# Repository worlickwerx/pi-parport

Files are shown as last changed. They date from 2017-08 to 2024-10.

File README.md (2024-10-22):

## pi-parport

This is a Raspberry Pi HAT that implements a PC-style parallel port.
GPIO pins are organized as data, status, and control registers.
The HAT includes a buffer chip that converts from the GPIB 3V3 logic
to signals that conform to IEEE 1284.  A 26 pin IDC header on the
board connects to your DB25 connector.  A `parport-gpio` driver and
device tree overlay integrate the HAT with the Linux parport driver stack.

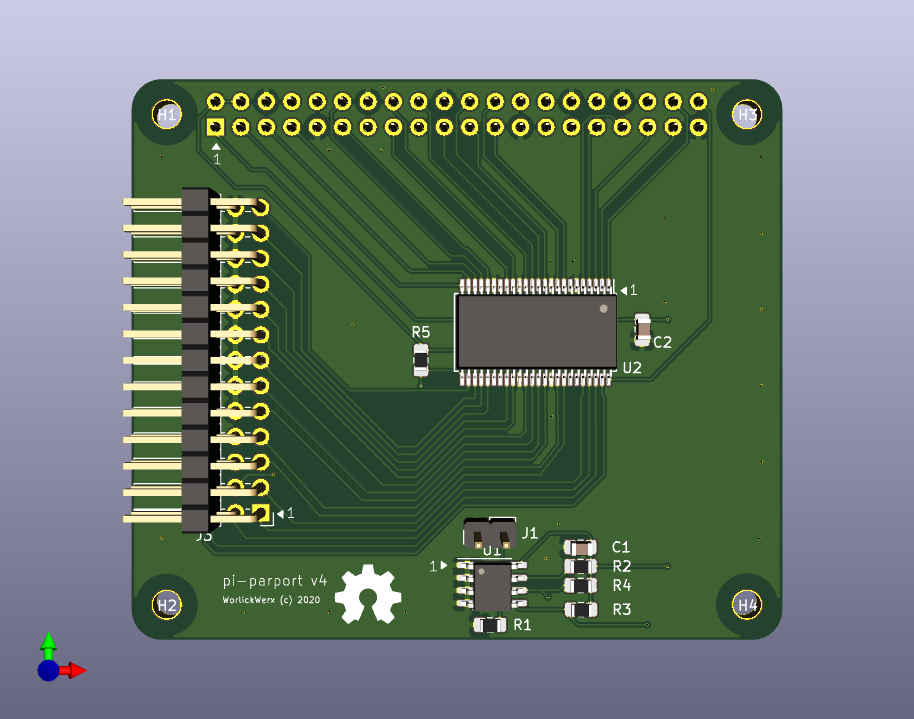
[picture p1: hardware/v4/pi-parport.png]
Image of pi-parport latest


### Why?

I wanted to use a parallel port based cooled astronomy camera,
but preferred to use the compact and low-power Raspberry Pi
over a PC at the telescope.  Parallel ports are simple devices.
Why not build one?

### What works?

See [wiki](https://github.com/worlickwerx/pi-parport/wiki) for notes on some
devices, and please share your experience if you try something new.

The following limitations of this implementation may affect software and
hardware that uses the parallel port:
1) The software cannot directly read and write the x86 port addresses,
as was the custom early on.  In user space, software must use the ppdev
ioctl interface.  In the kernel, software must use the (generic)
`struct parport` operations.
2) The GPIO multiplexing/de-multiplexing and/or system call access may
impact the direct-access latency assumed by some bit-banged drivers.
On a Pi 3, user space code can toggle a parallel port line at about 250 kHz.
3) Bidirectional control pins are not currently supported, but bidirectional
data pins are supported.  There are alternatives to the current buffer chip
that would support this, but they require a slightly more complicated
circuit.

### Why not use a USB Parallel Port?

Many USB parallel port devices appear to Linux as a USB printer, bypassing
the parport driver stack.  If your application is a printer, go for it.

### Building the driver

For convenience, the generic parport code is duplicated in this repo,
since the Raspberry Pi Foundation does not ship the compiled modules
in the `raspberrypi-kernel` package (at least in old Raspbian
versions).  If you are intending to use a specific old version of
Raspbian, there is the shell script `get_parport_src.sh` to assist
you in getting the code from that particular version.

Clone this repo, then run the following with `${TOPDIR}` representing the
top level directory of the cloned repo:
```console
$ sudo apt install build-essential raspberrypi-kernel-headers
$ cd ${TOPDIR}/driver
$ make
make -C /lib/modules/4.19.75-v7+/build M=${TOPDIR}/driver modules
make[1]: Entering directory '/usr/src/linux-headers-4.19.75-v7+'
  CC [M]  ${TOPDIR}/driver/parport/share.o
  CC [M]  ${TOPDIR}/driver/parport/ieee1284.o
  CC [M]  ${TOPDIR}/driver/parport/ieee1284_ops.o
  CC [M]  ${TOPDIR}/driver/parport/procfs.o
  CC [M]  ${TOPDIR}/driver/parport/daisy.o
  CC [M]  ${TOPDIR}/driver/parport/probe.o
  LD [M]  ${TOPDIR}/driver/parport/parport.o
  CC [M]  ${TOPDIR}/driver/parport/lp.o
  CC [M]  ${TOPDIR}/driver/parport/ppdev.o
  CC [M]  ${TOPDIR}/driver/parport_gpio.o
  Building modules, stage 2.
  MODPOST 4 modules
  CC      ${TOPDIR}/driver/parport/lp.mod.o
  LD [M]  ${TOPDIR}/driver/parport/lp.ko
  CC      ${TOPDIR}/driver/parport/parport.mod.o
  LD [M]  ${TOPDIR}/driver/parport/parport.ko
  CC      ${TOPDIR}/driver/parport/ppdev.mod.o
  LD [M]  ${TOPDIR}/driver/parport/ppdev.ko
  CC      ${TOPDIR}/driver/parport_gpio.mod.o
  LD [M]  ${TOPDIR}/driver/parport_gpio.ko
make[1]: Leaving directory '/usr/src/linux-headers-4.19.75-v7+'
```

### Installing the Device Tree Overlay

The device tree overlay maps specific GPIO pins to their functions in
the driver.  This must be compiled and loaded:
```console
$ cd ${TOPDIR}/dts
$ make
$ sudo make install
```
The ID EEPROM stores the name of the DT Overlay to use, and the
corresponding DT Overlay will be automatically loaded on boot.  If you
will not be using an ID EEPROM, then add the following line to
`/boot/config.txt`:
```
dtoverlay=parport-gpio
```
The default drive mode of the parallel port output pins is
"totem-pole" mode, which means that a high current source is provided
for both logic level 1 and 0.  If you wish logic level 1 to be a low
current source provided by pull-up resistors, i.e. "open-drain" mode,
then you can set the following DT Overlay parameter:
```
dtoverlay=parport-gpio,hd=0
```
Note that if you are using an EEPROM, you will have to include the
full DT Overlay data within your EEPROM since you cannot simply
specify a parameter when loading by that method.

Then reboot the pi to pick up the new config.

### Installing the Modules

Install the modules to allow Linux Device Tree to automatically load
them.
```console
$ cd ${TOPDIR}/driver
$ sudo make install
```
Note that only the `parport` and `parport_gpio` base modules will
autoload, the `ppdev` and `lp` modules will still need to be specified
in `/etc/modules` or otherwise.  Also, note that you will need to
rebuild and reinstall the modules when you update your kernel version.

### Loading the Modules

If you did not install the modules, after rebooting, load the base
modules like this:
```console
$ cd ${TOPDIR}
$ sudo insmod driver/parport/parport.ko
$ sudo insmod driver/parport_gpio.ko
```
You'll see the port announce itself on the console:
```console
[4425200.988400] parport-gpio ppgpio@0: data on pins [22,23,24,10,25,9,8,11]
[4425200.988412] parport-gpio ppgpio@0: status on pins [18,17,4,3,2]
[4425200.988422] parport-gpio ppgpio@0: control on pins [26,19,6,13]
[4425200.988430] parport-gpio ppgpio@0: hd on pin 20
[4425200.988438] parport-gpio ppgpio@0: dir on pin 21
```
If you wish to set up a parallel printer:
```console
$ sudo insmod parport/lp.ko
```
If you wish to run user-space programs that use the parallel port:
```console
$ sudo insmod parport/ppdev.ko
```

### hardware

The latest hardware includes an ID EEPROM to conform with the
[Raspberry Pi HAT Specification](https://github.com/raspberrypi/hats),
and was designed with [KiCAD](https://www.kicad.org/).
As with the previous versions, the
[SN74LVC161284 19-bit bus interface with 3-state outputs](http://www.ti.com/product/SN74LVC161284) takes care of buffering and line conditioning.

Version 4 is shared on
[OSHPARK](https://oshpark.com/shared_projects/0Ioh20Gk).
See the [Bill of Materials](hardware/v4/BOM.md) for parts to place on
the board.

Populating the EEPROM and associated components on a board you're making
yourself is optional.

Check out the [test](test/) directory for some simple "smoke tests"
on your assembled pi-parport board before attaching your more
expensive equipment.

Schematics and design files for [previous versions](hardware/)
are still available for reference.

### Release

Share and enjoy!

#### Software License

SPDX-License-Identifier: GPL-2.0-or-later

#### Hardware License

SPDX-License-Identifier: CERN-OHL-1.2

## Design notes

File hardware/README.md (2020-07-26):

### v4 hardware

v4 mainly corrects some minor flaws in the v3 design.  Bypass
capacitors are added, a few traces are rerouted to avoid passing under
resistors, and the footprints for the EEPROM resistors are changed
from 0603 to 0805.  Also, a few CAD-related inconsistencies were
fixed, like unclosed board outline and footprints not being consistent
between the schematic and board layout files.

[Schematic](v4/pi-parport.pdf) and [Bill of Materials](v4/BOM.md).

### v3 hardware

v3 adds an EEPROM to be a proper HAT.  It also converts the design files 
from Eagle to KiCad as a step to making additional board variations and 
modifications more accessible.  Unfortunately, bypass capacitors were 
left out of the redesign.

This board is shared on [OSHPARK](https://oshpark.com/shared_projects/gevwv2YP).
See also:  [Schematic](v3/pi-parport.pdf) and [Bill of Materials](v3/BOM.md).

### v2 hardware

v2 addresses the line termination and data direction limitations of v1,
using a single, purpose-built chip, the
[SN74LVC161284 19-bit bus interface with 3-state outputs](http://www.ti.com/product/SN74LVC161284).

This board was designed with Eagle, and is shared on
[OSHPARK](https://oshpark.com/shared_projects/Padn3qhP).
See also: [Schematic](v2/schematic.pdf) and [Bill of Materials](v2/BOM.md).

It works!  However, it doesn't conform to the HAT specification because
of the lack of EEPROM, and the IDC connector footprint is for a vertical
connector, but right angle would have helped the Pi fit into smaller cases.
(RA works, but it hangs over the board edge).

### v1 hardware

Three
[74AHCT541 octal buffers/drivers with 3-state outputs](http://www.ti.com/product/SN74AHCT541)
chips convert to/from the Pi's 3V3 line level and the parallel port's 5V.

This board was designed with Eagle.  See also: [Schematic](v1/schematic.pdf).

This version worked for my intended application (SBIG parallel port camera),
but due to missing line termination, only with a very short cable.  This
design also does not implement bidirectional DATA.

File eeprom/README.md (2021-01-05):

### ID EEPROM

Install J1 (or solder a zero-ohm resistor in R1) to defeat EEPROM
write protect.

To use and program your EEPROM, ensure that `/etc/modules` contains
`i2c-dev`.  This is normally the case if you have a full installation
of Raspbian, but if you've opted for a lite installation or a
different operating system, this line might be missing.  Add it and
ensure the module is loaded by typing `sudo modprobe i2c-dev`.

Edit `/boot/config.txt`, adding this line temporarily so the ID bus is visible
after boot, and reboot:
```
# Enable ID EEPROM temporarily
dtparam=i2c_vc=on
```

Verify EEPROM is found on bus 0 at address 50
```console
$ sudo apt install i2c-tools
$ i2cdetect 0
WARNING! This program can confuse your I2C bus, cause data loss and worse!
I will probe file /dev/i2c-0.
I will probe address range 0x03-0x77.
Continue? [Y/n] y
     0  1  2  3  4  5  6  7  8  9  a  b  c  d  e  f
00:          -- -- -- -- -- -- -- -- -- -- -- -- --
10: -- -- -- -- -- -- -- -- -- -- -- -- -- -- -- --
20: -- -- -- -- -- -- -- -- -- -- -- -- -- -- -- --
30: -- -- -- -- -- -- -- -- -- -- -- -- -- -- -- --
40: -- -- -- -- -- -- -- -- -- -- -- -- -- -- -- --
50: 50 -- -- -- -- -- -- -- -- -- -- -- -- -- -- --
60: -- -- -- -- -- -- -- -- -- -- -- -- -- -- -- --
70: -- -- -- -- -- -- -- --
```

Make the HAT EEPROM utils and copy `eepmake`, `eepdump`, and `eepflash.sh`
somewhere in your PATH (like `/usr/local/bin`).
```console
$ git clone https://github.com/raspberrypi/hats.git
$ cd hats/eepromutils
$ make
$ sudo cp eepflash.sh eepdump eepmake /usr/local/bin/
```

Back in this directory, make the image and flash the chip:
```console
$ make VERSION=0x0004
eepmake board.txt board.eep overlay_name.txt
Opening file board.txt for read
UUID=3691bbab-1f52-42c7-9cac-01fc81d12688
Done reading
Opening DT file overlay_name.txt for read
Adding 13 bytes of DT data
Writing out...
Writing out DT...
Done.
$ make flash
sudo eepflash.sh -w -f=board.eep -t=24c32 -d=0 -a=50
This will attempt to talk to an eeprom at i2c address 0x50 on bus 0. Make sure there is an eeprom at this address.
This script comes with ABSOLUTELY no warranty. Continue only if you know what you are doing.
Do you wish to continue? (yes/no): yes
Writing...
0+1 records in
0+1 records out
105 bytes copied, 0.388654 s, 0.3 kB/s
Closing EEPROM Device.
Done.
```
Please note: Earlier versions of Raspbian are not compatible with the
method of storing the name of the DT Overlay in EEPROM, they only
support a DT Overlay embedded directly.  So, if you wish to use
pi-parport with one of these, add `EMBED_DTBO=1` to the make command
line.

Edit `/boot/config.txt`, removing the line added above, then reboot.
Then, again from this directory, run:
```console
$ make verify
vendor:      WorlickWerx
product:     pi-parport
product_id:  0x0001
product_ver: 0x0003
uuid:        3691bbab-1f52-42c7-9cac-01fc81d12688
```

Yay it's a HAT.

References:

[Sparkfun i2c tutorial](https://learn.sparkfun.com/tutorials/raspberry-pi-spi-and-i2c-tutorial/i2c-0-on-40-pin-pi-boards)

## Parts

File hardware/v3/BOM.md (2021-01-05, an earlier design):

## hardware v3 bill of materials

These are the parts on the board from the schematic.  All of them can
be ordered from [Digi-Key](https://www.digikey.com/) together in one
shipment.

| Quantity | Reference | Digi-Key_PN | MPN | Manufacturer | Package | Description | Notes |
| --- | --- | --- | --- | --- | --- | --- | --- |
| 1 | J1 | 952-2262-ND | M20-9990246 | Harwin Inc. | through-hole (2.54mm pitch) | 2x1 male header | Install J1 jumper to defeat EEPROM write protect |
| 1 | J2 | S7123-ND | PPPC202LFBN-RC | Sullins Connector Solutions | through-hole (2.54mm pitch) | 20x2 female header | pi GPIO header |
| 1 | J3 | 609-3349-ND | 68021-226HLF | Amphenol ICC (FCI) | through-hole (2.54mm pitch) | 13x2 male header 90 degree | Straight or 90 degree depending on application |
| 1 | R2 | P10.0KCCT-ND | ERJ-6ENF1002V | Panasonic Electronic Components | 0805 | 10K, 1/8 watt resistor | Pull-up for EEPROM write protect |
| 2 | R3 R4 | P3.90KCCT-ND | ERJ-6ENF3901V | Panasonic Electronic Components | 0805 | 3.9K, 1/8 watt resistor | Pull-ups for ID EEPROM |
| 1 | R5 | P1.40KCCT-ND | ERJ-6ENF1401V | Panasonic Electronic Components | 0805 | 1.4K ohm, 1/8 watt resistor | Pull-up for STATUS3 |
| 1 | U1 | CAT24C32WI-GT3CT-ND | CAT24C32WI-GT3 | ON Semiconductor | 8-SOIC | I2C Serial EEPROM 32Kb | ID EEPROM |
| 1 | U2 | 296-8467-5-ND | SN74LVC161284DL  | Texas Instruments | 48-SSOP (0.64mm lead pitch) | 19-bit bus interface with 3-state outputs | pin 1 marking oriented opposite J3 |

One capacitor was accidentally omitted from the v3 design and has yet
to be added.  (See issue #28.)  In the intermin, a suitable component
is listed here, though it cannot be used yet.

| Quantity | Reference | Digi-Key_PN | MPN | Manufacturer | Package | Description | Notes |
| --- | --- | --- | --- | --- | --- | --- | --- |
| 1 | C1 | 399-1177-1-ND | C0805C104Z5VACTU | KEMET | 0805 | 100nF, 50V capacitor | Bypass |

Additional board components, depends on needs:

| Quan | Description | Supplier | Notes |
| ---- | --- | --- | ----- |
| 1 | DIP jumper  | [Digi-Key](https://www.digikey.com/en/products/detail/sullins-connector-solutions/QPC02SXGN-RC/2618262) | |
| 4 | M2.5 x 16mm brass standoff, with M2.5 nut | [Adafruit](https://www.adafruit.com/product/2336) | pi HAT standoff (height 11mm) |
| 4 | M2.5 x 6mm philips head screw | | |
| 1 | Female DB25 to female 13x2 header cable assembly | [Amazon](https://www.amazon.com/Motherboard-Parallel-Printer-bracket-socket/dp/B00PI5XF4U) | or surplus |

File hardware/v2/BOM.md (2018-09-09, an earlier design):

## hardware v2 bill of materials

| Quan | Part no | Manuf part no | Description | Package | Supplier | Notes |
| ---- | --- | --- | --- | --- | --- | ----- |
| 1 | U1 | [SN74LVC161284DLR](http://www.ti.com/product/SN74LVC161284) | 19-bit bus interface with 3-state outputs | SSOP (0.64mm lead pitch) | [Arrow Electronics](https://www.arrow.com/en/products/sn74lvc161284dlr/texas-instruments) | pin 1 marking oriented opposite J1 |
| 1 | R1 | | 1.4K ohm, 1/8 watt resistor | 0805 | | Pull-up for STATUS3 |
| 1 | C2 | | 100nF, 50V capacitor | 0805 | | Bypass |
| 1 | J1 | | 13x2 male header | through-hole (2.54mm pitch) | | Straight or 90 degree depending on application |
| 1 | K1 | | 20x2 female header | through-hole (2.54mm pitch) | [Adafruit](https://www.adafruit.com/product/2222) | pi GPIO header |
| 4 | | | M2.5 x 16mm brass standoff, with M2.5 nut | | [Adafruit](https://www.adafruit.com/product/2336) | pi HAT standoff (height 11mm) |
| 4 | | | M2.5 x 6mm philips head screw | | | |
| 1 | | | Female DB25 to female 13x2 header cable assembly | | [Amazon](https://www.amazon.com/Motherboard-Parallel-Printer-bracket-socket/dp/B00PI5XF4U) | or surplus |

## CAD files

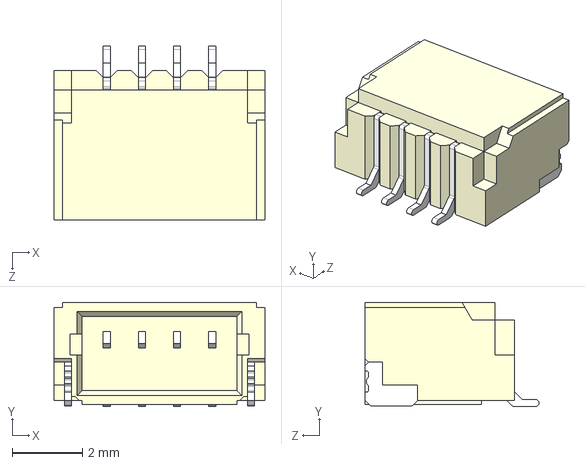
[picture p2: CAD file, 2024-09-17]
hardware/v5/3d/PRT-14417.step
6.00 x 2.96 x 4.95 mm

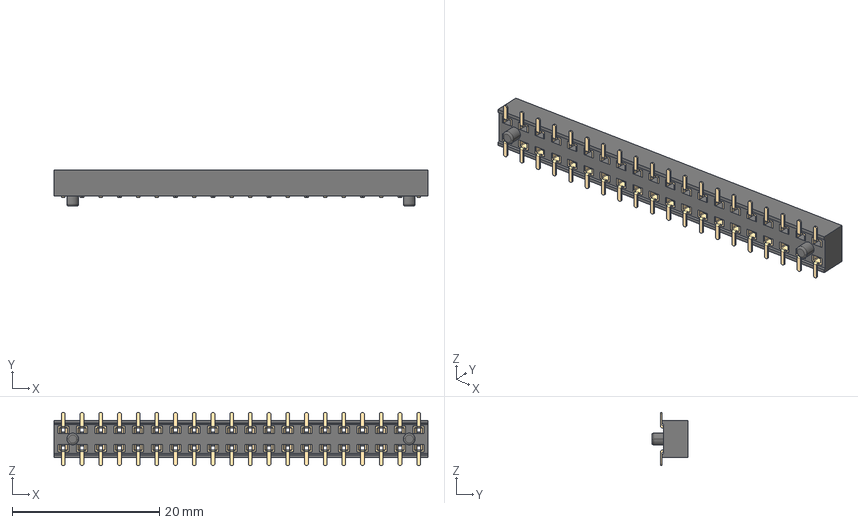
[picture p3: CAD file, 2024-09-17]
hardware/v5/3d/M20-7812045.step
50.8 x 4.95 x 7.20 mm

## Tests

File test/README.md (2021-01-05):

## Testing

These tests primarily check that the bits aren't shorted, open,
or misrouted, and the the DTS overlay is properly configured.
Ensure that the `ppdev` module is loaded before running these
tests.

### loop - plug A

`loop A` utilizes a DB25 loopback plug wired as below.

| Pin | Name | Pin | Name |
| --- | --- | --- | --- |
| 3 | DATA1 | 14  | CONTROL1 |
| 4 | DATA2 | 15  | STATUS3  |
| 5 | DATA3 | 17  | CONTROL3 |
| 6 | DATA4 | 13  | STATUS4  |
| 7 | DATA5 | 12  | STATUS5  |
| 8 | DATA6 | 10  | STATUS6  |
| 9 | DATA7 | 11  | STATUS7  |

**phase 1** DATA is configured for output.
Each of 256 possible output values is placed in the DATA register,
then the STATUS register is read.  The bits from DATA[2,4:7] must appear
on STATUS[3:7].

**phase 2** DATA is configured for input.
Each of 16 possible control values is placed in the CONTROL register,
then the DATA register is read.  The bits from CONTROL[1,3] must appear
on DATA[1,3].

### loop - plug B

`loop B` utilizes a DB25 loopback plug wired as below.
It covers the pins missed by plug A.

| Pin | Name | Pin | Name |
| --- | --- | --- | --- |
| 2 | DATA0 | 1 | CONTROL0 |
| 4 | DATA2 | 16  | CONTROL2 |

DATA is configured for input.
Each of 16 possible control values is placed in the CONTROL register,
then the DATA register is read.  The bits from CONTROL[0,2] must appear
on DATA[0,2].

### strobe

`strobe pin [period]` simply toggles a selected pin at a target period
so it can be scoped.  This is useful for debugging if the loop tests fail.

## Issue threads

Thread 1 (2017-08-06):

Unable to handle kernel NULL pointer dereference at virtual address 00000000

garlick, 2017-08-06:
When parport stack is built with CONFIG_PARPORT_1284, we get an oops when the `parport_gpio.ko` module is loaded:
```
[   33.805294] parport: loading out-of-tree module taints kernel.
[   44.416949] parport_gpio: data on gpio pins [22,23,24,10,25,9,8,11]
[   44.416962] parport_gpio: status on gpio pins [18,17,4,3,2]
[   44.416969] parport_gpio: control on gpio pins [26,19,6,13]
[   44.417113] Unable to handle kernel NULL pointer dereference at virtual address 00000000
[   44.421524] pgd = b7170000
[   44.423451] [00000000] *pgd=00000000
[   44.425522] Internal error: Oops: 805 [#1] SMP ARM
[   44.427533] Modules linked in: parport_gpio(O+) parport(O) bnep hci_uart btbcm bluetooth brcmfmac brcmutil cfg80211 rfkill bcm2835_gpiomem uio_pdrv_genirq fixed uio ipv6
[   44.434186] CPU: 0 PID: 794 Comm: insmod Tainted: G           O    4.9.35-v7+ #1014
[   44.438719] Hardware name: BCM2835
[   44.441010] task: b8dd8000 task.stack: b93ea000
[   44.443363] PC is at cpp_mux+0x38/0x164 [parport]
[   44.445718] LR is at parport_daisy_init+0x41c/0x548 [parport]
[   44.448074] pc : [<7f36775c>]    lr : [<7f367df4>]    psr: a0000013
sp : b93ebbe0  ip : b93ebc00  fp : b93ebbfc
[   44.452899] r10: 0000001a  r9 : 00000013  r8 : 7f36a708
[   44.455318] r7 : 809b51c4  r6 : 00000051  r5 : b92bb800  r4 : 00000000
[   44.457766] r3 : 00000080  r2 : 000000f1  r1 : b8fef140  r0 : b92bb800
[   44.460222] Flags: NzCv  IRQs on  FIQs on  Mode SVC_32  ISA ARM  Segment user
[   44.462770] Control: 10c5383d  Table: 3717006a  DAC: 00000055
[   44.465266] Process insmod (pid: 794, stack limit = 0xb93ea210)
[   44.467409] Stack: (0xb93ebbe0 to 0xb93ec000)
[   44.468655] bbe0: 80d047d0 b92bb800 b92bb800 00000000 b93ebc4c b93ebc00 7f367df4 7f367730
[   44.471237] bc00: b92bb828 b8fef680 000001f4 00000000 b93ebc34 b93ebc20 7f368fec 80d047d0
[   44.473876] bc20: b93ebc30 b92bb800 b8fef140 b9a1e810 b9a1e800 00000006 00000013 0000001a
[   44.476535] bc40: b93ebc64 b93ebc50 7f3637b0 7f3679e4 00000000 b8fef140 b93ebcbc b93ebc68
[   44.479277] bc60: 7f3757f4 7f3637a0 0000000d 00000002 00000009 00000008 0000000b b93ebc88
[   44.482183] bc80: 00000016 00000017 00000018 00000012 7f375e2c 80d10558 b9a1e810 7f375e2c
[   44.485209] bca0: fffffdfb 00000010 48dc46dc 00000000 b93ebcdc b93ebcc0 804fc95c 7f3754b4
[   44.488343] bcc0: 80d10558 b9a1e810 00000000 7f375e2c b93ebd04 b93ebce0 804faf04 804fc90c
[   44.491639] bce0: 00000000 b9a1e810 7f375e2c b9a1e844 00000000 00000001 b93ebd24 b93ebd08
[   44.495018] bd00: 804fb06c 804facf0 804fafb0 00000000 7f375e2c 804fafb0 b93ebd4c b93ebd28
[   44.498480] bd20: 804f8ed8 804fafbc b98a1a5c b99b70b4 b98a1a70 7f375e2c b8eda180 80c55048
[   44.501987] bd40: b93ebd5c b93ebd50 804fa884 804f8e68 b93ebd84 b93ebd60 804fa41c 804fa864
[   44.505486] bd60: 7f375d68 b93ebd70 7f375e2c 7f378000 b723ba00 7f375e80 b93ebd9c b93ebd88
[   44.508991] bd80: 804fb764 804fa274 7f375e80 7f378000 b93ebdac b93ebda0 804fc8ac 804fb6e8
[   44.512498] bda0: b93ebdbc b93ebdb0 7f37801c 804fc868 b93ebe3c b93ebdc0 80101bf0 7f37800c
[   44.516001] bdc0: 00000000 393eb000 8022cf98 b8f39580 000055b1 393eb000 8024e8dc b8f39e80
[   44.519502] bde0: 000055b1 8025e3f4 b93ebe3c b93ebdf8 8025e3f4 80714eec 8025f7b4 8025ec58
[   44.522996] be00: 00000001 000055b1 b723ba40 a0000013 bc3e3000 7f375e80 00000001 b723ba00
[   44.526502] be20: 7f375e80 00000001 48dc46dc b723b948 b93ebe64 b93ebe40 80209e24 80101bac
[   44.530009] be40: b93ebe64 b93ebe50 8024e9d0 b93ebf3c 00000001 b723b940 b93ebf14 b93ebe68
[   44.533514] be60: 801a34ac 80209dbc 7f375e8c 00007fff 7f375e80 801a0b90 b93ebea4 7f37606c
[   44.537020] be80: bc3e48c4 7f378df0 7f376080 00000000 7f375f94 7f375ec8 b93ebee4 b93ebea8
[   44.540524] bea0: 80276c10 80276a90 bc3e3000 00000000 00000000 00000000 00000000 00000000
[   44.544034] bec0: 00000000 00000000 00000000 00000000 00000000 00000000 00000000 00000000
[   44.547544] bee0: 00000000 00000000 7fffffff 00000000 00000003 54ba53b0 0000017b 7fffffff
[   44.551057] bf00: 00000000 00000000 b93ebfa4 b93ebf18 801a3dc4 801a1aec 7fffffff 00000000
[   44.554562] bf20: 00000003 8022d144 b93ebf74 bc3e3000 00003514 00000000 00000002 bc3e3000
[   44.558073] bf40: 00003514 bc3e5fc4 bc3e4a2f bc3e5320 00001080 000013b0 00000000 00000000
[   44.561586] bf60: 00000000 00000df0 00000020 00000021 00000019 00000016 00000012 00000000
[   44.565099] bf80: 0000017b ca083500 54bb7000 7e955838 80108244 b93ea000 00000000 b93ebfa8
[   44.568614] bfa0: 801080c0 801a3d34 ca083500 54bb7000 00000003 54ba53b0 00000000 00000002
[   44.572117] bfc0: ca083500 54bb7000 7e955838 0000017b 54ba53b0 00000002 54ba120c 00000000
[   44.575623] bfe0: 7e955670 7e955660 54b9a0ac 76e99c40 60000010 00000003 00000000 00000000
[   44.579175] [<7f36775c>] (cpp_mux [parport]) from [<7f367df4>] (parport_daisy_init+0x41c/0x548 [parport])
[   44.582742] [<7f367df4>] (parport_daisy_init [parport]) from [<7f3637b0>] (parport_announce_port+0x1c/0x124 [parport])
[   44.586317] [<7f3637b0>] (parport_announce_port [parport]) from [<7f3757f4>] (parport_gpio_probe+0x34c/0x3cc [parport_gpio])
[   44.589887] [<7f3757f4>] (parport_gpio_probe [parport_gpio]) from [<804fc95c>] (platform_drv_probe+0x5c/0xc0)
[   44.593455] [<804fc95c>] (platform_drv_probe) from [<804faf04>] (driver_probe_device+0x220/0x2cc)
[   44.597016] [<804faf04>] (driver_probe_device) from [<804fb06c>] (__driver_attach+0xbc/0xc0)
[   44.600580] [<804fb06c>] (__driver_attach) from [<804f8ed8>] (bus_for_each_dev+0x7c/0xb0)
[   44.604139] [<804f8ed8>] (bus_for_each_dev) from [<804fa884>] (driver_attach+0x2c/0x30)
[   44.607704] [<804fa884>] (driver_attach) from [<804fa41c>] (bus_add_driver+0x1b4/0x22c)
[   44.611283] [<804fa41c>] (bus_add_driver) from [<804fb764>] (driver_register+0x88/0x108)
[   44.614871] [<804fb764>] (driver_register) from [<804fc8ac>] (__platform_driver_register+0x50/0x58)
[   44.618477] [<804fc8ac>] (__platform_driver_register) from [<7f37801c>] (parport_gpio_driver_init+0x1c/0x24 [parport_gpio])
[   44.622102] [<7f37801c>] (parport_gpio_driver_init [parport_gpio]) from [<80101bf0>] (do_one_initcall+0x50/0x184)
[   44.625724] [<80101bf0>] (do_one_initcall) from [<80209e24>] (do_init_module+0x74/0x1e4)
[   44.629325] [<80209e24>] (do_init_module) from [<801a34ac>] (load_module+0x19cc/0x2108)
[   44.632921] [<801a34ac>] (load_module) from [<801a3dc4>] (SyS_finit_module+0x9c/0xac)
[   44.636514] [<801a3dc4>] (SyS_finit_module) from [<801080c0>] (ret_fast_syscall+0x0/0x1c)
[   44.640100] Code: e20330df e0033002 f57ff04e e3a04000 (e5c43000)
[   44.642034] ---[ end trace 9426328261f131a2 ]---
```

Closed 2017-08-06.

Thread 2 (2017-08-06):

implement IRQ on low to high nACK transition

garlick, 2017-08-06:
The optional parallel port interrupt is supposed to be generated on a low to high transition on pin 10 (nACK).

http://www.makelinux.net/ldd3/chp-10-sect-1

http://retired.beyondlogic.org/spp/parallel.htm

See `gpiod_to_irq()`
https://www.kernel.org/doc/Documentation/gpio/consumer.txt

andersmilton, 2019-09-09:
Do you have any plans to incorporate interrupts in the driver? I have a project in mind that surely could use it, but I don't know anything about writing linux drivers :)

garlick, 2019-09-09:
I don't think it will be that difficult.  The main thing holding me back was having a compelling use case and some plan for testing.  What's your project if you don't mind me asking?

andersmilton, 2019-09-09:
I'm thinking of building a Pi Zero hat version of the XA1541 cable for communicating with old Commodore disk drives :D

I'm literally just thinking about it at the moment. I'm not sure it will ever be built, but it should be easy hardware-wise, and the software exists.

quorten, 2020-11-01:
A suitable test case for this is rather easy, the `lp` driver for printing via parallel port requires nACK to know when to send the next character.  Without interrupts, it resorts to polling.  This works fine for this particular driver, but I believe other for device drivers like cheat cartridges it may cause issues.

So, I think I might get into adding this feature and testing it.

garlick, 2024-08-29:
Oh this might be something we ought to add to the v5 board proposed in #68.  I've kind of flushed my cache on how parallel port interrupts supposed to work.   A little study required on my part I guess.

garlick, 2024-08-29:
Actually, I guess apart from making sure that nACK is assigned to a GPIO pin that can trigger an interrupt, this is a software problem not a hardware one.  It's GPIO27 in v5 and GPIO17 in older versions.  AFAICT all pi gpio pins are capable of generating an interrupt on either low to high or high to transition.

So never mind.  No hardware support needed.

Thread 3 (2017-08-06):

how to properly initialize gpio polarity?

garlick, 2017-08-06:
Operating through the gpiod consumer interface, there doesn't seem to be a way to set the polarity (active high versus active low) of a GPIO line.

I couldn't find a way to do it in the device tree overlay either.

Since gpiod lines on the pi seem to come to us in different states, the `parport-gpio` driver bypasses the polarity abstraction in the consumer  gpiod interface and uses the "raw" functions, which the consumer docs warn should not be used.

What is the right way to initialize the polarity of GPIO lines?

garlick, 2017-08-07:
This device tree overlay for the `gpio-poweroff` kernel module manages to have an `active_low` override:

```
/ Definitions for gpio-poweroff module
/dts-v1/;
/plugin/;

/ {
        compatible = "brcm,bcm2708";

        fragment@0 {
                target-path = "/";
                __overlay__ {
                        power_ctrl: power_ctrl {
                                compatible = "gpio-poweroff";
                                gpios = <&gpio 26 0>;
                                force;
                        };
                };
        };

        fragment@1 {
                target = <&gpio>;
                __overlay__ {
                        power_ctrl_pins: power_ctrl_pins {
                                brcm,pins = <26>;
                                brcm,function = <1>; // out
                        };
                };
        };

        __overrides__ {
                gpiopin =       <&power_ctrl>,"gpios:4",
                                <&power_ctrl_pins>,"brcm,pins:0";
                active_low =    <&power_ctrl>,"gpios:8";
        };
};
```

Closed 2017-08-07.

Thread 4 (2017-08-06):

re-order GPIO lines sequentially so they can be set in parallel

garlick, 2017-08-06:
The `parport-gpio` driver calls `gpiod_set_raw_array_value()` to set all the GPIO lines in a port (data, control) at once.  The docs say that one should put the GPIO lines in numerical order in the array in order to allow for the lower level code to optimize I/O.  I didn't do that because I wasn't sure it would matter, and it would complicate board layout.

Do an experiment to see if that's worth it.

Issue data port writes of 0xff, 0x00, 0xff, 0x00, ... in a tight loop and measure timing on the staggering of bit transitions with MSO.  Then try again with the bits in the device tree overlay sorted numerically (ignoring the incorrect bit mapping).

If it produces better timing, lay out v2 of the board differently.

andrewtubbiolo, 2019-04-25:
Oh thank goodness I was not nuts. I'm going to use this on a SBIG ST-8, or try to, and I wanted to free up GPIO's 2 and 3 to install a hardware RTC for accurate time stamps. It was then that I noticed that the GPIO pins were set out to allow for a "almost" single layer board layout. I went looking for the 'data mangle' code that would take sequential data for the Data, Control, and Status words/nibbles and translate them to the layout order. I never found it. Did I miss something, or was it up to the user to do that themselves in their application?

garlick, 2019-04-25:
Actually you can specify any GPIO to function mapping you like in the [device tree overlay file](https://github.com/garlick/pi-parport/blob/master/dts/parport-gpio.dts).

The [driver](https://github.com/garlick/pi-parport/blob/master/driver/parport_gpio.c) just uses whatever is presented by the device tree.

This issue was questioning the generic kernel GPIO code just did one I/O operation per bit no matter what, or if it could do better if bits could be packed into one GPIO register (say).  Ultimately I didn't get around to testing this because my particular application (same as yours, albeit with smaller CCDs, yay!) "just worked" reliably.

Anyway, if you want to change the pin assignments on your board, just tweak the DTS file.  Good luck and please let me know how it goes!

BTW, a revision of this board with an RTC and battery on it would be pretty neat for working in the field!

andrewtubbiolo, 2019-04-25:
Hello Mr Garlick:

   Thanks for the fast reply! And thanks for the pointer to the device
tree. I was brute force going thru the C flies looking for the bit shifts
and masks to deal with the layout. I don't suppose you've tried TDI (Time
Delay Integration) aka sidereal strip scanning, where each CCD row is read
out at the rate the night sky walks across the imaging array while the
tracking is turned off? I was afraid I'd have to use a FPGA or maybe an
arduino to get the timing, but then a friend came across your project, and
I'm going to give it a try.

  I'd be happy to add a RTC enabled board to your project.

Thanks.
Andrew

On Thu, Apr 25, 2019 at 2:42 PM Jim Garlick <notifications@github.com>
wrote:

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

garlick, 2019-04-26:
I haven't tried it (yet) but don't the SBIG cameras support TDI natively (they call it "drift scan imaging")?

I seem to recall that their SDK offers a way to clock the CCD row by row in support of TDI....

garlick, 2019-04-26:
See also garlick/sbig-util#17.  There are some SBIG references there.

andrewtubbiolo, 2019-04-26:
CCD OPS in windows does indeed allow you to do TDI. I'll use it for
surveying, and I've tested it a few nights with very good results. However,
I'm not sure if the PC does the sidereal rate shifting and readout, or if
it's done on camera. Part of this long term project will be to make a hand
wired board to allow my logic analyser test points to probe waveforms.

Andrew

On Thu, Apr 25, 2019 at 5:09 PM Jim Garlick <notifications@github.com>
wrote:

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

garlick, 2019-04-26:
I think the older cameras have very little brain between the analog board and the PC and possibly CCD OPS could do TDI by just keeping the shutter open and requesting a line at a time from the camera with appropriate delays depending on pixel size and focal length.  In other words the older digital board may not even try to get a uniform integration by reading out the whole image quickly and buffering it.

According to the SDK manual some support was added to disable buffering in the USB cameras to support TDI.  Later, support was also added for TDI on the interline CCDs which I think have a whole different readout strategy compared to full frame.

Finally the SDK manual mentions something about "biorad TDI acquisition mode" which is a queryable camera feature, though I don't know what it means or if it's required for all cameras in order to do TDI (my guess is not - maybe it has to do with interline support).

garlick, 2020-01-02:
Closing as I don't think the original issue is a thing.  Reopen if it is.

quorten, 2020-11-11:
Just wanted to comment, I also really like the idea of an board variant with an RTC on it too.  Probably the best way to do this is with a single AVR microcontroller on the ID EEPROM I2C bus that acts as both an ID EEPROM and a RTC: you simply access the proper memory address to read/write the current time register.  The 32.768kHz watch crystal clocks an asynchronous timer in the AVR.  There would also be a 1-second interrupt pin too... that's important but unfortunately missing from some other Raspberry Pi RTC HATs because the SoC 19.2MHz oscillator has considerable long-term timing instability.

Closed 2020-01-02.

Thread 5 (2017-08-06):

optimize frob_control operation

garlick, 2017-08-06:
The `parport_gpio_frob_control()` op callback has two problems

1) it returns the original value of the control register.  Need to verify that's what it's supposed to do or if it matters (does anyone read the result?)  Some drivers do what we're doing, others return new control register value.
2) we read and write all four lines unconditionally, but presumably the main use case is to frob one line at a time; for the GPIO implementation, we probably should only frob bits present in the `mask` argument

Closed 2017-08-06.

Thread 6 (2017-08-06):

print to HP printer

garlick, 2017-08-06:
Test if the v1 hardware can actually be used for printing.  We can't reasonably claim to have integrated with the parport stack without having completed this experiment successfully.

I happen to have an old [HP Deskjet 1220C](http://www.farnell.com/datasheets/17727.pdf)  printer that has both 36-pin parallel and USB interfaces.

garlick, 2017-08-06:
Built lp module, set up CUPS for the deskjet.  Test job: cups thinks it prints, but printer doesn't seem to get it.

garlick, 2017-08-06:
Oh, I forgot that I had disconnected the control lines on the adapter I was testing.  Putting those back, I was able to print a tabloid schematic of this project to the printer over parallel.

Closed 2017-08-06.

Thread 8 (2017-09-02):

develop ppdev-driven tests

garlick, 2017-09-02:
Write tests to exercise all the kernel interface to the port that ppdev can use.

A unidirectional loop back plug test would be useful.

A test between two computers attached with a laplink cable would be useful.

(Possibly overkill) a teensy (ARM-based microcontroller), controlled over USB, could be used to source and sink data on the parport for tests.

garlick, 2018-07-09:
Between loop.c and walk.c, I  think we have the basics covered here.  Closing.

Closed 2018-07-09.

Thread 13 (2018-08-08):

Possible to do a rpi b (rev2.0) hat?

orrpan, 2018-08-08:
If soldering additional pins (p5-pins) would it be possible to use an older rpi, only by changing GPIO ports used and the schematics of the pcb?

http://pi4j.com/pins/model-b-rev2.html

Changing pins like this:

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

Which will leave GPIO14 and GPIO15 free.

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

garlick, 2018-08-14:
Yeah, maybe!  Although given that there are several generations of pi now that use the modern GPIO pinout, is it worth the effort?   Then again, most people would say this whole project isn't worth the effort and we should let the parallel port die its natural death, so who am I to talk :-)   Best of luck.

garlick, 2020-01-02:
Closing as this is probably not worth the effort given that pi foundation has more or less standardized the 40 pin connector for a while now.

Closed 2020-01-02.

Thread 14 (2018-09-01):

document process for compiling driver against pi kernel

garlick, 2018-09-01:
It's non-obvious how to compile the kernel driver, so a little documentation could be helpful.

Some notes, working backwards since I didn't take any when I worked through this before:

* Install kernel headers with `sudo apt-get install raspberrypi-kernel-headers`
* The driver Makefile references `/lib/modules/$(KERNEL_VERSION)/build` where KERNEL_VERSION is taken from `uname -r`.
* If not running the same kernel as the one you are building for, you can run `make KERNEL_VERSION=whatever`
* Parport stack is configured off by default in the raspberry pi kernel, so it is not built
* This parport stack code was copied into driver directory in this project
* Ideally, driver would be submitted upstream, pi maintainers convinced to enable parport stack, and this duplication of code eliminated; meanwhile, copied sources may need to be synchronized from time to time when upstream changes
* You have to consistently use the packaged kernel and headers for this to continue to work through updates;  don't pull in bleeding edge kernel with  `rpi-update` or this procedure won't work.

garlick, 2018-09-01:
Output from running `make` in the driver directory should look similar to this:
```
garlick@sbig9e:~/proj/pi-parport/driver $ make clean
make -C /lib/modules/4.14.62-v7+/build M=/home/garlick/proj/pi-parport/driver clean
make[1]: Entering directory '/usr/src/linux-headers-4.14.62-v7+'
  CLEAN   /home/garlick/proj/pi-parport/driver/.tmp_versions
  CLEAN   /home/garlick/proj/pi-parport/driver/Module.symvers
make[1]: Leaving directory '/usr/src/linux-headers-4.14.62-v7+'
garlick@sbig9e:~/proj/pi-parport/driver $ make
make -C /lib/modules/4.14.62-v7+/build M=/home/garlick/proj/pi-parport/driver modules
make[1]: Entering directory '/usr/src/linux-headers-4.14.62-v7+'
  CC [M]  /home/garlick/proj/pi-parport/driver/share.o
  CC [M]  /home/garlick/proj/pi-parport/driver/ieee1284.o
  CC [M]  /home/garlick/proj/pi-parport/driver/ieee1284_ops.o
  CC [M]  /home/garlick/proj/pi-parport/driver/procfs.o
  CC [M]  /home/garlick/proj/pi-parport/driver/daisy.o
  CC [M]  /home/garlick/proj/pi-parport/driver/probe.o
  LD [M]  /home/garlick/proj/pi-parport/driver/parport.o
  CC [M]  /home/garlick/proj/pi-parport/driver/parport_gpio.o
  CC [M]  /home/garlick/proj/pi-parport/driver/lp.o
  CC [M]  /home/garlick/proj/pi-parport/driver/ppdev.o
  Building modules, stage 2.
  MODPOST 4 modules
  CC      /home/garlick/proj/pi-parport/driver/lp.mod.o
  LD [M]  /home/garlick/proj/pi-parport/driver/lp.ko
  CC      /home/garlick/proj/pi-parport/driver/parport.mod.o
  LD [M]  /home/garlick/proj/pi-parport/driver/parport.ko
  CC      /home/garlick/proj/pi-parport/driver/parport_gpio.mod.o
  LD [M]  /home/garlick/proj/pi-parport/driver/parport_gpio.ko
  CC      /home/garlick/proj/pi-parport/driver/ppdev.mod.o
  LD [M]  /home/garlick/proj/pi-parport/driver/ppdev.ko
make[1]: Leaving directory '/usr/src/linux-headers-4.14.62-v7+'
```

andrewtubbiolo, 2019-06-17:
Have you tried 4.19.42-v7+ yet? The /lib/modules/4.19.42-v7+/build directory is devoid of any files at all.
I see you've had success with 4.14.62-v7+. Should I build a system that uses that lib version?

garlick, 2019-06-17:
No I haven't.  By chance did you update with `rpi-update`?

If you use the normal apt update process, then `raspberrypi-kernel-headers` provides `/usr/src/linux-headers-${version}` which `build` is a symlink to.

I'm not sure if there is a documented process to get headers that match a kernel installed with `rpi-update`...

https://www.raspberrypi.org/documentation/linux/kernel/updating.md

garlick, 2019-06-17:
Just pulled down the latest stretch updates with apt, and that kernel was installed.  My `build` dir is populated.  Make sure you have `raspberrypi-kernel-headers` installed.

andrewtubbiolo, 2019-06-17:
I did not use rpi-update. I did read your docs. :) It's been a few years (overa decade) since I've compiled a linux kernel, so I'm going back up the curve with this.

I applied the symlink by hand and with some success, but got these errors.

sudo ln -s /usr/src/linux-headers-4.19.42-v7+ /lib/modules/4.19.42-v7+/build

/home/pi/src/pi-parport-master/driver/parport/ieee1284.c:80:2: error: implicit declaration of function 'init_timer_on_stack' [-Werror=implicit-function-declaration]
  init_timer_on_stack(&timer);
  ^~~~~~~~~~~~~~~~~~~
/home/pi/src/pi-parport-master/driver/parport/ieee1284.c:82:17: error: assignment from incompatible pointer type [-Werror=incompatible-pointer-types]
  timer.function = timeout_waiting_on_port;
                 ^
/home/pi/src/pi-parport-master/driver/parport/ieee1284.c:84:7: error: 'struct timer_list' has no member named 'data'
  timer.data = port->number;

So it seems I symlinked to the wrong directory, or indeed some things have changed.

andrewtubbiolo, 2019-06-17:
Well bugger, yes, I have raspberrypi-kernel-headers, undid the symlink, did a dist-upgrade and the build directory is still empty. Okay, I'll start over with a clean sheet and see if that sets things right.

Thanks.
Andrew

andrewtubbiolo, 2019-06-17:
A clean start, with normal raspi-config session, an apt-get install of raspberrypi-kernel-headers, git, a clone of this project, made for a clean compile with kernel mods showing on an lsmod. Logic analyser sessions tomorrow.

Thanks.
Andrew

garlick, 2020-01-02:
I tried to clarify this process in the README.md.  Hopefully it's better.

Closed 2020-01-02.

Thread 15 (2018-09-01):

fix v1 design based on discrete logic

garlick, 2018-09-01:
A couple of people have mentioned that the SN74LVC161284 chip used in the v2 hardware design is not available in their countries.  (As a side note, I have been able to source the SSOP (DLR suffix) parts through [Arrow Electronics](https://www.arrow.com/en/products/sn74lvc161284dlr/texas-instruments) which claims to ship internationally)

Another option might be to augment the v1 hardware that was based on the  74AHCT541 with bidirectional support and better line termination.   Details TBD.

garlick, 2018-09-09:
Luciano Camera found this chip that might be an alternative to the SN74LVC161284:

https://www.nexperia.com/products/logic/asynchronous-interface-logic/printer-interfaces/series/PDI1284P11.html

garlick, 2018-09-09:
Luciano also prototyped a new design using 74HC245 and 74HC541, with Vcc at 5V, and a voltage divider to convert to pi 3V3.

garlick, 2020-01-02:
I'm not sure this is really worthwhile, unless maybe someone wants to do a through-hole version that's also easier to solder than the current SMT part.  Closing for now as I don't think there's interest.

Closed 2020-01-02.

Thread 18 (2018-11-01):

Pi Zero Board (With DB25)

danhans42, 2018-11-01:
H,

Just wanted to say thank you for this project, I have seen many a request for such a device over the years and I am surprised this has not been more widely used.

I am currently using this on a Pi Zero (or will be), but have had to opt for a TSSOP parts and a breakout board to get a demo board up and running.

I just wondered if you would consider at some rerouting your board so it fits nicely on a Pi Zero with a PCB mount DB25 connector rather than the DIL? I have loaded your files into Eagle but is currently way beyond me.

If not, no problem - think I had better get learing Eagle :-)

Thanks for your work so far!

garlick, 2018-11-01:
Hi, glad you're having fun with it (or at least planning for future fun :-)

You might try Arrow Electronics for the SSOP parts.

Or doing a new board that fits the Pi Zero and uses a TSSOP part might be a good idea, though I don't presently have time to work on it.  (If you got one working I'd certainly point to your work from here, or pull it in if you wanted!) The driver of course should "just work" with the new board - you could even use different GPIO pins convenient for layout as long as a separate device tree overlay file was provided for that board.

I've been planning to switch to KiCAD for a while.  Eagle's subscription licensing kind of sucks, so I'm stuck on the older version before they changed the licensing.  If I was starting without any Eagle knowledge, I'd surely go with KiCAD, since Eagle has many oddities.  (My humble opinion)

garlick, 2018-11-01:
One thing - my first prototype had a DB25 on the board, and I had some problems with mechanical stress on the board, plus I found it to be a PITA to accommodate the connector in compact off-the-shelf pi case.  Admittedly the board was a crappy home-made job, without plated through holes.

danhans42, 2018-11-01:
Thanks for getting back to me.

Basically my tests will be using a cheat cartridge for a game console. So by using a PCB mounted connector I was hoping to plug the whole unit into the device itself (it's the xplorer device for the Sony play station), so no cable would be required.

I will have a look at options for designing a PCB, the whole world of sending a design is fairly new to me - the last PCB I designed was single sided and printed using my old HP Laserjet 4 using ExpressPCB.

My thoughts of using the Pi Zero is so it's a small compact unit that just plugs straight into my device.

I will take a look at learning Eagle or starting from scratch as I also wanted to break out the UART pins to a header.

I will start taking a look next week so long as my test setup works correctly.

Thanks for the pointers so far, most helpful.

garlick, 2018-11-01:
Oh interesting - another guy used this board (successfully) for a legacy game cartridge reader/writer.  He was using software called ucon64, which could be configured to use the "ppdev" user-space interface to the parport.  That aspect is critical to being successful with this board.  If the software tries to access the legacy ports by address, it won't work.

danhans42, 2018-11-02:
Definitely works with ppdev, the software is here

danhans42, 2018-11-04:
Just an update, I have this working pretty well in a test setup.. I have used some crude level shifting methods and managed to omit both strobe and status (the cheat carts dont use them).

For what I need to do I might just have a look at using something along the lines of your V1 schematic as this is pretty much what I followed (I just omitted the '74 series stuff for resistor dividers - not good).

Now I know it definitely works I will look at designing a small board for it to go on.

Just to say, thanks again! This is something that I have wanted to achieve for years - the cheap RaspberryPi Zero and your great work has made this possible.

Regards

Dan

garlick, 2018-11-04:
Nice!  That was fast.

garlick, 2020-01-02:
FYI: this project was reworked in KiCAD so it should be easier to lay out a new board for the Pi Zero form factor if someone feels the need.

quorten, 2020-07-27:
F.Y.I. I started a draft to rework this to Pi Zero form factor.  Sneak peak at first iteration as a HAT.

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

RPi Zero WH would probably be ideal for this form.  However, with other Raspberry Pi Zero versions that do not have the pin header soldered on, there is a better option: use two right-angle pin header connectors to put the HAT board on the same horizontal level as the Zero board, then a DB25 connector is board-mounted on the opposite end of the HAT.  This allows the whole assembly to be put in a nice square case that is easy to get a hand grip on when working with DB25 connectors that are often stiff to plug/unplug, and it positions the USB & HDMI connectors on the opposite end of the DB25 connector.

That being said, it might make sense to make two versions of the board for RPi Zero.

garlick, 2020-07-28:
Nice!

Also, funny, I just oshparked a 40 pin adapter that does exactly that.  Two versions, one for regular tall headers, and one surface mount for low profile.  I'll share them with you if you're interested, not that it's rocket science :-)

garlick, 2020-07-28:
[this one](https://oshpark.com/shared_projects/KMQXVn0e) should work with Adafruit's $2 [low profile socket](https://www.adafruit.com/product/2187)

[this one](https://oshpark.com/shared_projects/2UQIWw9e) works with std through hole

Design files  https://github.com/garlick/pi-cluster-two/tree/master/hardware/40pin-adapter

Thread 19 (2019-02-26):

DMA

masterzion, 2019-02-26:
Hi,
I have a doubt about this lib. I am not sure if it is a issue.

I after build and run, it seems it works.
I tested whit this Diagnostic Utility.
http://yyao.ca/projects/ParallelPortLinux/

But, it seems I must to declare the DMA address to make it work with Linux CNC
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

I could not find the address on the documentation and it seems the 0x378 is not recognized by hal_parport.

Is it possible to set some address?
The default linux parport_pc allow us to set it by parameter.
ex:
insmod parport_pc io=0x3b

Regards

garlick, 2019-02-26:
This board doesn't support dma.  I am very interested to hear how you get
on with linuxcnc though!  I hope dma is optional?

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

garlick, 2019-04-25:
There was a way to tell the PC DMA controller to move data through the parallel port in ECP mode, but looking at your issue in more detail, I think linuxcnc just wants to bit bang the legacy x86 memory mapped I/O ports.

That won't work here.  If one wants to bit bang the port pins, one would need to go through the parport driver stack using ppdev, described here:

http://as6edriver.sourceforge.net/Parallel-Port-Programming-HOWTO/accessing.html

I don't know if the additional latency of the ppdev method is prohibitive for this use case, but since apparently there is a hardware abstraction layer (HAL?) it might be reasonable to try to create a driver that uses ppdev, or perhaps one that allows you to more directly access arbitrary GPIO pins?

I'll retitle this issue to be more specific to linuxcnc, since it's a compelling use case if it could work!

andrewtubbiolo, 2019-04-25:
I use LinuxCNC on my milling machines! When I was thinking of doing TDI
with a Pi, my first thought was LinuxCNC with it's real time capability
would probably be the solution. But I thought an FPGA would be easier.

Andrew

On Thu, Apr 25, 2019 at 3:58 PM Jim Garlick <notifications@github.com>
wrote:

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

Dloranger, 2020-12-10:
I am interested in using this for linux CNC as well, has anyone gotten this to work?

garlick, 2020-12-10:
Not that I'm aware of.

vonj, 2020-12-10:
Sounds plausible that it should work, actually.

vspositron, 2020-12-29:
Hi Everyone,

I am eagerly waiting for an RPI hat that will enable me to connect with the cheap LinuxCNC/ Mach3 CNC boards available in the market (https://in.pinterest.com/pin/720013059148220267/). It will be a holy grail for the DIY community. Please include this capability in the next version. I also appreciate all the efforts you and the team have taken so far on this project.

Thanks,
Sagar

garlick, 2020-12-29:
Maybe it could work now if, instead of using ppdev + the kernel parport stack,  [libbcm2835](https://www.airspayce.com/mikem/bcm2835/) is used to memory map the Pi's GPIO peripheral where it can be directly poked from user space.

That would be kind of like directly accessing the legacy parallel port on an x86 using its I/O address, which apparently works for linuxcnc.

I don't follow linuxcnc, but maybe someone has already tried this approach?

garlick, 2020-12-29:
Heh, just found this:

https://github.com/LinuxCNC/linuxcnc/blob/master/src/hal/drivers/hal_pi_gpio.c

garlick, 2020-12-31:
There is also this:

https://github.com/LinuxCNC/linuxcnc/blob/master/src/hal/drivers/hal_pi_gpio_demo.hal

which shows that the gpio pin assignment is configurable.  Hmm, I don't know if the hal driver for the parport does any other magic to make those parallel port stepper boards work, but it _may_ be as simple as replicating the above example with the correct list of GPIO pin numbers for our board + parallel port stepper board?

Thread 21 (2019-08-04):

ieee1284.c:80:2: error: implicit declaration of function ‘init_timer_on_stack’

garlick, 2019-08-04:
After raspbian update to kernel `4.19.57-v7+`, pi-parport is sad:
```
make -C /lib/modules/4.19.57-v7+/build M=/home/garlick/proj/pi-parport/driver modules
make[1]: Entering directory '/usr/src/linux-headers-4.19.57-v7+'
  CC [M]  /home/garlick/proj/pi-parport/driver/parport/share.o
  CC [M]  /home/garlick/proj/pi-parport/driver/parport/ieee1284.o
/home/garlick/proj/pi-parport/driver/parport/ieee1284.c: In function ‘parport_wait_event’:
/home/garlick/proj/pi-parport/driver/parport/ieee1284.c:80:2: error: implicit declaration of function ‘init_timer_on_stack’ [-Werror=implicit-function-declaration]
  init_timer_on_stack(&timer);
  ^~~~~~~~~~~~~~~~~~~
/home/garlick/proj/pi-parport/driver/parport/ieee1284.c:82:17: error: assignment from incompatible pointer type [-Werror=incompatible-pointer-types]
  timer.function = timeout_waiting_on_port;
                 ^
/home/garlick/proj/pi-parport/driver/parport/ieee1284.c:84:7: error: ‘struct timer_list’ has no member named ‘data’
  timer.data = port->number;
       ^
cc1: some warnings being treated as errors
scripts/Makefile.build:303: recipe for target '/home/garlick/proj/pi-parport/driver/parport/ieee1284.o' failed
make[3]: *** [/home/garlick/proj/pi-parport/driver/parport/ieee1284.o] Error 1
scripts/Makefile.build:544: recipe for target '/home/garlick/proj/pi-parport/driver/parport' failed
make[2]: *** [/home/garlick/proj/pi-parport/driver/parport] Error 2
Makefile:1517: recipe for target '_module_/home/garlick/proj/pi-parport/driver' failed
make[1]: *** [_module_/home/garlick/proj/pi-parport/driver] Error 2
make[1]: Leaving directory '/usr/src/linux-headers-4.19.57-v7+'
Makefile:12: recipe for target 'modules' failed
make: *** [modules] Error 2
```

Closed 2019-08-04.

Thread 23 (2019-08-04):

clarify hardware license

garlick, 2019-08-04:
The hardware portion of this project was intended to be freely shared and extended.

The project LICENSE is GPL-2.0.  The hardware design I guess would default to GPL-2.0, but that may not be an appropriate license for hardware.  Investigate the state of the practice for "open source hardware" and adopt one of the best practices in this project.

See: https://www.oshwa.org/definition/

Consider porting the design files from Eagle (proprietary) to KiCAD (free), and silk screening the OSHWA logo on the next version of the board.

andersmilton, 2019-09-09:
I don't really like GPL for hardware myself. I usually go for CC BY-SA for hardware and GPL for software. But GPL should work.

garlick, 2019-09-09:
Yeah that might be the way to go.

garlick, 2020-01-02:
Went with CERN-OHL-1.2

Closed 2020-01-02.

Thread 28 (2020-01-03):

[v3] add a bypass cap

garlick, 2020-01-03:
The bypass capacitor from v2 was unintentionally omitted when v3 was created.  There should probably be at least one on the main buffer chip.

garlick, 2020-07-27:
Fixed by #34

Closed 2020-07-27.

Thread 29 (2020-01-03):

[v3] the trace running under R5 is bad form

garlick, 2020-01-03:
I've since learned its considered bad form to run traces under resistors :-/ .  Re-route in a future rev.

garlick, 2020-07-27:
Fixed by #34

Closed 2020-07-27.

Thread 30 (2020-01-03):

[v3] generate BOM

garlick, 2020-01-03:
Need to generate bill of materials for version 3

quorten, 2020-03-11:
Thanks for making pi-parport, and thanks for reworking the hardware in KiCad!

I was looking around at this and thought I might add some improvements while I'm at it.  One improvement that I'm thinking about for the V3 Bill of Materials is specific manufacturer part number references for all parts rather than just the ICs.  Also, large electronics distributors like Digi-Key may also have their own part numbers.  These can be added into the schematic and the Bill of Materials can be generated from KiCad.  Then, that can be used to easily place an order for all parts from a single distributor.

I'll probably have a pull request coming your way soon with my ideas.

garlick, 2020-03-12:
Awesome!  Yep, I think the idea is you would enter that stuff as device metadata that the BOM generator in kicad can pull from.  There's a "John's basement" episode on it somewhere in this playlist:

https://www.youtube.com/playlist?list=PL3by7evD3F51fKkyrUbH-PCdwPCWc9F8a

garlick, 2020-03-13:
Closed by #32

Closed 2020-03-13.

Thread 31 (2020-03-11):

pi-parport connected via SPI

quorten, 2020-03-11:
I've been looking at the `pi-parport` project for quite some time, but one thing that threw me off from using it was the number of GPIO pins the hardware interface required, which doesn't leave much room left for other peripherals.

Of course, I've also been a relative novice with Raspberry Pi and embedded and now I realize that it should be fairly simple to connect the hardware interface through SPI via a GPIO port expander chip.  (I2C would also work, though it couldn't be as fast as SPI.)  With the right chip or two, the hardware changes should be fairly simple.

The driver changes would depend on which chip is selected.  Though it should be easy to get a basic interface running, there may also be room for tweaking and optimizing the speed of the SPI interface above the basic results.

It may make more sense to add this as a second hardware interface option and maintain both in parallel rather than have this be a successor design.  In any case, I'm open to thoughts on this idea and thought I'd post it here.

garlick, 2020-03-11:
Yeah, it's a bummer that it pretty much eats your whole pi.

The SPI expander would be interesting to try.  The extra latency might be a concern for some applications, though maybe not for those game controller ROM people who seem to manage to bit bang through ppdev in user space!

If you do try it, one thing to look at is the calls to `gpiod_cansleep()` in the driver, which (I predict) will return true for an SPI expander and cause the driver to abort.  You could take those tests out and see how it goes.    The camera driver I was working on originally would disable interrupts while bit banging.
 That's probably why those checks are in my driver (sleep with interrupts off == bad).

andrewtubbiolo, 2020-03-19:
Hi Andrew and Jim:

   FYI I've been using this project for about 8 months now on a SBIG St-8
ccd camera. Be careful
on the timing requirements for your application Andrew. Make sure the
serial xfer's in and out to
your shift register won't mess up any timing of your parallel port
application. What you are describing is the same
sort of thing USB to LPT ports try to do, and even USB to IEEE1284 ports
would not work for me.
Also keep in mind when I'm clocking my camera the bit banging soaks up an
entire core. I was hoping
I could port this down to a Pi-zero, but I don't think it'll work. I'll try
it soon and see how bad the train wreck is.

Andrew

On Wed, Mar 11, 2020 at 4:57 PM Jim Garlick <notifications@github.com>
wrote:

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

quorten, 2020-03-23:
Andrew,

Interesting point to note.  On one hand, I assumed it should work pretty well since early 2000s "Windows XP" era PCs with a parallel port are connected in a serialized fashion via the LPC bus to the Super I/O chip.

The maximum Raspberry Pi SPI clock speed of 125 MHz should be comparable to the timing delay introduced by the LPC bus or ISA bus, provided that high-frequency circuit design best practices are followed.

Yeah, good points to keep in mind... for me I was hoping I'd have a versatile Raspberry Pi parallel port for any future use.  My present uses are mostly to interface with a Windows 9x printer and scanner, so therefore about 0.120-0.360 microseconds latency is pretty good for me.  A 22 MHz SPI clock should be a good starting point many applications.

andrewtubbiolo, 2020-03-24:
Hi Andrew:

    Running an SBIG ST-8 camera is pretty demanding. It involves intense
input by clocking out a 1.5 megapixel CCD at 16 bits per pixel. Unlike most
parallel port applications it's an awful lot of in and very little out. I
think piparallel port is pretty capable. It's worth trying out.

  Interesting insights into the advanced parallel support chips from the
00's PC's. I wonder if that serial stream fed a state engine that did all
the real time bit banging and data x-fer?

Andrew

On Mon, Mar 23, 2020 at 3:56 PM Andrew Makousky <notifications@github.com>
wrote:

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

quorten, 2020-07-27:
A few observations related to this feature discussion.

* The current GPIO `pi-parport` is not as efficient as it could be.  If the 8-bit DATA was aligned to BCM GPIO16...GPIO23, then only about 7 CPU instructions are required to write all 8 bits simultaneously, and only about 4 CPU instructions to read 8 bits.  The current bit scrambling/unscrambling implementation could require, by one estimate, around 113 CPU instructions to write 8 bits, and about 80 CPU instructions to read 8 bits.

  Point in hand, if bit twiddling at the interface is the limit, there is still plenty of room for improvement in the current implementation, and what is lost on an SPI shift register can be compensated for by additional optimization.

* The current driver might not allow GPIO port expanders by simply changing the device tree definitions because it fails if `gpiod_cansleep()` is true, like might be the case when connected through a port expander.

quorten, 2020-10-22:
So, some other relevant notes around this idea.  Raspberry Pi 4 Compute Module can have a PCIe bus wired up to it.  It could therefore be possible to attach existing PCI parallel ports to a "PC" built around a Raspberry Pi 4 Compute Module, and this would be another way to alleviate the I/O connector problem.

Also related to that mention, I also saw there to be proprietary hardware similar to pi-parport, but with an RS-232 serial port on top too.

andrewtubbiolo, 2020-10-22:
Those PICe modules have proper state machines for the parallel port
functionality, along with
buffer space for data going out, and data coming in. So a radical departure
for the code in general.
... Right? ....

A fast question, I've been static on my ST-8 interface project, but it
seems I heard that SBIG open
sourced the SBIG drivers, have those changes been introduced into the new
releases? SOrry guys,
I need to catch up.

Andrew T.

On Thu, Oct 22, 2020 at 10:15 AM Andrew Makousky <notifications@github.com>
wrote:

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

garlick, 2020-10-22:
Yeah that pcie port is a game changer!

> A fast question, I've been static on my ST-8 interface project, but it seems I heard that SBIG open sourced the SBIG drivers, have those changes been introduced into the new releases? SOrry guys, I need to catch up.

They (cyanogen) agreed to open source the kernel module for parallel port cameras, and the updated project is here:

https://github.com/garlick/sbig-parport

but as far as I know they haven't opened up the user space component, the "sbig universal driver".  If you hear different  LMK!

herrkuhn, 2020-11-13:
> The extra latency might be a concern for some applications, though maybe not for those game controller ROM people who seem to manage to bit bang through ppdev in user space!

Just wanted to say I really had to laugh out loud at that. :D
Unfortunately those "game controller ROM people" run into timing issues with one device with their bit banging from user space that they just can't get rid off, so there's that...

garlick, 2020-11-13:
Sorry if it sounded like I disparaged your elite group! :-)

Point taken.

quorten, 2020-11-14:
I should note my latest idea on this concoction.  Probably the most sane way to do this on non-PCIe Raspberry Pi would be use use an AVR microcontroller for the "shift register" handling... because beyond the most basic shift register configurations it gets pretty complicated to find a single, small part that meets your need, so it's either programmable logic or microcontrollers from there.  AVR microcontrollers should be fast enough to meet the Pi's SPI speed limits.  As mentioned (or hinted) on other topics (#43, #45), an AVR microcontroller is a (hackish) solution for integrating multiple components into one: EEPROM, RTC, SPI shift registers, Power Management Controller, and stand-alone USB gadget (via V-USB).

Okay fine, those last few are some new mentions.

herrkuhn, 2021-01-02:
> So, some other relevant notes around this idea. Raspberry Pi 4 Compute Module can have a PCIe bus wired up to it. It could therefore be possible to attach existing PCI parallel ports to a "PC" built around a Raspberry Pi 4 Compute Module, and this would be another way to alleviate the I/O connector problem.

Just tried it. The problem seems to be the PCIe card needs the I/O in the address range for PC parallel ports, which aren't available on the Raspberry Pi/CM4.

herrkuhn, 2021-01-02:
While this thread has been hijacked with throwing around ideas: still having a problem reading from the control ports, which is impossible with the SN74LVC161284. I've stumbled over the SN74ALVC164245 (https://www.ti.com/product/SN74ALVC164245), which looks like it could be used as a replacement for the SN74LVC161284, by connecting the read-only status port directly to the GPIO via voltage divider and using the second tri state port of the IC for the control port. It would require me designing a new PCB, of course, but the modifications to pi-parport for this to work would be minimal. Any thoughts?

garlick, 2021-01-02:
> Just tried it. The problem seems to be the PCIe card needs the I/O in the address range for PC parallel ports, which aren't available on the Raspberry Pi/CM4.

Do you by chance still have that test setup together?  I'm curious what `lspci -vvv` says about your card, and whether you tried to build the parport_pc module and get it to claim the card?

garlick, 2021-01-02:
Might be good to open a new issue on reading from the control port.  I've lost track of the use case driving that need?

quorten, 2021-01-02:
@herrkuhn What particular application are you using that needs to read from the control ports?  There's a number of other projects that are well-suited to adapting to anything beyond the host-side PC parallel port use case, you might want to check out the RaSCSI board and adjust that to suit your needs.  If you don't need to rapidly switch back and forth between read/write, a simple rewiring dongle could also do.  See issue #40 since it is related.

herrkuhn, 2021-01-02:
@garlick attached the lspci -vvv output to the new topic, together with the segfault message I get with parport_pc, maybe we'll get somewhere.

@quorten @garlick my use case is video game copiers for retro consoles, mainly the SNES/Super Famicom, but also Mega Drive/Genesis, Game Boy, NeoGeo Pocket, et cetera. These copiers from the 90s usually have a 3.5" floppy drive to load games from floppy and a parallel port to load games and save states from/to a PC. Most devices work without problems with pi-parport (e.g. Super Wild Card and Pro Fighter series of copiers), but there's one device series, the Game Doctor SF 6 and 7, that uses the control port in a non-standard way that I can't get to work. GDSF6/7 uses control port pins 0 and 1 to acknowledge transferred bytes, which only works with parallel ports on PC, but not the SN74LVC161284 IC, which lacks the hardware to read from those pins.

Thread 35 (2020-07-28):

hardware/v4: build and test

garlick, 2020-07-28:
@quorten - did you have any other changes in mind for v4 of should we consider it stable?

I was thinking of ordering boards, building and testing one prototype, and publishing the design on oshpark.

quorten, 2020-07-28:
@garlick I was thinking v4 should probably focus on fixing minor issues, and adding features (and more issues) would be kept to later versions.  So yeah, I'd call it stable.

Mentioning building one version, I saw Digi-Key is currently out-of-stock on the SN74LVC161284DLR chip, expected shipment in mid September.  (They usually over-estimate the lead time.)  Arrow is still in stock though.  Tactfully said, apparently building parallel port interfaces is all the rage these days.

By the way, if OSHPARK has a minimum quantity of 3 and you don't need all 3 of the boards, I'd be more than happy to get one of the extra boards, if you don't mind.

garlick, 2020-07-28:
You bet!  Send me your shipping address and I'll send you a board and a few chips.  garlick dot jim at gmail dot com.

quorten, 2020-10-22:
Finally got around to testing my built PCB, and it is a success!  Printing images to an Epson Stylus Color 640 printer works great.  Unfortunately I was unable to test high-speed data input because my old parallel port scanner never had a Linux driver written due to missing protocol documentation.

@garlick If you think this is sufficient testing on hardware v4, you can probably close this issue now.

garlick, 2020-10-22:
Great to hear!  Sure let's close.   BTW, just merged #37 to work with latest raspbian kernel.  If you have a chance to update and retest with latest master, please open an issue if you have any problems.  I just compile tested it and checked that the target kernel was the latest raspbian.

Closed 2020-10-22.

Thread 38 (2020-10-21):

set up github actions, remove travis config

garlick, 2020-10-21:
Travis is not running on pull requests.

Also, we should add 5.4.51 to the matrix as the GPIO API changed.

Add conditional code for earlier kernels too, as #37 will have broken builds for those.

garlick, 2020-12-31:
At this point, travis seems to no longer be the CI of choice for open source projects, so changing title.

Geato, 2020-12-31:
Hi everyone.

I have been watching this project from a distance purely from the standpoint of hoping it eventually works for Linuxcnc. I am not a coder but I have many years experience with electronic systems design. I am willing to offer any assistance if I can.

The best way to assemble this board is to use a solder paste screen and "silk" screen the solder paste on the board, place the components then place the board on a hotplate for a few minutes until the solder flows. The through hole components can be hand soldered afterwards.

Unfortunately you do not want to have to order a screen for every board ordered. The screen is 10$ but one must also purchase the solder paste which is probably 2-3 times the cost of the screen.

The best scenario in terms of cost is someone supplies partially assembled kits with the smt components already mounted and let the customer finish the through hole components since that is where the labor costs are.

Just my 2 bits worth.

garlick, 2020-12-31:
Thanks for your comments @Geato ! I think you meant this for #48 ?

Also did you see issue #19 on linuxcnc?

Closed 2021-01-07.

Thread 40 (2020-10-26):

Investigate using a RaSCSI board as a pi-parport device

quorten, 2020-10-26:
Investigate writing a Device Tree Overlay and building a DB25 rewiring dongle to allow using the RaSCSI board as a pi-parport parallel port interface.

https://github.com/akuker/RASCSI

Though it's a hack, passive SCSI bus termination (resistor-based) could be just good enough to get reliable communications with parallel port devices.  Or it might require crude modifications to get sufficient termination behavior.

This could also address issue #4 since RaSCSI uses sequential BCM GPIO ordering for the data signals and (to the extent it matters) the control and status signals.

quorten, 2020-10-26:
The interesting thing about the RaSCSI project is that it is very similar to the v1 design of pi-parport.  Personally I plan on using the RaSCSI board as a SCSI hard drive and I'll see if I can make it double as parallel port interface.

quorten, 2020-10-27:
We should have considered ourselves foolish not to realize this...

On `pi-parport`, if we connect A13, Y13, PERI_IN, and PERI_OUT rather than grounding the input and not using the output, a`pi-parport` board is also capable of being used as a RaSCSI board.  However, you can only use it as exclusively an initiator or a target at a time, changing roles requires switching a DB25 rewiring dongle.  However, if we are an initiator rather than a target, we can only write the data-parity bit, never read it.

Nevertheless, it's probably much more common to be a target rather than an initiator when doing SCSI, which is the reverse when doing parallel port (the Pi is the host rather than the device).

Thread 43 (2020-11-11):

add a real time clock to the pi-parport board

garlick, 2020-11-11:
Quoth @quorten in #4:

> Just wanted to comment, I also really like the idea of an board variant with an RTC on it too. Probably the best way to do this is with a single AVR microcontroller on the ID EEPROM I2C bus that acts as both an ID EEPROM and a RTC: you simply access the proper memory address to read/write the current time register. The 32.768kHz watch crystal clocks an asynchronous timer in the AVR. There would also be a 1-second interrupt pin too... that's important but unfortunately missing from some other Raspberry Pi RTC HATs because the SoC 19.2MHz oscillator has considerable long-term timing instability.

I think an RTC would be a nice thing to tack onto a future board revision.  The AVR hack seems a bit elaborate and I think it might be best to avoid doing anything too hackish on the ID I2c to avoid running afoul of the HAT sec.  However, I just noticed, apparently raspbian has the `i2c-rtc-gpio` overlay that allows a number of common i2c RTC chips with kernel support to be driven by a bit-banged i2c port on any(?) GPIO pins, handy since we've used the main one on GPIO2 and 3:

https://www.raspberrypi.org/forums/viewtopic.php?t=187092

Alternatively we could try to free up GPIO2 and 3 in a future board revision.

quorten, 2020-11-13:
For a less hackish solution, the MCP79410T-I/SN chip almost perfectly fits the bill, just that it's internal EEPROM expects I2C subaddress "0b111" instead of "0b000" and it only has 128 bytes of EEPROM.  Just barely enough to use for our purposes.  It's also supported by `i2c-rtc-gpio` (`mcp7941x`).

https://www.digikey.com/en/products/detail/microchip-technology/MCP79410T-I-SN/2486436

So, so close on that one.

quorten, 2020-11-13:
Actually, if we could make an inquiry to get the Raspberry Pi HAT specification (and bootloader code) changed to also support `0b111` subaddress, that would allow us to use this chip for that purpose.  Might be too much to ask for, but who knows.

garlick, 2020-11-13:
How bout this one?

https://www.renesas.com/us/en/www/doc/datasheet/isl12026-a.pdf

512 bits x EEPROM and linux driver

https://github.com/torvalds/linux/blob/master/drivers/rtc/rtc-isl12026.c

Haven't looked much futher than that.

quorten, 2020-11-13:
Bigger EEPROM is better, but that also uses the subaddress `0b111`.  Come to think of it, Raspberry Pi Foundation probably made a mistake by specifying subaddress `0b000` because `0b111` would be easier to wire on the board with the CAT24C32 EEPROM chip.  And I'm guessing it's apparently more common in the industry, which is why there are several RTC chips that use this as the subaddress.

quorten, 2020-11-13:
After doing some looking around, I'd vouch that the MCP794* series RTC chips seem to have the best combination of features, price, availability, accuracy, and compatibility.  If we think the integrated EEPROM is moot, we can choose a version without it.  Otherwise, DS3231 is touted to be more accurate but it is more expensive and possibly not as easily available.

garlick, 2020-11-13:
Yeah it might be best to leave the ID EEPROM alone and go with a dedicated RTC on either the main I2C (changing parport wiring) or using the bit-banged driver mentioned above.  I would probably favor rewiring.

quorten, 2021-02-12:
Looking at other options, another approach would be to provide pin breakouts that attach to a stacked board that could provide both RTC and GPS.

garlick, 2021-02-12:
Hmm, maybe a nice way to do that would be to add a [quiic](https://www.sparkfun.com/qwiic) or [grove](https://wiki.seeedstudio.com/Grove_System) connector, after freeing up the I2C?  Then people could interface with many off the shelf modules?

quorten, 2024-08-24:
Freeing up the I2C connectors and delegating the RTC to a separate board seems to be the best solution, re #64.  It also looks like some of the stacking Raspberry Pi RTC HATs would be compatible too.

We can test one off-the-shelf module and document that it is known to work together with pi-parport on the same system.  Then, I think that would be sufficient to close this feature as complete.

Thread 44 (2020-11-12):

Errors on compilation under Raspbery Pi OS 64 Bit

herrkuhn, 2020-11-12:
Hey,

just a short heads up, drivers can't be compiled under Raspberry Pi OS 64 Bit out of the box right now. I wanted to try a current build of Eclipse CDT, which only is available for 64 Bit, so I installed the current 64 Bit beta. I'm getting a bunch of

ERROR: "__stack_chk_guard" [/PATH/DRIVER.ko] undefined!

messages on compilation for all source files in pi-parport/driver.

As a workaround I added -fno-stack-protector to the Makefile flags in pi-parport/driver and  and pi-parport/driver/parport , but I'm not sure if disabling stack protection completely has any negative side effects.

With -fno-stack-protector everything seems to work fine so far.

quorten, 2020-11-13:
This would be something to do with `libgcc` not getting linked in, maybe it is actually not desired for kernel modules?  I would think this could possibly indicate an issue in the kernel headers package, because it doesn't look like there's anything we're doing that would cause the discrepancy in the build scripts.  In any case, it's worth looking deeper into.

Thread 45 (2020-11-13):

add header for external shutdown button + halted led

garlick, 2020-11-13:
It would be nice for embedded projects to have the ability to shutdown the pi without a keyboard.

It's possible to make a switch closure on one of the GPIO lines look like someone pressed the poweroff button.   There is also a device tree overlay shipped in raspbian that lets a GPIO change state when the pi is halted.  The idea is you press the shutdown button, the OS shuts down, and when it enters the "poweroff" state, the halted LED glows (or reverse logic on the LED and make it a "running" button).

If we think we might be producing a version of the board with a real time clock (#43) that changes the parport wiring, we might consider adding this as well.

I wrote this feature up in a [different project](http://github.com/garlick/pi-cluster-one/doc/README.md) in a slightly different context.

garlick, 2024-08-19:
Now that the pi 5 has a power button maybe this is less interesting.

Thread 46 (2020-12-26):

Cannot compile Device Tree Overlay

afromanDAN, 2020-12-26:
I'm trying to compile the Device Tree Overlay on a raspberry pi 0 and I get this error:

`pi@raspberrypi:~/pi-parport/dts $ make`
`dtc -@ -I dts -O dtb -o parport-gpio.dtbo parport-gpio.dts`
`parport-gpio.dtbo: Warning (unit_address_vs_reg): /fragment@1/__overlay__/ppgpio@0: node has a unit name, but no reg property`

garlick, 2020-12-26:
Please check, but the dtbo file should have been produced as it's a non fatal error.

Here's a forum discussion that suggests these warnings are to be expected:

https://www.raspberrypi.org/forums/viewtopic.php?t=172342

specifically the post from Phil where he points out:

> `Node /fragment@0 has a unit name, but no reg property`
> Here, dtc is tricked by the fragment@<n> syntax into expecting a corresponding "reg", but there shouldn't be one. This warning is a fact of life until dtc is updated to include a better understanding of the overlay syntax.

afromanDAN, 2020-12-27:
Ah, ok. Thanks for the explanation.

Closed 2020-12-27.

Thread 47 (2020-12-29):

R1 missing from the v4 BOM

afromanDAN, 2020-12-29:
What part is it on the board? I built the board but noticed it was missing.

quorten, 2020-12-29:
This is labeled as a "DNP" (Do Not Place) part, the purpose is if you
want to hard-wire write-protect rather than using the removable
jumper.  A 220 ohm resistor or less could work just fine, but this
part is not necessary for the board.

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

quorten, 2020-12-29:
Out of curiosity, how did you print the PCB?  And which assembly
technique did you use, reflow soldering or hand soldering + drag
soldering for the LPT chip?

I have a more detailed assembly guide with photos from my second board
assembly, but I haven't put it online yet.  But point in hand, it's
worth determining what info would be most helpful to relative novices
in this area.  And also I'm curious about the relative interest in
this project, I'm guessing hand-assembling a small number of PCBs
suits this project just fine but there could be the option of PCB
assemblers for readymade boards in larger quantity.

afromanDAN, 2020-12-29:
Well I tried reflow soldering on one of them but my solder paste applicator put too much on. Second one I did was with just hand soldering but i haven't tested it yet because I'm waiting on a terminator. I think the easiest way to make one of these is to use a solder paste template and a hot air gun.

andrewtubbiolo, 2020-12-29:
Hey Dan:

     I got one of those $40 hot air units from China on Amazon. It did a
great job. I mounted mine on a surface
mount to DIP 40 converter then hand soldered wires. I simple thin line
across the pads and surface tension
did the rest. I hand tacked the corners with some angle hair solder and a
small chisel iron tip. I had two
or three bridges I cleaned up with some solder braid.

   I'm going to be doing a rev 4 after I order the board next week.

Andrew

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

quorten, 2020-12-30:
Cool, my guide is largely photographed and written around a solder paste technique without templates.  Granted my second board is not quite finished yet, but sounds like my recommendations are largely on track with what works well for other folks.  I think I may post the detailed info I currently have in the next few days.

afromanDAN, 2020-12-30:
Well I think I cooked the lpt chip. I would appreciate it if someone could make one for me.

quorten, 2020-12-31:
@afromanDAN What makes you think that?  Did you power it on and it didn't work?  Multimeter tests to check for soldering problems on powered-off ICs can fool you because the 3.3v side has ESD protection diodes, so it should appear that all such pins are "bridged" together from an electrical test.  But when you power on, it will "just work" so long as you've visually verified there are no bridges.

I'd be willing to mail you out my one finished and tested board if you're interested.

@garlick It might be worth creating a GitHub issue to discuss more about the possibility of stocking partially/fully assembled v4 boards.  Also, thanks for sending me the two PCBs!

garlick, 2020-12-31:
Thanks for helping out @quorten!  I'll open an issue.

afromanDAN, 2021-01-01:
@quorten That would be great if you could ship one out to me.

I'll close this issue now.

quorten, 2021-01-01:
@afromanDAN Send me an E-mail with your address and we can follow up with additional details there.  Same as my GitHub E-mail address.  mako0042 at umn dot edu.

quorten, 2021-01-05:
@garlick Digging deeper into this, there's a few things we should amend to our documentation and one minor bug in my driver install code that should be fixed.  Good news is that one of the two boards @afromanDAN built actually fully works!  I'll open another pull request soon.

Closed 2021-01-01.

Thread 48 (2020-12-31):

explore possible kit offering

garlick, 2020-12-31:
There are some barriers for people getting this project off the ground:
- fine pitch SMT soldering
- high shipping to part cost for small number of components
- single quantity part prices are high
- oshpark PCB fab cost is somewhat high for this size board and you have to buy 3

garlick, 2020-12-31:
A test fixture might be nice, to check out a board that has only the SMT parts soldered.

It could
* hold the board with pogo pins
* power the board
* exercise the I/O lines
* program the EEPROM

Or am I getting off in the weeds for a demand that may add up to 5 boards?  :-)

BTW, PCBWAY estimates $60 for 40 boards including international shipping.

quorten, 2020-12-31:
I think a test fixture is getting into the weeds for SMT-only soldered boards.  For other small-volume projects, it seems sane to ship out factory-soldered boards as-is and leave testing up to the user who populates on the through-hole components to complete it.

quorten, 2020-12-31:
Oh yeah... pi-parport is much cheaper in volume than RaSCSI because it doesn't need relatively rare and expensive transceiver chips.  It could just as well make sense to only offer fully assembled boards.

garlick, 2020-12-31:
Maybe we should put the BOM into digikey and see where the price breaks are? (Probably dominated by the price break on the buffer chip which is at  qty 10, 25, and 100)

At minimum it seems like a no brainer to put together a parts kit that could be provided to people at cost + shipping, since it will be so much cheaper for someone that wants to assemble one or two boards.

quorten, 2020-12-31:
The 26-pin header, 40-pin header, and buffer chip together have the least discounting at larger volume and are about $3-$4 total.

For the BOM quantities as stated (i.e. not including spares for small passives), quantity 10-50 is largely similar price breaks.  So, price breaks for 5 boards, 10 boards, and 100 boards, these are the totals for the BOM of one board.

* Qty 5: $7.395
* Qty 10: $5.518
* Qty 100: $4.4055

garlick, 2020-12-31:
Thanks for doing that!

To add to the data, here is the cost per board from PCBWAY (shipped) with a stencil thrown in:
* Qty 5: $11.60
* Qty 10: $6.40
* Qty 20: $4.20
* Qty 100: $1.36

Putting together a kit with the SMT parts soldered on as suggested by @Geato in #38 might not be so bad.

quorten, 2021-01-02:
Including the DIP jumper is probably a good idea for the kit offering, I'll update the BOMs to include the Digi-Key PN of the DIP jumper I've been using.

quorten, 2021-01-06:
It's probably a good idea to perhaps set something up to gauge interest from folks who might be interested in pre-ordering a kit.  Could be as simple as a note in the top-level README.md for adding a comment to this GitHub issue.

But yeah, my hunch is that an initial batch of 5 boards could last at least a year, 10 boards twice as long.  But I'm basing this off of my (possibly false) assumption that the pi-parport market has already been relatively "saturated" by those who assembled their own boards.

quorten, 2024-08-18:
I've been thinking about this for a long while and will jot down my thoughts here.

To avoid sitting on too much inventory, we can think of things this way: we are providing kits first as a convenient source of spares for current users, and second as an easy way for new users to get started.

Starting out by making a batch of 10 kits seems to be a reasonable ask.  That way, the total up-front cost for one batch at a time is somewhere between $120 and $300.  I don't know the current prices, but it seems like a manageable ballpark.

quorten, 2024-08-20:
Sure, I have time to review some changes.

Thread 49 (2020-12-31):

avoid copying parport modules into pi-parport source tree

garlick, 2020-12-31:
Problem:  As internal kernel interfaces change, the "vendored" copies of the parport stack become stale and break.

We only need them because the raspberry pi kernel doesn't configure the parport stack.  It sounds like they are open to changing that - see raspberrypi/linux#3918 and stale pr raspberrypi/linux#3923

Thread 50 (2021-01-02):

does a PCIe parallel port card work with the CM4?

garlick, 2021-01-02:
@herrkuhn mentioned in #31 that he had tried a parallel port PCIe card with the Pi CM4 (I assume with the CM4 IO module which brings the single PCIe lane out to a x4 slot).

Let's capture any data from that experiment here for people who might be looking at other ways to get a parallel port to work with the Pi.

herrkuhn, 2021-01-02:
Here's what I get with a Raspberry Pi 4/CM4 and a Delock PCI Express Card to 1 x Parallel IEEE1284 (https://www.delock.de/produkt/90412/pdf.html?sprache=en) in the PCIe port:

```
pi@raspberrypi:~ $ sudo lspci -vvv
00:00.0 PCI bridge: Broadcom Limited Device 2711 (rev 20) (prog-if 00 [Normal decode])
	Control: I/O- Mem+ BusMaster+ SpecCycle- MemWINV- VGASnoop- ParErr+ Stepping- SERR+ FastB2B- DisINTx-
	Status: Cap+ 66MHz- UDF- FastB2B- ParErr- DEVSEL=fast >TAbort- <TAbort- <MAbort- >SERR- <PERR- INTx-
	Latency: 0, Cache Line Size: 64 bytes
	Interrupt: pin A routed to IRQ 55
	Bus: primary=00, secondary=01, subordinate=01, sec-latency=0
	I/O behind bridge: 00000000-00000fff
	Memory behind bridge: f8000000-f80fffff
	Prefetchable memory behind bridge: 00000000fff00000-00000000000fffff
	Secondary status: 66MHz- FastB2B- ParErr- DEVSEL=fast >TAbort- <TAbort- <MAbort- <SERR- <PERR-
	BridgeCtl: Parity+ SERR+ NoISA- VGA- MAbort- >Reset- FastB2B-
		PriDiscTmr- SecDiscTmr- DiscTmrStat- DiscTmrSERREn-
	Capabilities: [48] Power Management version 3
		Flags: PMEClk- DSI- D1- D2- AuxCurrent=0mA PME(D0+,D1-,D2-,D3hot+,D3cold-)
		Status: D0 NoSoftRst+ PME-Enable- DSel=0 DScale=1 PME-
	Capabilities: [ac] Express (v2) Root Port (Slot-), MSI 00
		DevCap:	MaxPayload 512 bytes, PhantFunc 0
			ExtTag- RBE+
		DevCtl:	Report errors: Correctable+ Non-Fatal+ Fatal+ Unsupported+
			RlxdOrd+ ExtTag- PhantFunc- AuxPwr+ NoSnoop+
			MaxPayload 128 bytes, MaxReadReq 512 bytes
		DevSta:	CorrErr- UncorrErr- FatalErr- UnsuppReq- AuxPwr- TransPend-
		LnkCap:	Port #0, Speed 5GT/s, Width x1, ASPM L0s L1, Exit Latency L0s <2us, L1 <4us
			ClockPM+ Surprise- LLActRep- BwNot+ ASPMOptComp+
		LnkCtl:	ASPM Disabled; RCB 64 bytes Disabled- CommClk-
			ExtSynch- ClockPM- AutWidDis- BWInt- AutBWInt-
		LnkSta:	Speed 2.5GT/s, Width x1, TrErr- Train- SlotClk+ DLActive- BWMgmt- ABWMgmt-
		RootCtl: ErrCorrectable- ErrNon-Fatal- ErrFatal- PMEIntEna+ CRSVisible+
		RootCap: CRSVisible+
		RootSta: PME ReqID 0000, PMEStatus- PMEPending-
		DevCap2: Completion Timeout: Range ABCD, TimeoutDis+, LTR+, OBFF Via WAKE# ARIFwd-
		DevCtl2: Completion Timeout: 50us to 50ms, TimeoutDis-, LTR-, OBFF Disabled ARIFwd-
		LnkCtl2: Target Link Speed: 5GT/s, EnterCompliance- SpeedDis-
			 Transmit Margin: Normal Operating Range, EnterModifiedCompliance- ComplianceSOS-
			 Compliance De-emphasis: -6dB
		LnkSta2: Current De-emphasis Level: -3.5dB, EqualizationComplete-, EqualizationPhase1-
			 EqualizationPhase2-, EqualizationPhase3-, LinkEqualizationRequest-
	Capabilities: [100 v1] Advanced Error Reporting
		UESta:	DLP- SDES- TLP- FCP- CmpltTO- CmpltAbrt- UnxCmplt- RxOF- MalfTLP- ECRC- UnsupReq- ACSViol-
		UEMsk:	DLP- SDES- TLP- FCP- CmpltTO- CmpltAbrt- UnxCmplt- RxOF- MalfTLP- ECRC- UnsupReq- ACSViol-
		UESvrt:	DLP+ SDES+ TLP- FCP+ CmpltTO- CmpltAbrt- UnxCmplt- RxOF+ MalfTLP+ ECRC- UnsupReq- ACSViol-
		CESta:	RxErr- BadTLP- BadDLLP- Rollover- Timeout- NonFatalErr-
		CEMsk:	RxErr- BadTLP- BadDLLP- Rollover- Timeout- NonFatalErr+
		AERCap:	First Error Pointer: 00, GenCap- CGenEn- ChkCap- ChkEn-
	Capabilities: [180 v1] Vendor Specific Information: ID=0000 Rev=0 Len=028 <?>
	Capabilities: [240 v1] L1 PM Substates
		L1SubCap: PCI-PM_L1.2+ PCI-PM_L1.1+ ASPM_L1.2+ ASPM_L1.1+ L1_PM_Substates+
			  PortCommonModeRestoreTime=8us PortTPowerOnTime=10us
		L1SubCtl1: PCI-PM_L1.2- PCI-PM_L1.1- ASPM_L1.2- ASPM_L1.1-
			   T_CommonMode=1us LTR1.2_Threshold=0ns
		L1SubCtl2: T_PwrOn=10us
	Kernel driver in use: pcieport

01:00.0 Serial controller: Device 1c00:3050 (rev 10) (prog-if 05 [16850])
	Subsystem: Device 1c00:3050
	Control: I/O- Mem+ BusMaster- SpecCycle- MemWINV- VGASnoop- ParErr+ Stepping- SERR+ FastB2B- DisINTx-
	Status: Cap+ 66MHz- UDF- FastB2B- ParErr- DEVSEL=fast >TAbort- <TAbort- <MAbort- >SERR- <PERR- INTx-
	Interrupt: pin A routed to IRQ 55
	Region 0: I/O ports at <unassigned> [disabled]
	Region 1: Memory at 600000000 (32-bit, prefetchable) [size=32K]
	Region 2: I/O ports at <unassigned> [disabled]
	[virtual] Expansion ROM at 600008000 [disabled] [size=32K]
	Capabilities: [60] Power Management version 3
		Flags: PMEClk- DSI- D1- D2- AuxCurrent=375mA PME(D0+,D1-,D2-,D3hot+,D3cold+)
		Status: D0 NoSoftRst- PME-Enable- DSel=0 DScale=0 PME-
	Capabilities: [68] MSI: Enable- Count=1/32 Maskable+ 64bit+
		Address: 0000000000000000  Data: 0000
		Masking: 00000000  Pending: 00000000
	Capabilities: [80] Express (v2) Legacy Endpoint, MSI 00
		DevCap:	MaxPayload 256 bytes, PhantFunc 0, Latency L0s <2us, L1 <32us
			ExtTag- AttnBtn- AttnInd- PwrInd- RBE+ FLReset-
		DevCtl:	Report errors: Correctable- Non-Fatal- Fatal- Unsupported-
			RlxdOrd+ ExtTag- PhantFunc- AuxPwr- NoSnoop+
			MaxPayload 128 bytes, MaxReadReq 512 bytes
		DevSta:	CorrErr- UncorrErr- FatalErr- UnsuppReq- AuxPwr+ TransPend-
		LnkCap:	Port #0, Speed 2.5GT/s, Width x1, ASPM L0s L1, Exit Latency L0s unlimited, L1 unlimited
			ClockPM+ Surprise- LLActRep- BwNot- ASPMOptComp-
		LnkCtl:	ASPM Disabled; RCB 64 bytes Disabled- CommClk-
			ExtSynch- ClockPM- AutWidDis- BWInt- AutBWInt-
		LnkSta:	Speed 2.5GT/s, Width x1, TrErr- Train- SlotClk+ DLActive- BWMgmt- ABWMgmt-
		DevCap2: Completion Timeout: Not Supported, TimeoutDis+, LTR-, OBFF Not Supported
		DevCtl2: Completion Timeout: 50us to 50ms, TimeoutDis-, LTR-, OBFF Disabled
		LnkCtl2: Target Link Speed: 2.5GT/s, EnterCompliance- SpeedDis-
			 Transmit Margin: Normal Operating Range, EnterModifiedCompliance- ComplianceSOS-
			 Compliance De-emphasis: -6dB
		LnkSta2: Current De-emphasis Level: -6dB, EqualizationComplete-, EqualizationPhase1-
			 EqualizationPhase2-, EqualizationPhase3-, LinkEqualizationRequest-
	Capabilities: [100 v1] Advanced Error Reporting
		UESta:	DLP- SDES- TLP- FCP- CmpltTO- CmpltAbrt- UnxCmplt- RxOF- MalfTLP- ECRC- UnsupReq- ACSViol-
		UEMsk:	DLP- SDES- TLP- FCP- CmpltTO- CmpltAbrt- UnxCmplt- RxOF- MalfTLP- ECRC- UnsupReq- ACSViol-
		UESvrt:	DLP+ SDES- TLP- FCP+ CmpltTO- CmpltAbrt- UnxCmplt- RxOF+ MalfTLP+ ECRC- UnsupReq- ACSViol-
		CESta:	RxErr- BadTLP- BadDLLP- Rollover- Timeout- NonFatalErr-
		CEMsk:	RxErr- BadTLP- BadDLLP- Rollover- Timeout- NonFatalErr+
		AERCap:	First Error Pointer: 00, GenCap+ CGenEn- ChkCap+ ChkEn-
```
Here's the segfault message I get with parport_pc:
```
[ 6402.591532] parport: loading out-of-tree module taints kernel.
[ 6411.128400] PCI parallel port detected: 1c00:3050, I/O at 0x0(0x0), IRQ 55
[ 6411.128514] 8<--- cut here ---
[ 6411.128541] Unable to handle kernel paging request at virtual address fee00001
[ 6411.128569] pgd = 41a7b1e2
[ 6411.128586] [fee00001] *pgd=80000000007003, *pmd=00000000
[ 6411.128617] Internal error: Oops: 206 [#1] SMP ARM
[ 6411.128637] Modules linked in: parport_pc(O+) parport(O) sha256_generic libsha256 cfg80211 rfkill 8021q garp stp llc vc4 v3d cec gpu_sched drm_kms_helper bcm2835_codec(C) bcm2835_isp(C) raspberrypi_hwmon drm bcm2835_v4l2(C) drm_panel_orientation_quirks v4l2_mem2mem bcm2835_mmal_vchiq(C) snd_soc_core videobuf2_dma_contig videobuf2_vmalloc videobuf2_memops videobuf2_v4l2 snd_compress videobuf2_common snd_bcm2835(C) snd_pcm_dmaengine snd_pcm videodev mc snd_timer snd vc_sm_cma(C) syscopyarea sysfillrect sysimgblt fb_sys_fops rpivid_mem uio_pdrv_genirq uio ip_tables x_tables ipv6
[ 6411.128842] CPU: 2 PID: 1015 Comm: insmod Tainted: G         C O      5.4.79-v7l+ #1373
[ 6411.128867] Hardware name: BCM2711
[ 6411.128906] PC is at clear_epp_timeout+0x24/0xc4 [parport_pc]
[ 6411.128940] LR is at parport_pc_probe_port+0x164/0xb08 [parport_pc]
[ 6411.128962] pc : [<bf223548>]    lr : [<bf223810>]    psr: 60000013
[ 6411.128983] sp : d82a3ad0  ip : d82a3ae0  fp : d82a3adc
[ 6411.129004] r10: 00000000  r9 : d843d700  r8 : d843d5a8
[ 6411.129024] r7 : ef855878  r6 : d843d580  r5 : c1204fc8  r4 : d8658800
[ 6411.129046] r3 : fee00001  r2 : d4157734  r1 : d843d700  r0 : d8658800
[ 6411.129071] Flags: nZCv  IRQs on  FIQs on  Mode SVC_32  ISA ARM  Segment user
[ 6411.129095] Control: 30c5383d  Table: 189f5040  DAC: 55555555
[ 6411.129117] Process insmod (pid: 1015, stack limit = 0x5a30c62e)
[ 6411.129139] Stack: (0xd82a3ad0 to 0xd82a4000)
[ 6411.129161] 3ac0:                                     d82a3b74 d82a3ae0 bf223810 bf223530
[ 6411.129190] 3ae0: 00000005 00000000 d843d5c0 00000000 d82a3b14 d843d5a8 00000000 00000000
[ 6411.129219] 3b00: ef979c80 00000000 d82a3b44 d82a3b18 c0283dc4 c0282c7c c0a8fea0 c0295a14
[ 6411.129248] 3b20: 00000cc0 c03f3f6c c1204fc8 00000000 ef855800 00000000 d82a3b64 d82a3b48
[ 6411.129276] 3b40: c0283550 d4157734 d82a3b6c bf225b94 00000000 ef855800 00000000 bf2256a0
[ 6411.129305] 3b60: 00000037 00000000 d82a3bcc d82a3b78 bf22435c bf2236b8 ef855878 00000080
[ 6411.129334] 3b80: bf2270a4 00000000 bf225ec4 bf225f00 ef855878 d843d540 bf225618 00000000
[ 6411.129363] 3ba0: d82a3bcc ef855878 ef855800 bf22706c 00000000 bf2270a4 bf225b94 00000000
[ 6411.129391] 3bc0: d82a3bf4 d82a3bd0 c06f3b94 bf2241c0 c13616b0 ef855878 c13616b4 00000000
[ 6411.129420] 3be0: bf2270a4 00000018 d82a3c24 d82a3bf8 c07944d0 c06f3af0 00000000 ef855878
[ 6411.129448] 3c00: bf2270a4 bf2270a4 c0794b48 00000000 ffffffff bf2273f4 d82a3c64 d82a3c28
[ 6411.129477] 3c20: c079482c c07942ec d82a3c4c d82a3c38 c0a92768 c0a8fe78 ef855878 bf2270a4
[ 6411.129505] 3c40: ef855878 00000000 bf2270a4 c0794b48 00000000 ffffffff d82a3c84 d82a3c68
[ 6411.129534] 3c60: c0794b40 c07947c8 00000000 bf2270a4 ef855878 c0794b48 d82a3ca4 d82a3c88
[ 6411.129562] 3c80: c0794bb0 c0794ae4 ef03ebb4 c1204fc8 bf2270a4 c0794b48 d82a3cd4 d82a3ca8
[ 6411.129591] 3ca0: c07924c8 c0794b54 d82a3ce0 ef9fed58 ef03ebb4 d4157734 bf2270a4 c1268a40
[ 6411.129620] 3cc0: ef979b80 00000000 d82a3ce4 d82a3cd8 c0793d18 c0792450 d82a3d0c d82a3ce8
[ 6411.129648] 3ce0: c0793730 c0793cf8 bf225cf0 d82a3cf8 bf2270a4 bf225cf0 bf2256c4 ffffffff
[ 6411.129677] 3d00: d82a3d24 d82a3d10 c079526c c0793574 00000000 bf225cf0 d82a3d3c d82a3d28
[ 6411.129705] 3d20: c06f2e3c c07951f4 00000000 bf22506c d82a3d8c d82a3d40 bf22b410 c06f2df0
[ 6411.129735] 3d40: 8040003f c10a8b10 c03dc64c c1204fc8 bf22c084 bf22c044 ffffffff d4157734
[ 6411.129764] 3d60: d82a3d94 c1204fc8 bf22b100 d843d240 00000000 bf227140 d82a3f30 c1204fc8
[ 6411.129793] 3d80: d82a3e04 d82a3d90 c02030c4 bf22b10c d82a3dcc c0a8fea0 00000000 00000002
[ 6411.129822] 3da0: d82a3dc4 d82a3db0 c0a8fea0 c0295a14 00000cc0 c03f3f6c d82a3e04 d82a3dc8
[ 6411.129850] 3dc0: c03f3f6c c03b73f4 c03d6db0 c03f5d6c d82a3e04 d843d380 f085e000 d4157734
[ 6411.129879] 3de0: 00000002 bf227140 d843d340 d843d240 d843d280 bf227140 d82a3e2c d82a3e08
[ 6411.129909] 3e00: c02c26ac c0203080 d82a3e2c d82a3e18 c03d6f20 00000002 00000002 d843d240
[ 6411.129951] 3e20: d82a3f0c d82a3e30 c02c4d04 c02c2648 bf22714c 00007fff bf227140 c02c101c
[ 6411.129981] 3e40: c1204fc8 c0dce850 c0dce880 c0dce828 bf22f54b c0c03e0c bf227334 bf227254
[ 6411.130010] 3e60: c0dce8d0 d865a018 d843d248 bf227188 c1204fc8 bf226419 d82a0001 00000000
[ 6411.130059] 3e80: c0e8b810 c0e75724 bf22503c 00000002 00000000 00000000 00000000 00000000
[ 6411.130093] 3ea0: 6e72656b 00006c65 00000000 00000000 00000000 00000000 00000000 00000000
[ 6411.130122] 3ec0: 00000000 00000000 00000000 00000000 00000000 00000000 00000000 d4157734
[ 6411.130165] 3ee0: 7fffffff c1204fc8 00000000 0029f150 00000003 c02011c4 d82a2000 0000017b
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
garlick, 2021-01-03:
should have noted this too:
```
$ dmesg|grep BAR
[    1.282152] pci 0000:01:00.0: BAR 0: no space for [io  size 0x0008]
[    1.284620] pci 0000:01:00.0: BAR 0: failed to assign [io  size 0x0008]
[    1.287138] pci 0000:01:00.0: BAR 1: no space for
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

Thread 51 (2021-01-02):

Use DIP switch and remove R1 DNP pads in future board revs

quorten, 2021-01-02:
Thinking through it more, it's probably better to just use a DIP switch and remove the R1 pad from future board revisions.  Removable jumpers feels clumsy.  The cost savings of not using a switch don't seem to make sense for us, and a rugged write-enable connection is probably not important for our board.  The motivation of the Pi HAT template including both may have been to simply make it easy for downstream designers to choose one way or the other, but not both.

A future board revision can incorporate these changes.

garlick, 2021-01-02:
What would be the downside to permanently enabling EEPROM writes?  This isn't really a plug and play project, so it seems like a low magnitude foot-gun.  Unless maybe a spurious write is an actual issue and leaving it writable would reduce its reliability.

quorten, 2021-01-02:
Good point, I can't think of anything that could really much go wrong with spurious writes given that I2C0 is generally considered to be reserved.

garlick, 2024-08-29:
In v5 I used the "solder bridge" (open) footprint that came with the HAT template.  Maybe OK?

quorten, 2024-09-01:
Yes, and actually I've been thinking about another technique that works well on the v4 board.  I have a SOIC clip that I can attach to the EEPROM chip.  From there, it is easy to wire write-enable.  Or, alternatively, I could clip it to the unpopulated pads on the board.  I think that approach works nicely for v4 board, so I could make a documentation update to that respect.

The v5 board uses the reverse logic on write-protect, so this idea is not applicable there.

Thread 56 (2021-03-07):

Rpi 3 kernel 5.4.51 errors while make

cervellopl, 2021-03-07:
Hi,

I getting errors while build drivers. Details below.
Best regards, Maciej

make -C /lib/modules/5.4.51-v7+/build M=/home/astroberry/dr2/pi-parport/driver modules
make[1]: Entering directory '/usr/src/linux-headers-5.4.51-v7+'
  CC [M]  /home/astroberry/dr2/pi-parport/driver/parport/share.o
  CC [M]  /home/astroberry/dr2/pi-parport/driver/parport/ieee1284.o
  CC [M]  /home/astroberry/dr2/pi-parport/driver/parport/ieee1284_ops.o
  CC [M]  /home/astroberry/dr2/pi-parport/driver/parport/procfs.o
  CC [M]  /home/astroberry/dr2/pi-parport/driver/parport/daisy.o
  CC [M]  /home/astroberry/dr2/pi-parport/driver/parport/probe.o
  LD [M]  /home/astroberry/dr2/pi-parport/driver/parport/parport.o
  CC [M]  /home/astroberry/dr2/pi-parport/driver/parport/lp.o
  CC [M]  /home/astroberry/dr2/pi-parport/driver/parport/ppdev.o
  CC [M]  /home/astroberry/dr2/pi-parport/driver/parport_gpio.o
/home/astroberry/dr2/pi-parport/driver/parport_gpio.c: In function 'parport_gpio_write_data':
/home/astroberry/dr2/pi-parport/driver/parport_gpio.c:71:60: error: passing argument 3 of 'gpiod_set_array_value' from incompatible pointer type [-Werror=incompatible-pointer-types]
  gpiod_set_array_value(ctx->data->ndescs, ctx->data->desc, val);
                                                            ^~~
In file included from /home/astroberry/dr2/pi-parport/driver/parport_gpio.c:20:
./include/linux/gpio/consumer.h:124:25: note: expected 'struct gpio_array *' but argument is of type 'int *'
      struct gpio_array *array_info,
      ~~~~~~~~~~~~~~~~~~~^~~~~~~~~~
/home/astroberry/dr2/pi-parport/driver/parport_gpio.c:71:2: error: too few arguments to function 'gpiod_set_array_value'
  gpiod_set_array_value(ctx->data->ndescs, ctx->data->desc, val);
  ^~~~~~~~~~~~~~~~~~~~~
In file included from /home/astroberry/dr2/pi-parport/driver/parport_gpio.c:20:
./include/linux/gpio/consumer.h:122:5: note: declared here
 int gpiod_set_array_value(unsigned int array_size,
     ^~~~~~~~~~~~~~~~~~~~~
/home/astroberry/dr2/pi-parport/driver/parport_gpio.c: In function 'parport_gpio_write_control':
/home/astroberry/dr2/pi-parport/driver/parport_gpio.c:106:66: error: passing argument 3 of 'gpiod_set_array_value' from incompatible pointer type [-Werror=incompatible-pointer-types]
  gpiod_set_array_value(ctx->control->ndescs, ctx->control->desc, value);
                                                                  ^~~~~
In file included from /home/astroberry/dr2/pi-parport/driver/parport_gpio.c:20:
./include/linux/gpio/consumer.h:124:25: note: expected 'struct gpio_array *' but argument is of type 'int *'
      struct gpio_array *array_info,
      ~~~~~~~~~~~~~~~~~~~^~~~~~~~~~
/home/astroberry/dr2/pi-parport/driver/parport_gpio.c:106:2: error: too few arguments to function 'gpiod_set_array_value'
  gpiod_set_array_value(ctx->control->ndescs, ctx->control->desc, value);
  ^~~~~~~~~~~~~~~~~~~~~
In file included from /home/astroberry/dr2/pi-parport/driver/parport_gpio.c:20:
./include/linux/gpio/consumer.h:122:5: note: declared here
 int gpiod_set_array_value(unsigned int array_size,
     ^~~~~~~~~~~~~~~~~~~~~
cc1: some warnings being treated as errors
make[2]: *** [scripts/Makefile.build:266: /home/astroberry/dr2/pi-parport/driver/parport_gpio.o] Error 1
make[1]: *** [Makefile:1709: /home/astroberry/dr2/pi-parport/driver] Error 2
make[1]: Leaving directory '/usr/src/linux-headers-5.4.51-v7+'
make: *** [Makefile:12: modules] Error 2

garlick, 2021-03-08:
Hi, one thing to try is to run the `get_parport_src.sh`  script down in the drivers directory.  This will update the parport sources to match your installed kernel (assuming astroberry uses same kernel package names as rasbpian).  I'm not sure if that's going to fix the `parport_gpio.c` errors though.  Try?

If it doesn't work I'll go grab that specific kernel and see if I can make a quick patch for you to apply.

cervellopl, 2021-03-08:
Thanks for tip. After running script I build driver without issues

Closed 2021-03-08.

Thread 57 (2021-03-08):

probe of ppgpio@0 failed with error -22

cervellopl, 2021-03-08:
After boot and loading modules as in instruction I had something like this:

Mar  8 18:45:29 astroberry kernel: [ 3497.542536] parport: loading out-of-tree module taints kernel.
Mar  8 18:45:36 astroberry kernel: [ 3504.134802] pinctrl-bcm2835 3f200000.gpio: pin gpio11 already requested by 3f204000.spi; cannot claim for ppgpio@0
Mar  8 18:45:36 astroberry kernel: [ 3504.134833] pinctrl-bcm2835 3f200000.gpio: pin-11 (ppgpio@0) status -22
Mar  8 18:45:36 astroberry kernel: [ 3504.134848] pinctrl-bcm2835 3f200000.gpio: could not request pin 11 (gpio11) from group gpio11  on device pinctrl-bcm2835
Mar  8 18:45:36 astroberry kernel: [ 3504.134859] parport-gpio ppgpio@0: Error applying setting, reverse things back
Mar  8 18:45:36 astroberry kernel: [ 3504.134963] parport-gpio: probe of ppgpio@0 failed with error -22
Mar  8 18:45:56 astroberry kernel: [ 3524.533219] ppdev: user-space parallel port driver

Any suggestions?
Best regards,
Maciej

garlick, 2021-03-08:
It sounds like you'll need to disable `spi0` (pin 11 is assigned to spi0 SCLK per [this doc](https://www.raspberrypi.org/documentation/hardware/raspberrypi/spi/README.md))
Commenting out this in your `/boot/config.txt` and rebooting may do it

```
dtparam=spi=on
```
Or if another device is using spi0 you might need to comment that out.

cervellopl, 2021-03-08:
Done but still have:
Mar  8 20:03:55 astroberry kernel: [  499.281789] parport: loading out-of-tree module taints kernel.
Mar  8 20:04:03 astroberry kernel: [  507.668429] pinctrl-bcm2835 3f200000.gpio: pin gpio2 already requested by 3f804000.i2c; cannot claim for ppgpio@0
Mar  8 20:04:03 astroberry kernel: [  507.668450] pinctrl-bcm2835 3f200000.gpio: pin-2 (ppgpio@0) status -22
Mar  8 20:04:03 astroberry kernel: [  507.668464] pinctrl-bcm2835 3f200000.gpio: could not request pin 2 (gpio2) from group gpio2  on device pinctrl-bcm2835
Mar  8 20:04:03 astroberry kernel: [  507.668474] parport-gpio ppgpio@0: Error applying setting, reverse things back
Mar  8 20:04:03 astroberry kernel: [  507.668569] parport-gpio: probe of ppgpio@0 failed with error -22

garlick, 2021-03-08:
Looks like a conflict with i2c1.   You could try commenting out
```
dtparam=i2c_arm=on
```

cervellopl, 2021-03-08:
Ok it looks after that parport correct running driver. But how about EEPROM? I2C is not available after this operation.

garlick, 2021-03-08:
I think the fact that it is not available from linux does not prevent it from being accessed during boot.

For flashing, which involves temporarily enabling i2c, I _think_ you should be able to follow the instructions [here](https://github.com/worlickwerx/pi-parport/tree/master/eeprom/README.md), even with `dtparam=i2c_arm=on` commented out.  The `parport_gpio` driver does not need to be loading during this process (although as I recall, there is no conflict reported).

quorten, 2021-03-09:
Yeah, the flashing instructions point you to using i2c0 rather than i2c1.  However, it may be easier to use the GPIO-based i2c driver instead, that can be dynamically loaded without reboot and is apparently officially recommended in preference to using i2c0.  I haven't tested it yet, though, but you would do it like this:

```
# Dynamically install the overlay and driver.
sudo dtoverlay i2c-gpio i2c_gpio_sda=0 i2c_gpio_scl=1 bus=3

# Run the flashing commands here.

# Remove the overlay.
sudo dtoverlay -r i2c-gpio
# N.B.: Any auto-loaded kernel modules will remain resident until explicitly removed.
```

quorten, 2021-03-09:
As a side note, I'm curious to see how pi-parport fits into the astroberry picture.  Mentioning the i2c conflict, it's in the list of the number of things we'd like to change in a future revision, along with making other adjustments to ease the simultaneous connection of an RTC, GPS, power button, etc.

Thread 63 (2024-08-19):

add alternate DB25 connection(s)

garlick, 2024-08-19:
Problem: the ribbon cable from the board to the DB25 connector is bulky and constrains where the board can be deployed

If we can make room, consider adding alternate footprints.  The end user could choose which one to populate:
- existing 2.54 pitch dual row header
- a fine pitch header or FPC (which would imply an adapter board at the DB25 end)
- a DB25 footprint for direct mounting on the board (making space for that may be a reach!)

garlick, 2024-08-24:
It doesn't really seem feasible to do a DB-25 on board in the normal HAT profile.  I tried, but a board-secured DB-25 footprint overlaps with the HAT standoff holes on the long edge.  The HAT+ spec allows the board to be any shape but then a custom or topless case would be required.

As mentioned, the FPC connector would necessitate another board on the DB25 end so that is a bit of a downside there.

I think I'll just close.  @quorten - fee free to reopen if you think we should try harder to pursue this.

Closed 2024-08-24.

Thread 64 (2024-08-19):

add a Qwiic connector

garlick, 2024-08-19:
I'm not sure if we have already used all the I2C GPIOs but if not, it could be useful in some applications have have a  [Quiic](https://www.sparkfun.com/Qwiic) connector available for expansion.

quorten, 2024-08-24:
I looked at the board and it should be fairly straightforward to free up the I2C GPIOs.  Some other useful pins we already have free, a few others should probably be freed up.  Here are my notes:

* BCM2 (pin 3) and BCM3 (pin 5) should be freed up to allow for use of I2C1 in ALT0 function selection.  BCM5 (pin 29) and BCM7 (pin 26) can be used instead for pi-parport.

* BCM14 (pin 8) and BCM15 (pin 10) should be kept free to allow for use of UART0 in ALT0 function selection.

* BCM16 (pin 36) should be kept free, BCM17 (pin 11) should be freed up to allow for use of RTS-CTS hardware handshaking on UART0 in ALT3 function selection.  BCM27 (pin 13) can be used instead for pi-parport.

* BCM12 (pin 32) should be kept free to allow for use of PWM0 in ALT0 function selection.

garlick, 2024-08-24:
Nice analysis, thanks!

I suppose we can distribute two DT overlays, one for the older boards and one for the newer and select them with the EEPROM.

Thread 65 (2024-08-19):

add cutouts for camera/display/pcie

garlick, 2024-08-19:
Problem: our board does not have cutouts that would let the pi's camera/display/pcie FPCs be accessed.

If we have the space we should add these cutouts.

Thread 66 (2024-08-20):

handle standby mode

garlick, 2024-08-20:
Problem: the HAT+ spec describes standby mode, where 5V is powered and 3V3 is not.

https://datasheets.raspberrypi.com/hat/hat-plus-specification.pdf

Since the [74LVC16128](https://www.ti.com/lit/ds/symlink/sn74lvc161284.pdf) is powered by both 3V3 and 5V, having it only partially powered up when the pi is in standby might be bad?  I didn't spot anything about this in a quick skim of the data sheet.

If we need to switch off 5V when 3V3 is off, we can add a load switch such as the [TPS27081](https://www.ti.com/lit/ds/symlink/tps27081a.pdf)

quorten, 2024-08-21:
When all power is removed from the [74LVC16128](https://www.ti.com/lit/ds/symlink/sn74lvc161284.pdf), this chip does seem to provide ESD protection.  A low-current continuity test on the chip outputs when powered off makes them appear as if they are bridge together (probably bridged with ground).

I would assume pi-parport can handle going into standby mode fine.  It's just that there wouldn't be ESD protection from the transmission line equivalent to that of power-off.  The load switch would make for a better design, at a somewhat higher complexity and cost.

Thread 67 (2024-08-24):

consider the SMT version of the 40 pin GPIO header

garlick, 2024-08-24:
Problem: the raspi cooler is almost required for the pi5 which necessitates mounting a HAT+ with 15mm (16mm recommended) clearance per the [HAT+ spec](https://datasheets.raspberrypi.com/hat/hat-plus-specification.pdf).

It seems like modern HATs often use a SMT 40-pin socket and ship with a stackable extension.  That also allows multiple HATs to be stacked.

Shall we go with a 40 pin SMT header?

quorten, 2024-08-26:
Tough question to think about.

On one hand, keeping to through-hole may make it easier to swap it out with other parts for folks assembling their own circuit boards.  Then again, there are the older revs for reference that folks have sometimes referred to.

I think the benefits are worth giving a 40-pin SMT header a try.

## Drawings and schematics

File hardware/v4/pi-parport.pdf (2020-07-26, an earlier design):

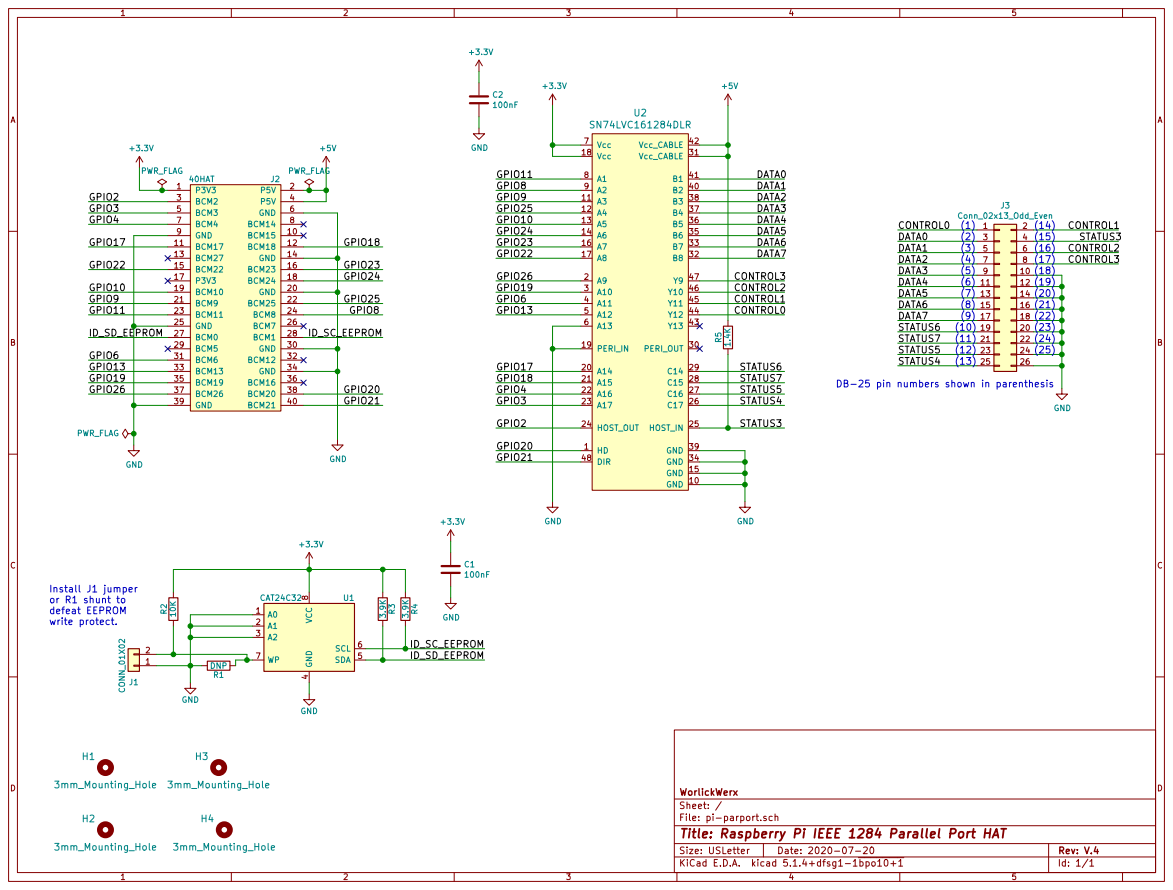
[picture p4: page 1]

(2) 3 | 4 (15)
(3) 5 | 6 (16)
(4) 7 | (17) 8

GPIO24

(6) 11 | | (19) 12
(7) 13 | | 14 (20)
(8) 15 | | 16 (21)
(9) 17 | | (22) 18
(10) 19 | | 20 (23)

(12) 23 | 24 (25)
(13) 25 | 26

DB-25 pin numbers shown in parenthesis

Install J1 jumper or R1 shunt to

File: pi-parport.sch Sheet: / WorlickWerx

Id: 1/1 Title: Raspberry Pi IEEE 1284 Parallel Port HAT

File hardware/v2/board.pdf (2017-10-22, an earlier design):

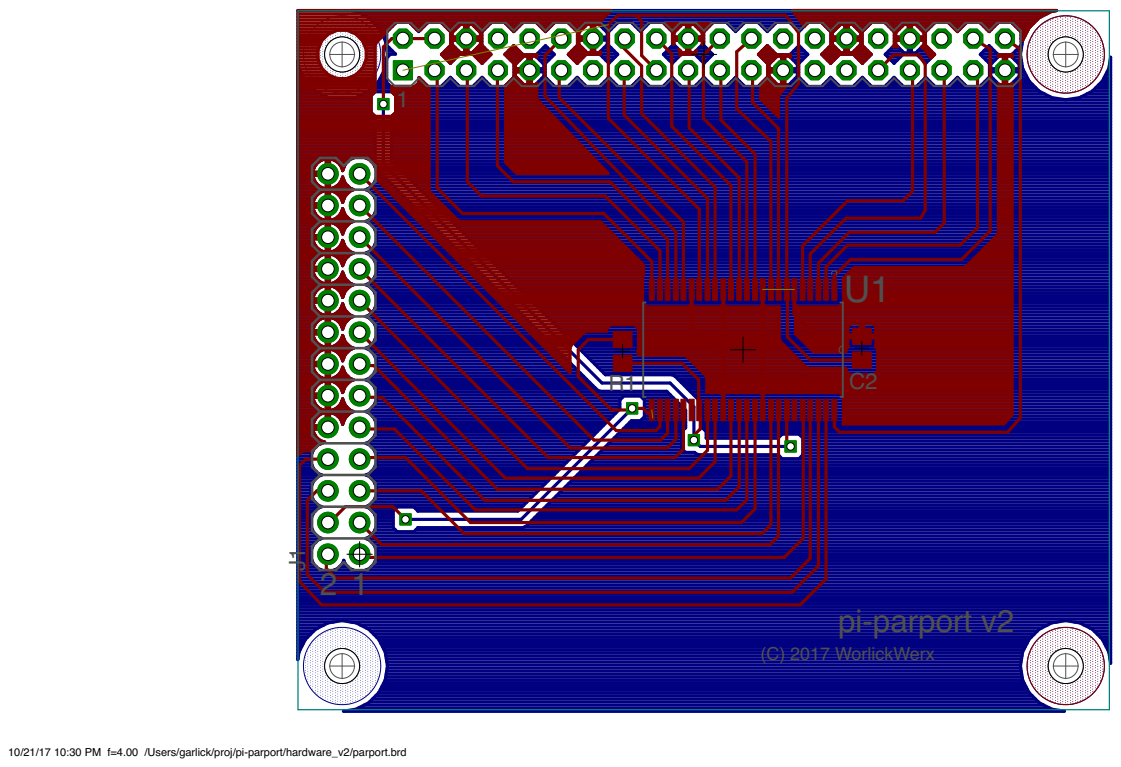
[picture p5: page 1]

10/21/17 10:30 PM f=4.00 /Users/garlick/proj/pi-parport/hardware_v2/parport.brd

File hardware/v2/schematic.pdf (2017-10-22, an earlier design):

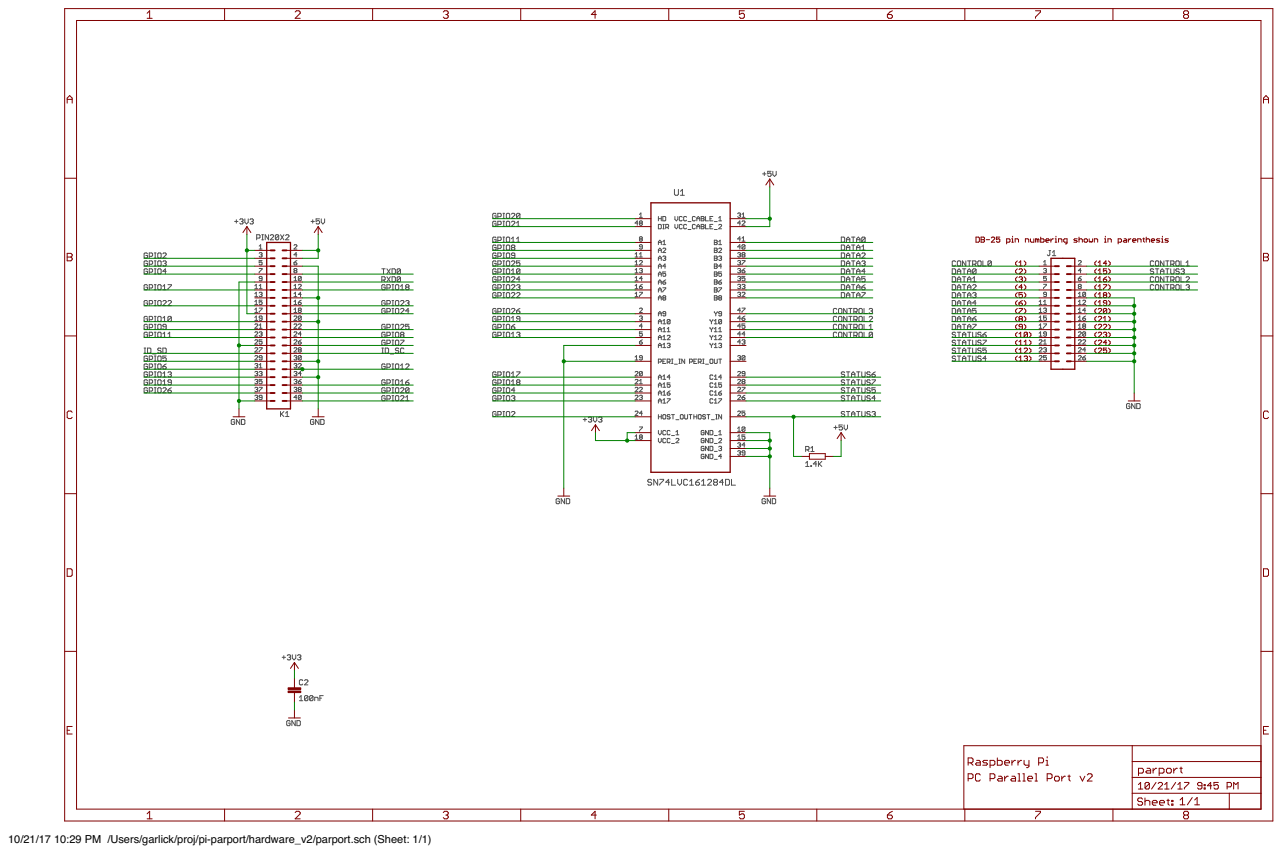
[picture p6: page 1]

10/21/17 10:29 PM /Users/garlick/proj/pi-parport/hardware_v2/parport.sch (Sheet: 1/1)

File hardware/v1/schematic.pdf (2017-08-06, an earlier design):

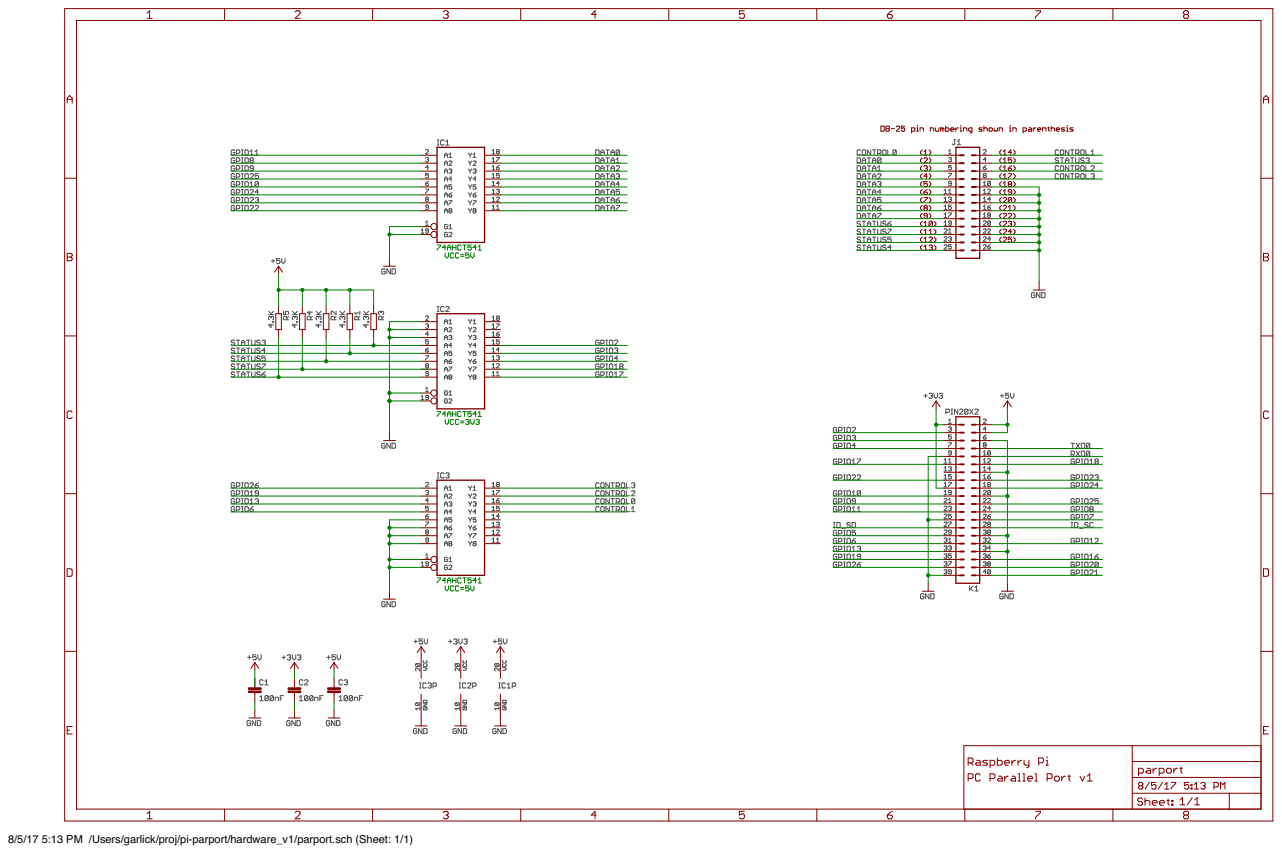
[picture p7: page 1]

8/5/17 5:13 PM /Users/garlick/proj/pi-parport/hardware_v1/parport.sch (Sheet: 1/1)

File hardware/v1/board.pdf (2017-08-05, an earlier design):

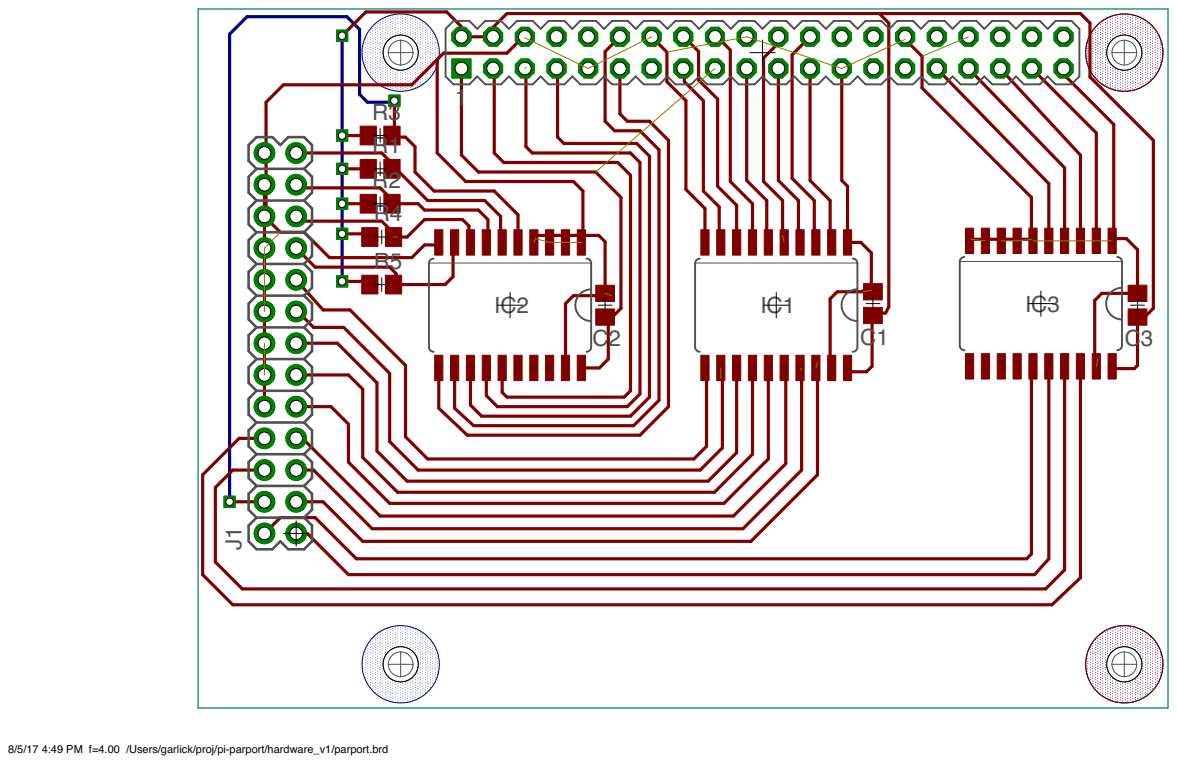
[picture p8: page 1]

8/5/17 4:49 PM f=4.00 /Users/garlick/proj/pi-parport/hardware_v1/parport.brd

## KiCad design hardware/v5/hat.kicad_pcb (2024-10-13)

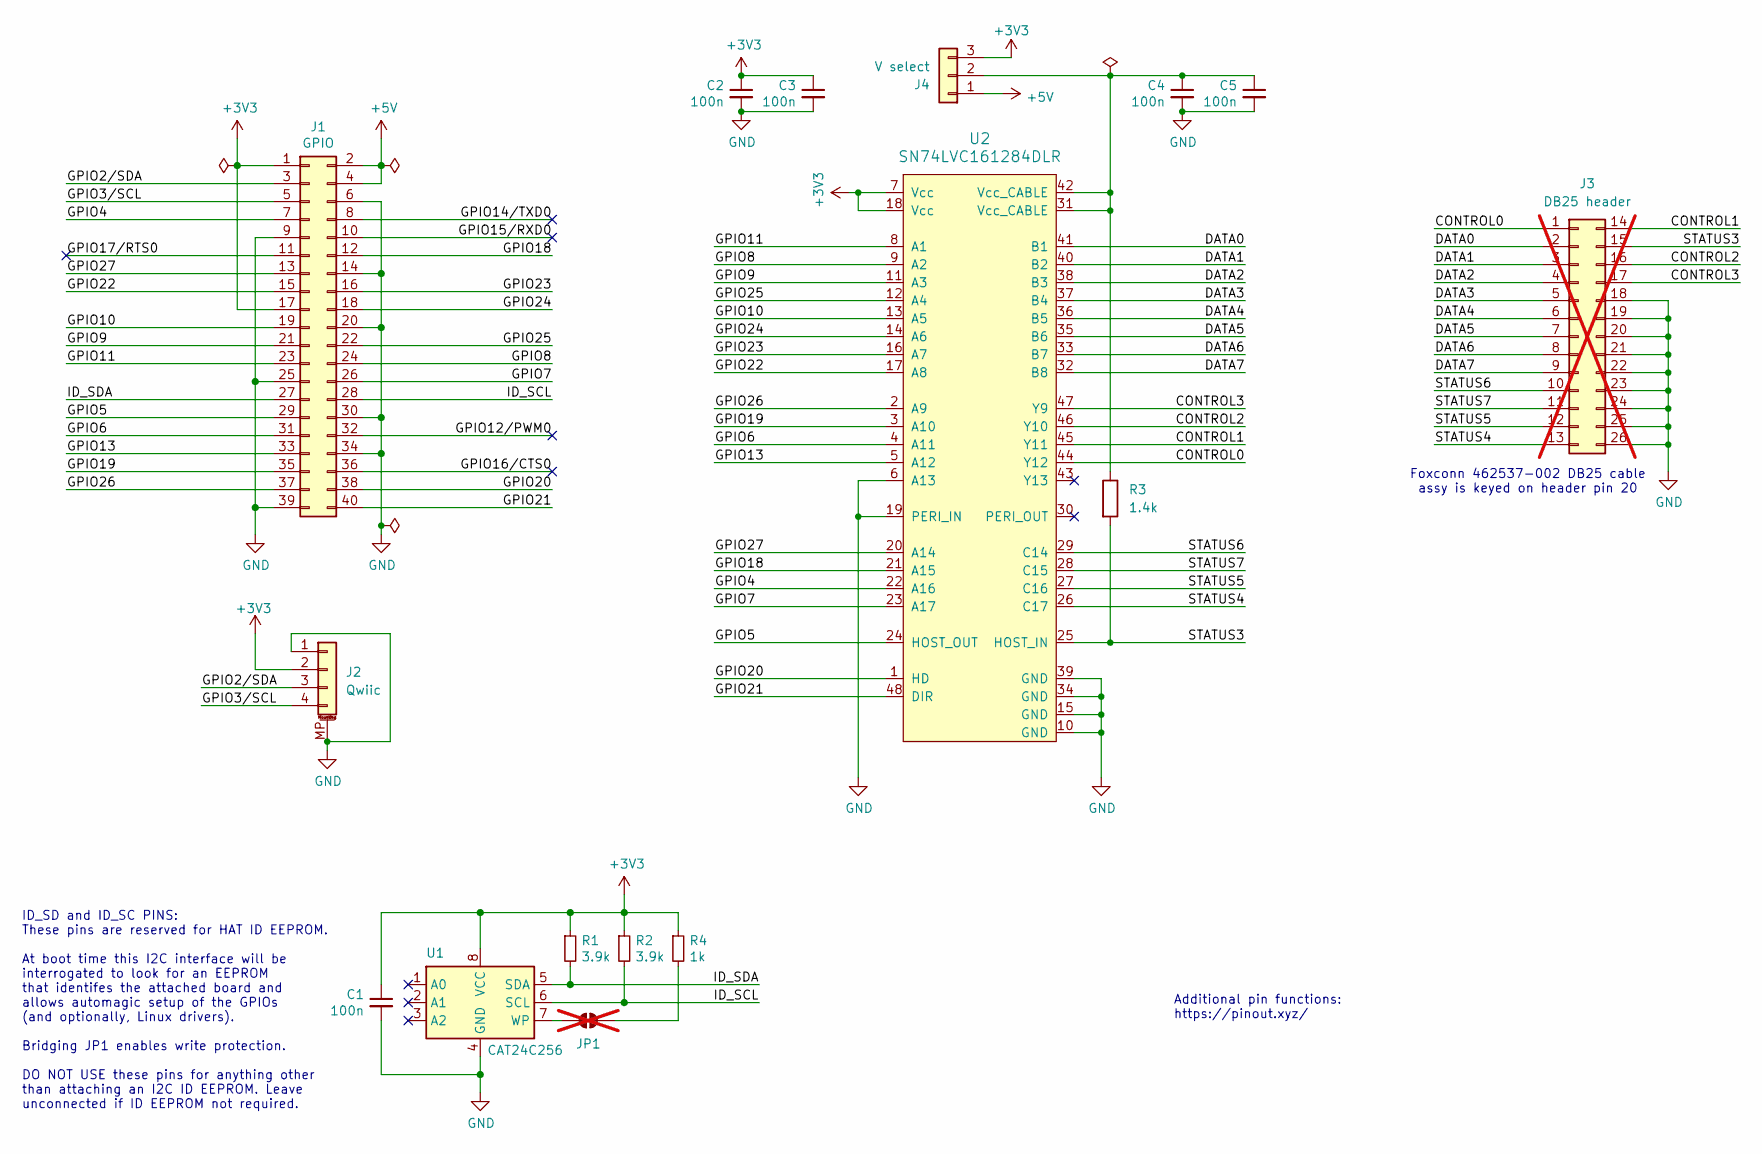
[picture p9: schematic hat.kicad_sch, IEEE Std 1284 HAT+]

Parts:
C1, C2, C3, C4, C5: 100n; C_0603_1608Metric; LCSC C346189
J1: GPIO; Harwin_M20-7812045_2x20_P2.54mm_Vertical; LCSC C2685112
J2: Qwiic; JST_SH_SM04B-SRSS-TB_1x04-1MP_P1.00mm_Horizontal; LCSC C2845363
J3: DB25 header; DB25_header_2x13_P2.54mm_horizontal; not fitted
J4: V select; PinHeader_1x03_P2.54mm_Vertical_SMD_Pin1Left; LCSC C2883760
JP1: ID_WP; SolderJumper-2_P1.3mm_Open_RoundedPad1.0x1.5mm; not fitted
R1, R2: 3.9k; R_0603_1608Metric; LCSC C114616
R3: 1.4k; R_0603_1608Metric; LCSC C185359
R4: 1k; R_0603_1608Metric; LCSC C21190
U1: CAT24C256; SOIC-8_3.9x4.9mm_P1.27mm; LCSC C79987
U2: SN74LVC161284DLR; SSOP-48_7.5x15.9mm_P0.635mm; Mouser 595-SN74LVC161284DLR

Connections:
+3V3: C1.1, C2.1, C3.1, J1.1, J1.17, J2.2, J4.3, R1.1, R2.1, R4.1, U1.8 (VCC), U2.7 (Vcc), U2.18 (Vcc)
+5V: J1.2, J1.4, J4.1
/CONTROL0: J3.1, U2.44 (Y12)
/CONTROL1: J3.14, U2.45 (Y11)
/CONTROL2: J3.16, U2.46 (Y10)
/CONTROL3: J3.17, U2.47 (Y9)
/DATA0: J3.2, U2.41 (B1)
/DATA1: J3.3, U2.40 (B2)
/DATA2: J3.4, U2.38 (B3)
/DATA3: J3.5, U2.37 (B4)
/DATA4: J3.6, U2.36 (B5)
/DATA5: J3.7, U2.35 (B6)
/DATA6: J3.8, U2.33 (B7)
/DATA7: J3.9, U2.32 (B8)
/GPIO2/SDA: J1.3, J2.3
/GPIO3/SCL: J1.5, J2.4
/GPIO4: J1.7, U2.22 (A16)
/GPIO5: J1.29, U2.24 (HOST_OUT)
/GPIO6: J1.31, U2.4 (A11)
/GPIO7: J1.26, U2.23 (A17)
/GPIO8: J1.24, U2.9 (A2)
/GPIO9: J1.21, U2.11 (A3)
/GPIO10: J1.19, U2.13 (A5)
/GPIO11: J1.23, U2.8 (A1)
/GPIO12/PWM0: J1.32
/GPIO13: J1.33, U2.5 (A12)
/GPIO14/TXD0: J1.8
/GPIO15/RXD0: J1.10
/GPIO16/CTS0: J1.36
/GPIO17/RTS0: J1.11
/GPIO18: J1.12, U2.21 (A15)
/GPIO19: J1.35, U2.3 (A10)
/GPIO20: J1.38, U2.1 (HD)
/GPIO21: J1.40, U2.48 (DIR)
/GPIO22: J1.15, U2.17 (A8)
/GPIO23: J1.16, U2.16 (A7)
/GPIO24: J1.18, U2.14 (A6)
/GPIO25: J1.22, U2.12 (A4)
/GPIO26: J1.37, U2.2 (A9)
/GPIO27: J1.13, U2.20 (A14)
/ID_SCL: J1.28, R2.2, U1.6 (SCL)
/ID_SDA: J1.27, R1.2, U1.5 (SDA)
/STATUS3: J3.15, R3.2, U2.25 (HOST_IN)
/STATUS4: J3.13, U2.26 (C17)
/STATUS5: J3.12, U2.27 (C16)
/STATUS6: J3.10, U2.29 (C14)
/STATUS7: J3.11, U2.28 (C15)
GND: C1.2, C2.2, C3.2, C4.2, C5.2, J1.6, J1.9, J1.14, J1.20, J1.25, J1.30, J1.34, J1.39, J2.1, J2.MP (MountPin), J3.18, J3.19, J3.20, J3.21, J3.22, J3.23, J3.24, J3.25, J3.26, U1.4 (GND), U2.6 (A13), U2.10 (GND), U2.15 (GND), U2.19 (PERI_IN), U2.34 (GND), U2.39 (GND)
unnamed: C4.1, C5.1, J4.2, R3.1, U2.31 (Vcc_CABLE), U2.42 (Vcc_CABLE)
unnamed: JP1.1 (A), U1.7 (WP)
unnamed: JP1.2 (B), R4.2

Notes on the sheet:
Additional pin functions: https://pinout.xyz/
ID_SD and ID_SC PINS: These pins are reserved for HAT ID EEPROM. At boot time this I2C interface will be interrogated to look for an EEPROM that identifes the attached board and allows automagic setup of the GPIOs (and optionally, Linux drivers). Bridging JP1 enables write protection. DO NOT USE th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
Foxconn 462537-002 DB25 cable assy is keyed on header pin 20

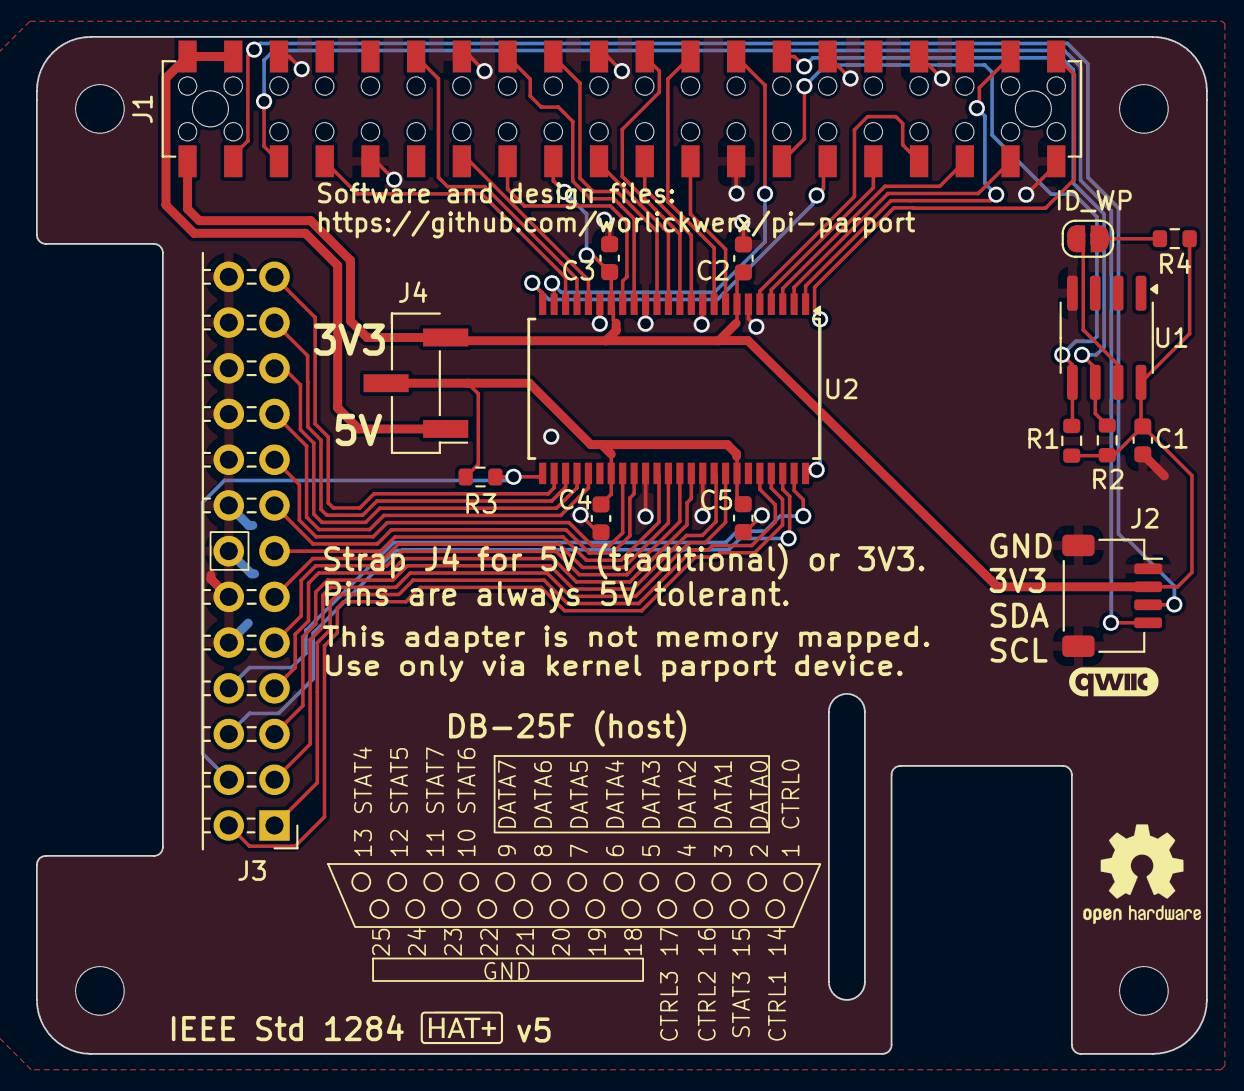
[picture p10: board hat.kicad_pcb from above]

Board: 2 copper layers, 65.0 x 56.5 mm, 20 parts (0 on the bottom side), 46 nets.

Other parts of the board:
MH1, MH2, MH3, MH4: MountingHole_2.7mm_M2.5

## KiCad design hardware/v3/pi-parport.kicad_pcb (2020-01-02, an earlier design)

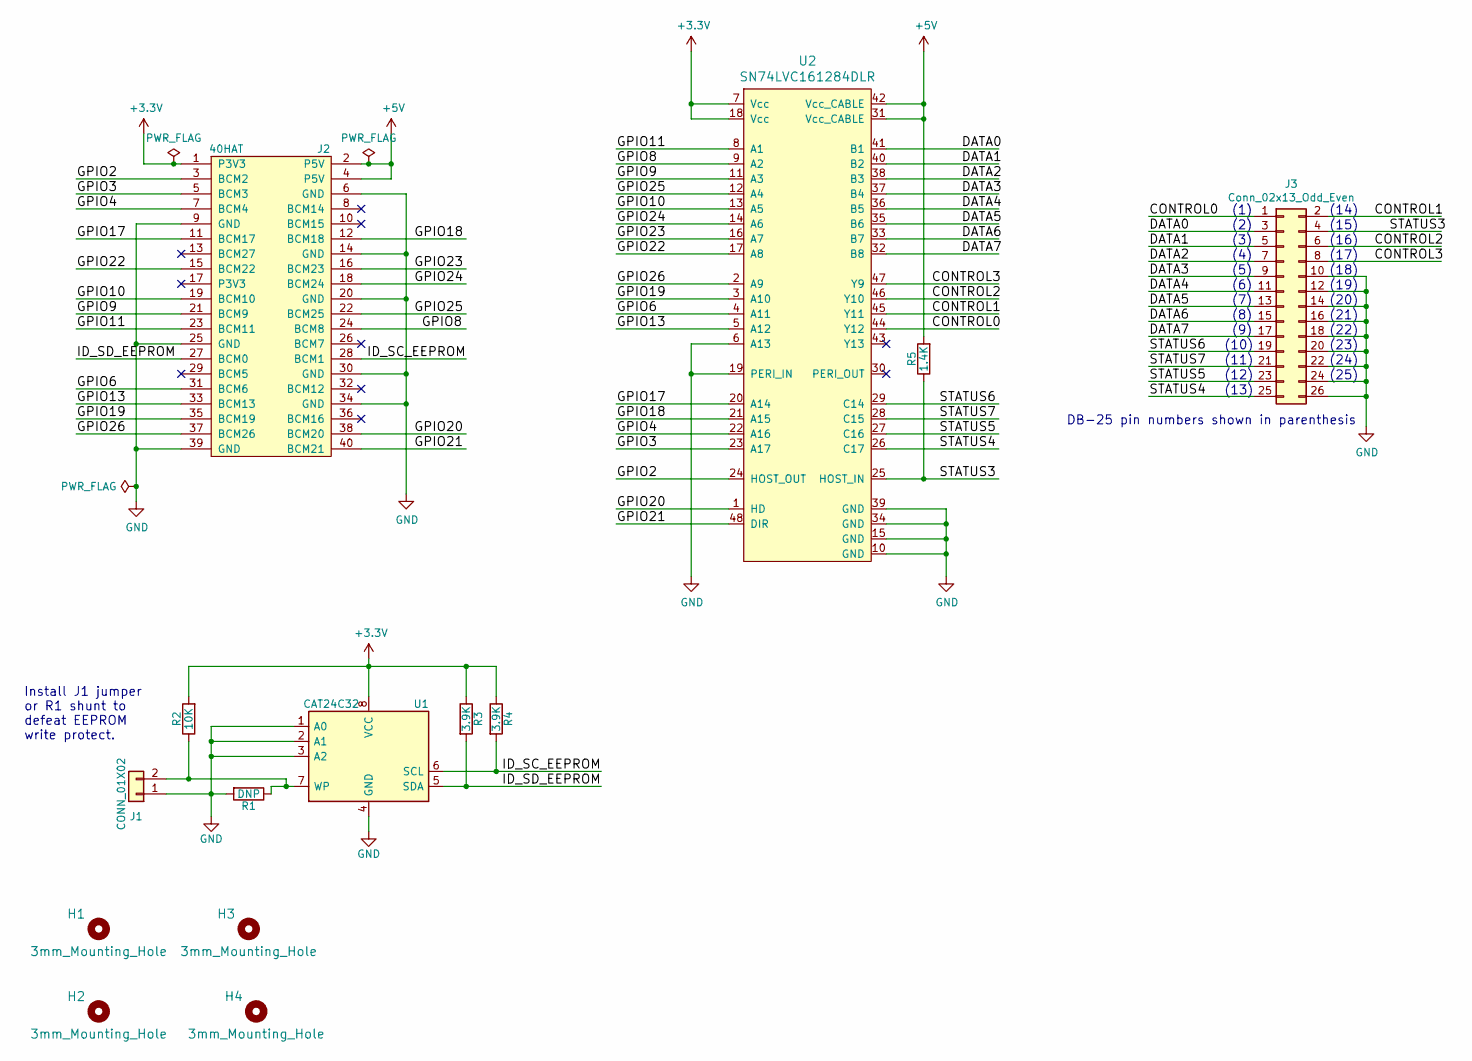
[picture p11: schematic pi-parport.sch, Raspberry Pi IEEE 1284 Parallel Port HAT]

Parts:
H1, H2, H3, H4: 3mm_Mounting_Hole; NPTH_3mm_ID
J1: CONN_01X02; PinHeader_1x02_P2.54mm_Vertical; MPN M20-9990246; Digi-Key_PN 952-2262-ND
J2: 40HAT; PinSocket_2x20_P2.54mm_Vertical; MPN NPPN202AFCN-RC; Digi-Key_PN S5750-20-ND
J3: Conn_02x13_Odd_Even; PinHeader_2x13_P2.54mm_Horizontal; MPN 0877602616; Digi-Key_PN 23-0877602616-ND
R1: DNP; R_0805_2012Metric_Pad1.15x1.40mm_HandSolder
R2: 10K; R_0805_2012Metric_Pad1.15x1.40mm_HandSolder; MPN ERJ-6ENF1002V; Digi-Key_PN P10.0KCCT-ND
R3, R4: 3.9K; R_0805_2012Metric_Pad1.15x1.40mm_HandSolder; MPN ERJ-6ENF3901V; Digi-Key_PN P3.90KCCT-ND
R5: 1.4K; R_0805_2012Metric_Pad1.15x1.40mm_HandSolder; MPN ERJ-6ENF1401V; Digi-Key_PN P1.40KCCT-ND
U1: CAT24C32; SO-8_3.9x4.9mm_P1.27mm; MPN CAT24C32WI-GT3; Digi-Key_PN CAT24C32WI-GT3CT-ND
U2: SN74LVC161284DLR; SSOP-48_7.5x15.9mm_P0.635mm; MPN SN74LVC161284DLR; Digi-Key_PN 296-8467-1-ND

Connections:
+3V3: J2.1 (P3V3), R2.2, R3.1, R4.1, U1.8 (VCC), U2.7 (Vcc), U2.18 (Vcc)
+5V: J2.2 (P5V), J2.4 (P5V), R5.2, U2.31 (Vcc_CABLE), U2.42 (Vcc_CABLE)
/CONTROL0: J3.1, U2.44 (Y12)
/CONTROL1: J3.2, U2.45 (Y11)
/CONTROL2: J3.6, U2.46 (Y10)
/CONTROL3: J3.8, U2.47 (Y9)
/DATA0: J3.3, U2.41 (B1)
/DATA1: J3.5, U2.40 (B2)
/DATA2: J3.7, U2.38 (B3)
/DATA3: J3.9, U2.37 (B4)
/DATA4: J3.11, U2.36 (B5)
/DATA5: J3.13, U2.35 (B6)
/DATA6: J3.15, U2.33 (B7)
/DATA7: J3.17, U2.32 (B8)
/GPIO2: J2.3 (BCM2), U2.24 (HOST_OUT)
/GPIO3: J2.5 (BCM3), U2.23 (A17)
/GPIO4: J2.7 (BCM4), U2.22 (A16)
/GPIO6: J2.31 (BCM6), U2.4 (A11)
/GPIO8: J2.24 (BCM8), U2.9 (A2)
/GPIO9: J2.21 (BCM9), U2.11 (A3)
/GPIO10: J2.19 (BCM10), U2.13 (A5)
/GPIO11: J2.23 (BCM11), U2.8 (A1)
/GPIO13: J2.33 (BCM13), U2.5 (A12)
/GPIO17: J2.11 (BCM17), U2.20 (A14)
/GPIO18: J2.12 (BCM18), U2.21 (A15)
/GPIO19: J2.35 (BCM19), U2.3 (A10)
/GPIO20: J2.38 (BCM20), U2.1 (HD)
/GPIO21: J2.40 (BCM21), U2.48 (DIR)
/GPIO22: J2.15 (BCM22), U2.17 (A8)
/GPIO23: J2.16 (BCM23), U2.16 (A7)
/GPIO24: J2.18 (BCM24), U2.14 (A6)
/GPIO25: J2.22 (BCM25), U2.12 (A4)
/GPIO26: J2.37 (BCM26), U2.2 (A9)
/ID_SC_EEPROM: J2.28 (BCM1), R4.2, U1.6 (SCL)
/ID_SD_EEPROM: J2.27 (BCM0), R3.2, U1.5 (SDA)
/STATUS3: J3.4, R5.1, U2.25 (HOST_IN)
/STATUS4: J3.25, U2.26 (C17)
/STATUS5: J3.23, U2.27 (C16)
/STATUS6: J3.19, U2.29 (C14)
/STATUS7: J3.21, U2.28 (C15)
GND: J1.1, J2.6 (GND), J2.9 (GND), J2.14 (GND), J2.20 (GND), J2.25 (GND), J2.30 (GND), J2.34 (GND), J2.39 (GND), J3.10, J3.12, J3.14, J3.16, J3.18, J3.20, J3.22, J3.24, J3.26, R1.2, U1.1 (A0), U1.2 (A1), U1.3 (A2), U1.4 (GND), U2.6 (A13), U2.10 (GND), U2.15 (GND), U2.19 (PERI_IN), U2.34 (GND), U2.39 (GND)
unnamed: J1.2, R1.1, R2.1, U1.7 (WP)

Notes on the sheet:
(1)
(2)
(3)
(4)
(5)
(6)
(7)
(8)
(9)
(10)
(11)
(12)
(13)
(14)
(15)
(16)
(17)
(18)
(19)
(20)
(21)
(22)
(23)
(24)
(25)
DB-25 pin numbers shown in parenthesis
Install J1 jumper or R1 shunt to defeat EEPROM write protect.

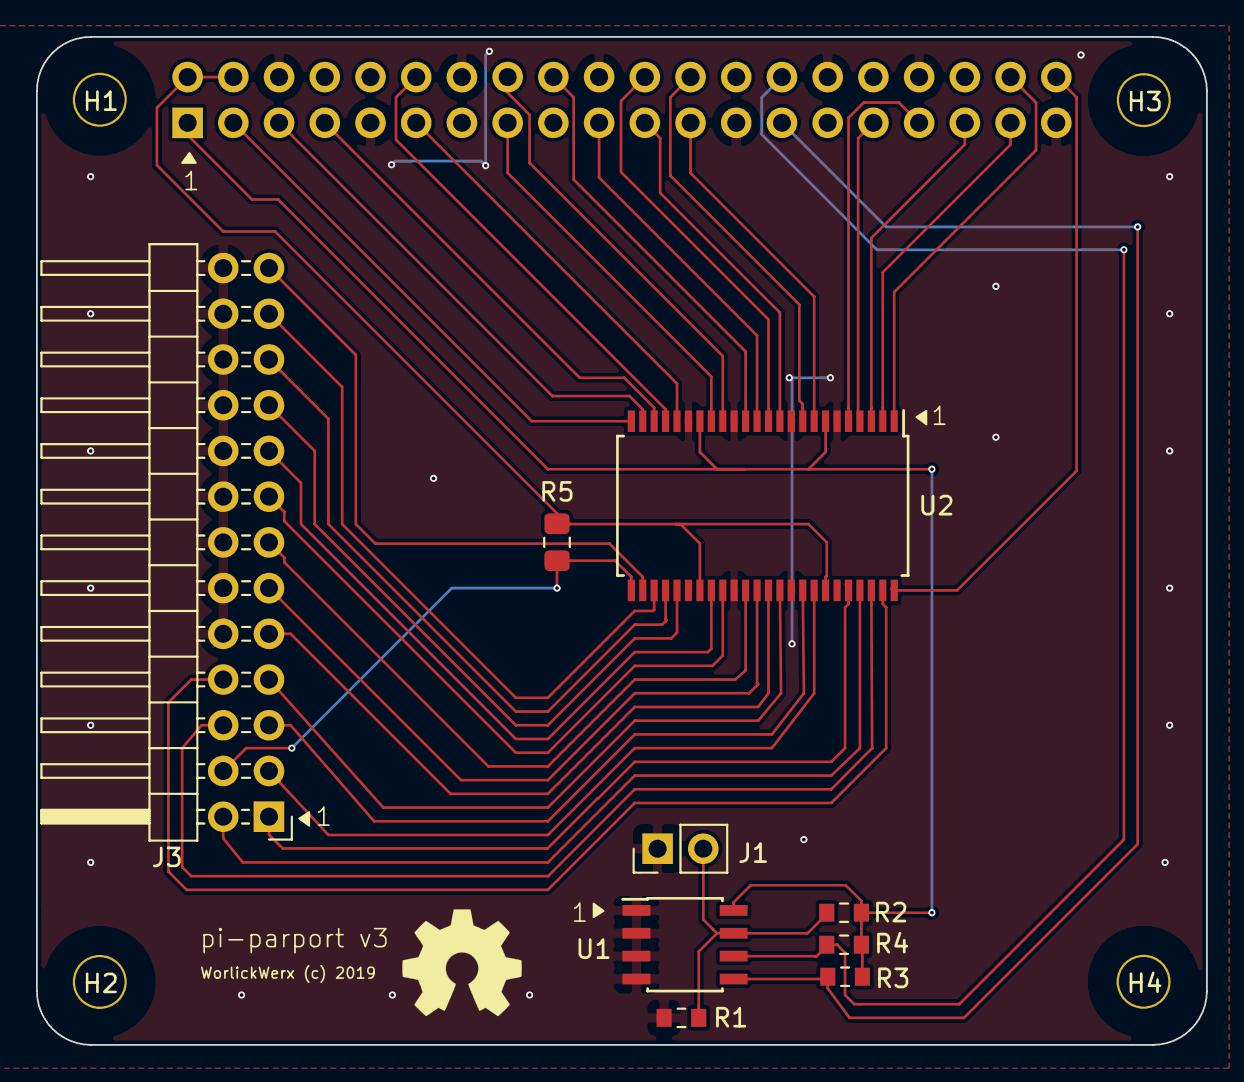
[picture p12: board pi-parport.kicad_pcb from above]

Board: 2 copper layers, 65.0 x 56.0 mm, 14 parts (1 on the bottom side), 42 nets.

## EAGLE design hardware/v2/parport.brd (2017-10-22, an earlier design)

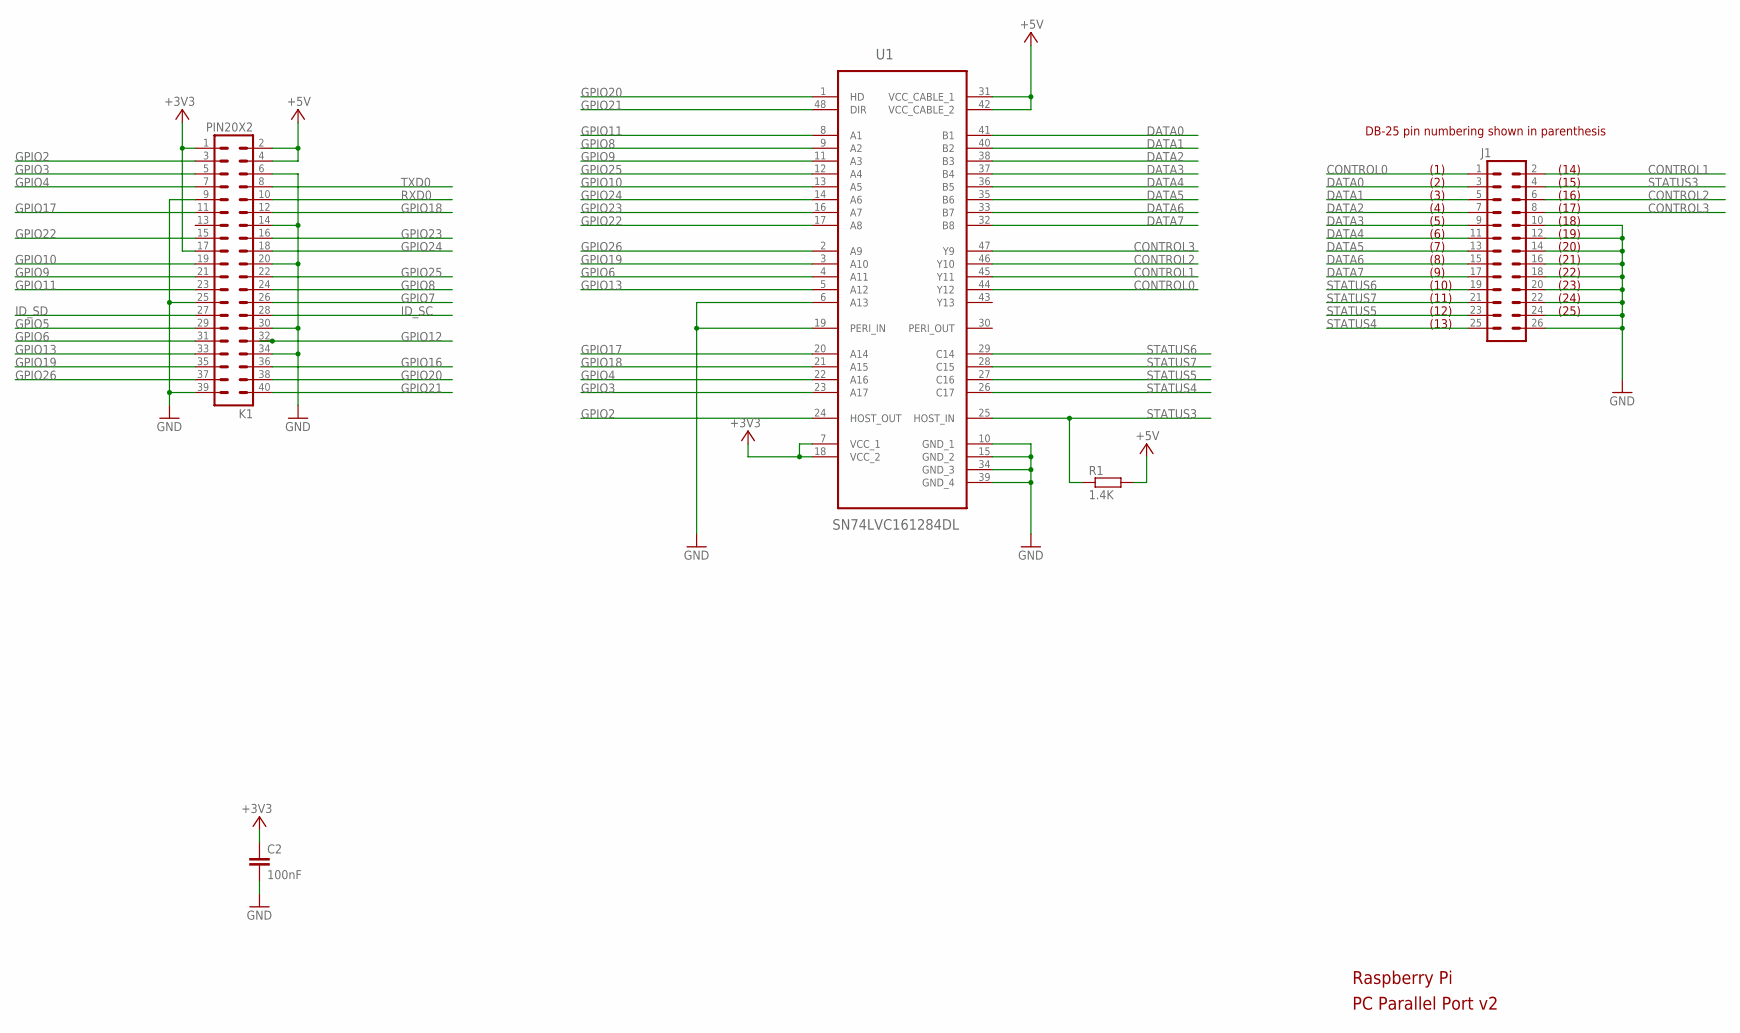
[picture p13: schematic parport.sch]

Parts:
C2: 100nF; C0805
J1: M13X22X13; 2X13
K1: PIN20X2; PIN_20X2
R1: 1.4K; R0805
U1: SN74LVC161284DL; SOP63P1035X279-48N

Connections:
+3V3: C2.1, K1.1, K1.17, U1.7 (VCC_1), U1.18 (VCC_2)
+5V: K1.2, K1.4, R1.2, U1.31 (VCC_CABLE_1), U1.42 (VCC_CABLE_2)
CONTROL0: J1.1, U1.44 (Y12)
CONTROL1: J1.2, U1.45 (Y11)
CONTROL2: J1.6, U1.46 (Y10)
CONTROL3: J1.8, U1.47 (Y9)
DATA0: J1.3, U1.41 (B1)
DATA1: J1.5, U1.40 (B2)
DATA2: J1.7, U1.38 (B3)
DATA3: J1.9, U1.37 (B4)
DATA4: J1.11, U1.36 (B5)
DATA5: J1.13, U1.35 (B6)
DATA6: J1.15, U1.33 (B7)
DATA7: J1.17, U1.32 (B8)
GND: C2.2, J1.10, J1.12, J1.14, J1.16, J1.18, J1.20, J1.22, J1.24, J1.26, K1.6, K1.9, K1.14, K1.20, K1.25, K1.30, K1.34, K1.39, U1.6 (A13), U1.10 (GND_1), U1.15 (GND_2), U1.19 (PERI_IN), U1.34 (GND_3), U1.39 (GND_4)
GPIO2: K1.3, U1.24 (HOST_OUT)
GPIO3: K1.5, U1.23 (A17)
GPIO4: K1.7, U1.22 (A16)
GPIO5: K1.29
GPIO6: K1.31, U1.4 (A11)
GPIO7: K1.26
GPIO8: K1.24, U1.9 (A2)
GPIO9: K1.21, U1.11 (A3)
GPIO10: K1.19, U1.13 (A5)
GPIO11: K1.23, U1.8 (A1)
GPIO12: K1.32
GPIO13: K1.33, U1.5 (A12)
GPIO16: K1.36
GPIO17: K1.11, U1.20 (A14)
GPIO18: K1.12, U1.21 (A15)
GPIO19: K1.35, U1.3 (A10)
GPIO20: K1.38, U1.1 (HD)
GPIO21: K1.40, U1.48 (DIR)
GPIO22: K1.15, U1.17 (A8)
GPIO23: K1.16, U1.16 (A7)
GPIO24: K1.18, U1.14 (A6)
GPIO25: K1.22, U1.12 (A4)
GPIO26: K1.37, U1.2 (A9)
ID_SC: K1.28
ID_SD: K1.27
RXD0: K1.10
STATUS3: J1.4, R1.1, U1.25 (HOST_IN)
STATUS4: J1.25, U1.26 (C17)
STATUS5: J1.23, U1.27 (C16)
STATUS6: J1.19, U1.29 (C14)
STATUS7: J1.21, U1.28 (C15)
TXD0: K1.8

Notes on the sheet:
Raspberry Pi
PC Parallel Port v2
(1)
(2)
(3)
(4)
(5)
(6)
(7)
(8)
(9)
(10)
(11)
(12)
(13)
(14)
(15)
(17)
(18)
(19)
(20)
(21)
(22)
(23)
(24)
(25)
(16)
DB-25 pin numbering shown in parenthesis

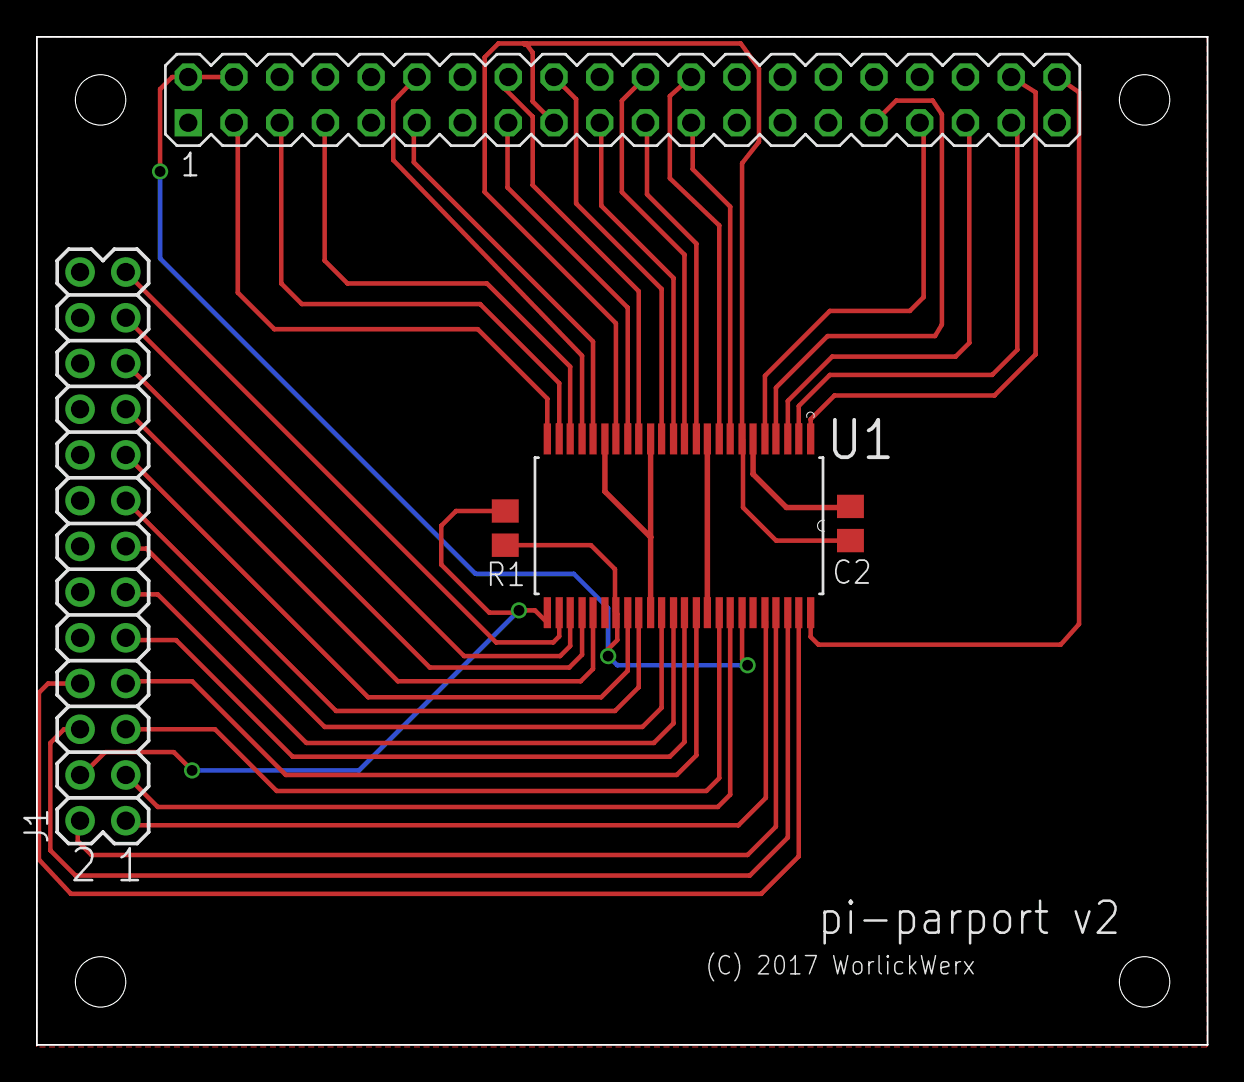
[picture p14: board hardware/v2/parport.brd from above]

Board: 2 copper layers, 65.0 x 56.0 mm, 5 parts (0 on the bottom side), 39 nets.

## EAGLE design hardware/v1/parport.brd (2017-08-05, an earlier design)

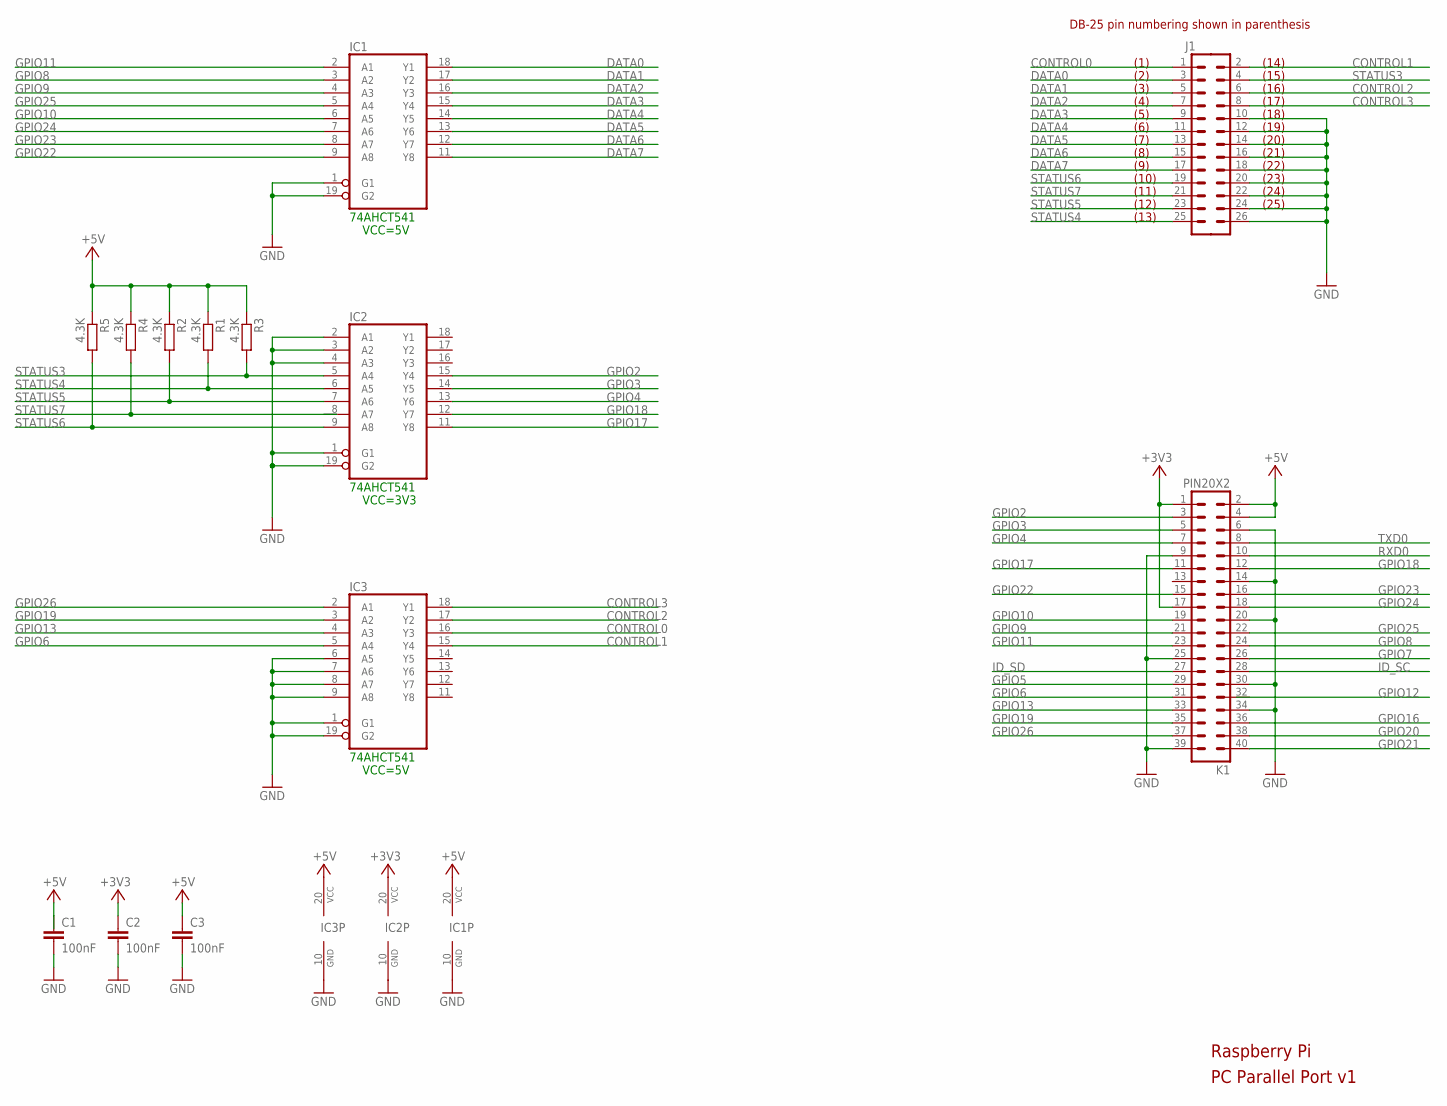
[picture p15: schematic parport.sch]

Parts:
C1, C2, C3: 100nF; C0805
IC1, IC2, IC3: 74LS541DW; SO20W
J1: M13X22X13; 2X13
K1: PIN20X2; PIN_20X2
R1, R2, R3, R4, R5: 4.3K; R0805

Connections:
+3V3: C2.1, IC2.20 (VCC), K1.1, K1.17
+5V: C1.1, C3.1, IC1.20 (VCC), IC3.20 (VCC), K1.2, K1.4, R1.1, R2.1, R3.1, R4.1, R5.1
CONTROL0: IC3.16 (Y3), J1.1
CONTROL1: IC3.15 (Y4), J1.2
CONTROL2: IC3.17 (Y2), J1.6
CONTROL3: IC3.18 (Y1), J1.8
DATA0: IC1.18 (Y1), J1.3
DATA1: IC1.17 (Y2), J1.5
DATA2: IC1.16 (Y3), J1.7
DATA3: IC1.15 (Y4), J1.9
DATA4: IC1.14 (Y5), J1.11
DATA5: IC1.13 (Y6), J1.13
DATA6: IC1.12 (Y7), J1.15
DATA7: IC1.11 (Y8), J1.17
GND: C1.2, C2.2, C3.2, IC1.1 (G1), IC1.10 (GND), IC1.19 (G2), IC2.1 (G1), IC2.2 (A1), IC2.3 (A2), IC2.4 (A3), IC2.10 (GND), IC2.19 (G2), IC3.1 (G1), IC3.6 (A5), IC3.7 (A6), IC3.8 (A7), IC3.9 (A8), IC3.10 (GND), IC3.19 (G2), J1.10, J1.12, J1.14, J1.16, J1.18, J1.20, J1.22, J1.24, J1.26, K1.6, K1.9, K1.14, K1.20, K1.25, K1.30, K1.34, K1.39
GPIO2: IC2.15 (Y4), K1.3
GPIO3: IC2.14 (Y5), K1.5
GPIO4: IC2.13 (Y6), K1.7
GPIO5: K1.29
GPIO6: IC3.5 (A4), K1.31
GPIO7: K1.26
GPIO8: IC1.3 (A2), K1.24
GPIO9: IC1.4 (A3), K1.21
GPIO10: IC1.6 (A5), K1.19
GPIO11: IC1.2 (A1), K1.23
GPIO13: IC3.4 (A3), K1.33
GPIO16: K1.36
GPIO17: IC2.11 (Y8), K1.11
GPIO18: IC2.12 (Y7), K1.12
GPIO19: IC3.3 (A2), K1.35
GPIO20: K1.38
GPIO21: K1.40
GPIO22: IC1.9 (A8), K1.15
GPIO23: IC1.8 (A7), K1.16
GPIO24: IC1.7 (A6), K1.18
GPIO25: IC1.5 (A4), K1.22
GPIO26: IC3.2 (A1), K1.37
ID_SC: K1.28
ID_SD: K1.27
RXD0: K1.10
STATUS3: IC2.5 (A4), J1.4, R3.2
STATUS4: IC2.6 (A5), J1.25, R1.2
STATUS5: IC2.7 (A6), J1.23, R2.2
STATUS6: IC2.9 (A8), J1.19, R5.2
STATUS7: IC2.8 (A7), J1.21, R4.2
TXD0: K1.8

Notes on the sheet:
Raspberry Pi
PC Parallel Port v1
74AHCT541
VCC=5V
VCC=3V3
(1)
(2)
(3)
(4)
(5)
(6)
(7)
(8)
(9)
(10)
(11)
(12)
(13)
(14)
(15)
(17)
(18)
(19)
(20)
(21)
(22)
(23)
(24)
(25)
(16)
DB-25 pin numbering shown in parenthesis

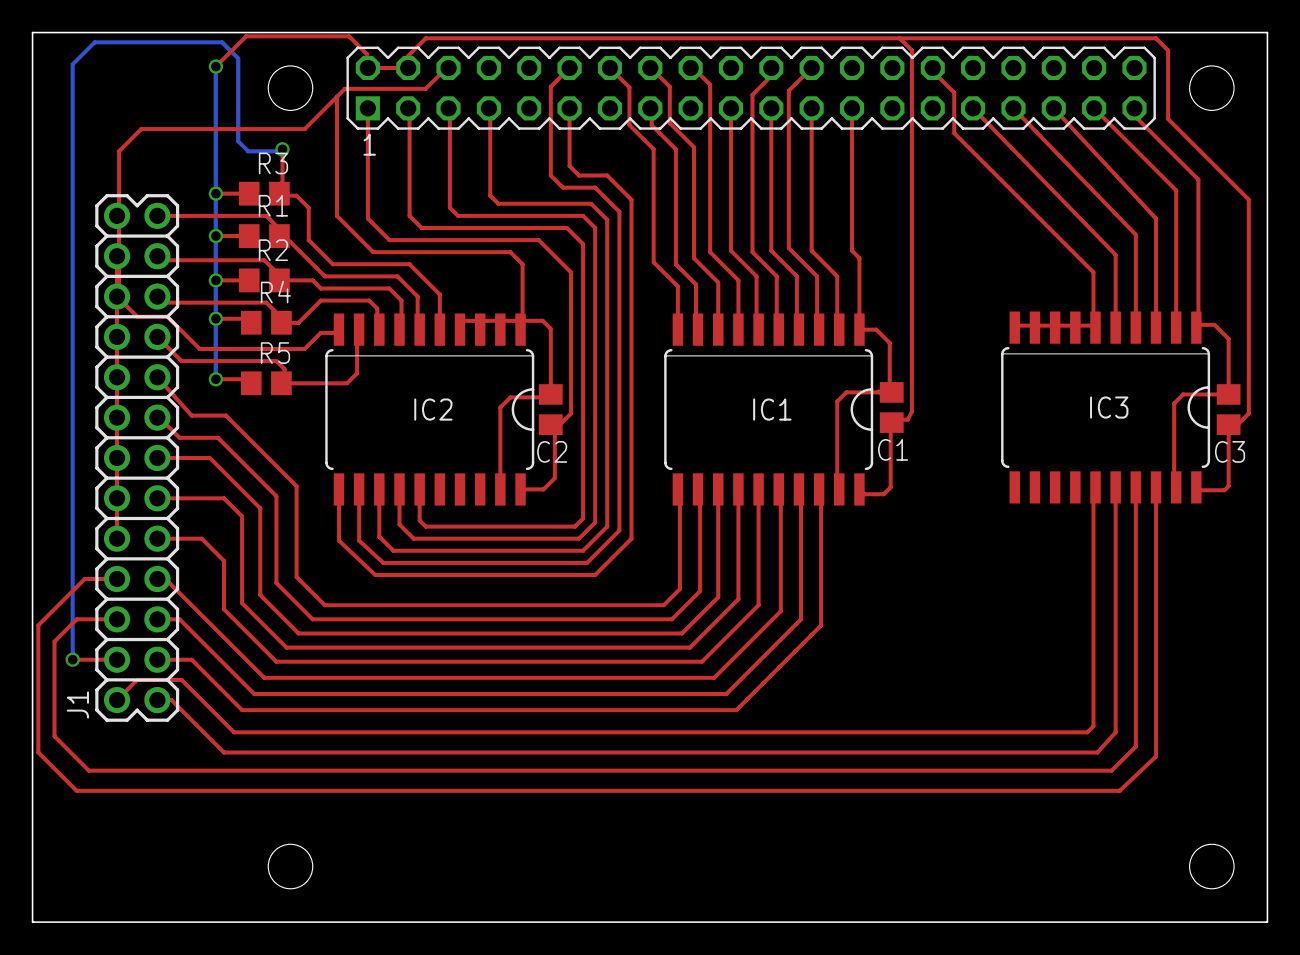
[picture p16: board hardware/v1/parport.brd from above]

Board: 2 copper layers, 77.7 x 56.0 mm, 13 parts (0 on the bottom side), 37 nets.

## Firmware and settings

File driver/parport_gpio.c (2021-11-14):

// SPDX-License-Identifier: GPL-2.0-or-later

/* Low-level parallel port routines for GPIO.
 *
 * Author: Jim Garlick <garlick.jim@gmail.com>
 *
 * Based on parport_sunbpp.c.
 *
 * A PC parallel port style interface is cobbled together from GPIO pins:
 * 8-bit data out, 5-bit status in, 4 bit control out
 * No interrupts or dma; SPP mode only.
 *
 * See https://lwn.net/Articles/533632/ for info on the gpiod_ API used here.
 */

#include <linux/version.h>
#include <linux/module.h>
#include <linux/init.h>
#include <linux/parport.h>
#include <linux/slab.h>
#include <linux/gpio/consumer.h>
#include <linux/of.h>
#include <linux/of_device.h>

struct parport_gpio_ctx {
	struct gpio_descs *data;
	struct gpio_descs *status;
	struct gpio_descs *control;
	struct gpio_desc *hd; // v2 only: 74LVC161284 HD pin
	struct gpio_desc *dir; // v2 only: 74LVC161284 DIR pin
	spinlock_t lock;
};

static unsigned char parport_gpio_read_data(struct parport *p)
{
	struct parport_gpio_ctx *ctx = p->private_data;
	unsigned char data;
	unsigned long flags;

	spin_lock_irqsave(&ctx->lock, flags);

	data = gpiod_get_value(ctx->data->desc[0]);
	data |= (gpiod_get_value(ctx->data->desc[1]) << 1);
	data |= (gpiod_get_value(ctx->data->desc[2]) << 2);
	data |= (gpiod_get_value(ctx->data->desc[3]) << 3);
	data |= (gpiod_get_value(ctx->data->desc[4]) << 4);
	data |= (gpiod_get_value(ctx->data->desc[5]) << 5);
	data |= (gpiod_get_value(ctx->data->desc[6]) << 6);
	data |= (gpiod_get_value(ctx->data->desc[7]) << 7);

	spin_unlock_irqrestore(&ctx->lock, flags);

	return data;
}

static void parport_gpio_write_data(struct parport *p, unsigned char data)
{
	struct parport_gpio_ctx *ctx = p->private_data;
	unsigned long flags;
#if KERNEL_VERSION(5, 4, 0) > LINUX_VERSION_CODE
	int val[8];
#else
	long val = 0L;
#endif

	spin_lock_irqsave(&ctx->lock, flags);

#if KERNEL_VERSION(5, 4, 0) > LINUX_VERSION_CODE
	val[0] = data & 1;
	val[1] = (data >> 1) & 1;
	val[2] = (data >> 2) & 1;
	val[3] = (data >> 3) & 1;
	val[4] = (data >> 4) & 1;
	val[5] = (data >> 5) & 1;
	val[6] = (data >> 6) & 1;
	val[7] = (data >> 7) & 1;
	gpiod_set_array_value(ctx->data->ndescs, ctx->data->desc, val);
#else
	val |= data;
	gpiod_set_array_value(ctx->data->ndescs, ctx->data->desc,
			      ctx->data->info, &val);
#endif

	spin_unlock_irqrestore(&ctx->lock, flags);
}

static unsigned char parport_gpio_read_control(struct parport *p)
{
	struct parport_gpio_ctx *ctx = p->private_data;
	unsigned char control;
	unsigned long flags;

	spin_lock_irqsave(&ctx->lock, flags);

	control = gpiod_get_value(ctx->control->desc[0]);
	control |= gpiod_get_value(ctx->control->desc[1]) << 1;
	control |= gpiod_get_value(ctx->control->desc[2]) << 2;
	control |= gpiod_get_value(ctx->control->desc[3]) << 3;

	spin_unlock_irqrestore(&ctx->lock, flags);

	return control;
}

static void parport_gpio_write_control(struct parport *p, unsigned char control)
{
	struct parport_gpio_ctx *ctx = p->private_data;
	unsigned long flags;
#if KERNEL_VERSION(5, 4, 0) > LINUX_VERSION_CODE
	int value[4];
#else
	long value = 0L;
#endif

	spin_lock_irqsave(&ctx->lock, flags);

#if KERNEL_VERSION(5, 4, 0) > LINUX_VERSION_CODE
	value[0] = control & 1; // ~nStrobe
	value[1] = (control >> 1) & 1; // ~nAutoLF
	value[2] = (control >> 2) & 1; // nInitialize
	value[3] = (control >> 3) & 1; // ~nSelect
	gpiod_set_array_value(ctx->control->ndescs, ctx->control->desc, value);
#else
	value |= control;
	gpiod_set_array_value(ctx->control->ndescs, ctx->control->desc,
			      ctx->control->info, &value);
#endif

	spin_unlock_irqrestore(&ctx->lock, flags);
}

static unsigned char parport_gpio_frob_control(struct parport *p,
					       unsigned char mask,
					       unsigned char val)
{
	struct parport_gpio_ctx *ctx = p->private_data;
	unsigned long flags;

	spin_lock_irqsave(&ctx->lock, flags);

	if ((mask & 1)) { // ~Strobe
		gpiod_set_value(ctx->control->desc[0], val & 1);
	}
	if ((mask & 2)) { // ~nAutoLF
		gpiod_set_value(ctx->control->desc[1], (val >> 1) & 1);
	}
	if ((mask & 4)) { // nInitialize
		gpiod_set_value(ctx->control->desc[2], (val >> 2) & 1);
	}
	if ((mask & 8)) { // ~nSelect
		gpiod_set_value(ctx->control->desc[3], (val >> 3) & 1);
	}

	spin_unlock_irqrestore(&ctx->lock, flags);

	return parport_gpio_read_control(p);
}

static unsigned char parport_gpio_read_status(struct parport *p)
{
	struct parport_gpio_ctx *ctx = p->private_data;
	unsigned char status;
	unsigned long flags;

	spin_lock_irqsave(&ctx->lock, flags);

	status = gpiod_get_value(ctx->status->desc[0]) << 3; // nError
	status |= gpiod_get_value(ctx->status->desc[1]) << 4; // Select
	status |= gpiod_get_value(ctx->status->desc[2]) << 5; // Paperout
	status |= gpiod_get_value(ctx->status->desc[3]) << 6; // nAck
	status |= gpiod_get_value(ctx->status->desc[4]) << 7; //~Busy

	spin_unlock_irqrestore(&ctx->lock, flags);

	return status;
}

static void parport_gpio_init_state(struct pardevice *d,
				    struct parport_state *s)
{
}
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

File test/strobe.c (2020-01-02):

// SPDX-License-Identifier: GPL-2.0-or-later

/* strobe - pulse specified pin for scope */

#include <stdio.h>
#include <sys/ioctl.h>
#include <linux/parport.h>
#include <linux/ppdev.h>
#include <fcntl.h>
#include <time.h>
#include <unistd.h>
#include <stdlib.h>
#include <stdarg.h>
#include <errno.h>
#include <string.h>

#define DEVICE_PATH "/dev/parport0"

void die (const char *fmt, ...)
{
    va_list ap;

    va_start (ap, fmt);
    (void)vfprintf (stderr, fmt, ap);
    va_end (ap);
    exit (1);
}

void say (const char *fmt, ...)
{
    va_list ap;

    va_start (ap, fmt);
    (void)vfprintf (stderr, fmt, ap);
    va_end (ap);
}

void usage (void)
{
    fprintf (stderr, "Usage: strobe pin\n");
    fprintf (stderr, "where pin is DATA0, DATA1, CONTROL0, CONTROL1...\n");
    exit (1);
}

/* measured 253khz in a tight loop on pi3 */
void strobe (int fd, const char *pin)
{
    unsigned char out;
    unsigned long request;
    int bit;
    int count;

    if (!strncmp (pin, "DATA", 4)) {
        bit = atoi (pin + 4);
        if (bit < 0 || bit > 7)
            usage ();
        request = PPWDATA;
    }
    else if (!strncmp (pin, "CONTROL", 7)) {
        bit = atoi (pin + 7);
        if (bit < 0 || bit > 4)
            usage ();
        request = PPFCONTROL;
    }
    else
        usage ();

    for (count = 0; ; count++) {
        if (request == PPWDATA) {
            unsigned char out = (count % 2) ? 0 : (1<<bit);

            if (ioctl (fd, request, &out) < 0)
                die ("ioctl PPWDATA: %s\n", strerror (errno));
        }
        else {
            struct ppdev_frob_struct frob = {
                .mask = 1<<bit,
                .val = (count % 2) ? 0 : (1<<bit),
            };
            if (ioctl (fd, request, &frob) < 0)
                die ("ioctl PPFCONTROL: %s\n", strerror (errno));
        }
    }
}

int main (int argc, char *argv[])
{
    int fd, mode, dir;
    const char *pin;
    int rc;

    if (argc != 2)
        usage ();
    pin = argv[1];

    fd = open (DEVICE_PATH, O_RDWR);
    if (fd < 0)
        die ("%s: %s\n", DEVICE_PATH, strerror (errno));
    if (ioctl (fd, PPCLAIM, NULL) < 0)
        die ("ioctl PPCLAIM: %s\n", strerror (errno));

    mode = IEEE1284_MODE_BYTE;
    if (ioctl (fd, PPSETMODE, &mode) < 0)
        die ("ioctl PPSETMODE IEEE1284_MODE_BYTE: %s\n", strerror (errno));

    dir = 0;
    if (ioctl (fd, PPDATADIR, &dir) < 0)
        die ("ioctl PPDATADIR 0 (out): %s\n", strerror (errno));

    strobe (fd, pin);

    if (ioctl (fd, PPRELEASE) < 0)
        die ("ioctl PPRELEASE: %s\n", strerror (errno));
    if (close(fd) < 0)
        die ("close %s: %s\n", DEVICE_PATH, strerror (errno));

   return rc;
}

/*
 * vi:tabstop=4 shiftwidth=4 expandtab
 */

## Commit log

2017-06-25 hardware_v1: add initial prototype hardware
    This is a pi HAT (not officially: no EEPROM, wrong size) that
    has a DB25 on it and three 74AHCT541 8-channel buffers for
    3V3/5V level conversion. Pi GPIOs are mapped directly to
    parallel port data, status, and control lines. It should be
    adequate for SPP mode.
    It's layed out as a single sided board since that's easier for
    me to prototype with for the first try.
    [parport.brd, parport.sch]
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2017-07-30 dts: add device tree overlay
    Add initial device tree overlay for parport-gpio module
    to identify and provide initial config for GPIO pins assigned
    to data, status, and control ports.
    The "compatible" name links the driver and the dts file.
    On the pi, after the compiled dtbo file is installed,
    add the following to /boot/config.txt:
    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
2017-07-30 driver: initial parport-gpio driver cut
    parport_sunbpp.c served as an example of a parport driver
    implemented as a "platform driver" linked to Open Firmware
    resource, similar to the device tree on the Pi.
2017-07-30 driver: pull in the rest of the parport stack
    Since the Pi Foundation isn't likely to configure the parport
    stack in their default kernel anytime soon, pull in the bits
    here so they can be built out of tree with the parport-gpio
    module, thus making it a bit easier to get started.
    insmod parport.ko
    insmod parport_gpio.ko
    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
2017-08-05 hardware_v1: status 10k pd -> 4.3k pu
    Change the 10K pulldowns to 4.3K pullups.
    4.7K is what would normally be used here but I had some
    803 4.3K's on hand.
    Place some vias for the pullups and also for the unrouted
    CONTROL3 line. Before we had a one sided board which is
    a bit easier to fab with the CNC. Place vias so it can
    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
    [parport.brd, parport.sch]
2017-08-05 hardware_v1: replace DB25 with 2x13 header
    It was a mistake to mount a DB25 directly on the adapter.
    Use a 26 pin header and then off the shelf header to DB25
    adapters can be used to suit the application.
    [parport.brd, parport.sch]
2017-08-06 hardware_v1: include DB-25 pin numbering on schematic
    [parport.sch]
2017-08-06 driver: fix NULL oops
    If CONFIG_PARPORT_NOT_PC is not defined and CONFIG_PARPORT_1284
    is defined, internal 1284 "daisy" probing causes a NULL pointer
    dereference (oops) at insmod of parport_gpio.ko.
    This is likely due to a conditional in parport.h that, if NOT_PC
    is undefined, hardwires operations to the PC versions, bypassing
    the operations table. I did not run down why the hardwired
    symbols seem not to be an obstacle at parport.ko load time.
    Fixes #1.
2017-08-06 driver: add parport.h
    Although the kernel build system finds parport.h in
    include/linux/parport.h when we build parport.ko out
    of tree, add it here since we're pretending to be
    standalone.
2017-08-06 driver: delete port on module unload
    Call parport_del_port() instead of parport_put_port()
    when the module is unloaded, so that parport0 can be
    reused if the module is re-loaded. Otherwise we get
    parport1, 2, and so on.
    Also, change printk code so the port number is displayed
    with the assigned GPIO pins e.g.
    parport0: data on gpio pins [22,23,24,10,25,9,8,11]
    parport0: status on gpio pins [18,17,4,3,2]
    parport0: control on gpio pins [26,19,6,13]
    Fixes #7
    [parport_gpio.c]
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2017-08-06 driver: fix polarity in parport_gpio_read_control()
    In parport_gpio_read_control(), it is necessary to invert
    some of the control bits that are supposed to be active low.
    [parport_gpio.c]
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2017-08-06 driver: optimize frob_control operation
    Write bits individually if present in the mask rather than
    doing it in bulk as if we were dealing with actual I/O ports.
    Fixes #5
    [parport_gpio.c]
2017-08-07 driver: stop using raw gpiod interface
    In the dts file expression <&gpio n m>, n is the pin and m
    is the polarity, not direction. If m=0, the pin is active
    high; if m=1, active low.
    Set all the pins active high and then stop using
    the "raw" gpiod interfaces to access them.
    Fixes #3
    [parport_gpio.c]
2017-08-07 driver: set polarity in dts not software
    Change the active low pins to active low in the device
    tree overlay, and then change the driver to stop inverting
    those pins in software.
    [parport_gpio.c]
2017-08-24 driver: pull in ppdev
    The ppdev module provides a user-space interface to
    a parallel port device, including raw. We can use it
    to build test programs.
    Again, RPi Foundation is not building parallel port
    related modules, so pull it in here for convenience.
2017-08-24 test/cableTest2: add simple ppdev based cable test
    Add a simple parallel port cable test that toggles
    the data lines from user space via ppdev.
    Credit: Dr. Andrew Greensted
    http://www.labbookpages.co.uk/electronics/parallelPort.html
2017-10-22 hardware_v2: new layout with SN74LVC161284
    [parport.brd, parport.sch]
2017-10-22 hardware_v2: fix drc errors, add silk title
    This version ordered from OSH Park (3 boards).
    [parport.brd, parport.sch]
2017-12-04 driver: support hd and dir pins for v2 hardware
    In the v2 hardware design, hd and dir are pins on the
    SN74LVC161284 19-bit bus interface that determine the
    drive mode (1=totem pole, 0=open drain) and data port
    direction (1=AtoB, 0=BtoA).
    If the device tree overlay defines them, initialize
    both pins to 1.
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2018-07-09 test: add walk test
    With LED on all data and control outputs, "wiggle" each
    bit to visually catch shorts and opens in the outputs.
    The status lines are all covered by the loop.c test so
    with this, we have a sanity check on all signals.
2018-07-09 driver: update some includes
    Problem: compilation errors with latest rpi kernel
    headers (1.20180703-1), in generic parport, ppdev, lp code.
    This really should be synced with upstream kernel sources,
    but an initial check didn't reveal any changes to the parport
    stuff. For now, adjust includes to avoid compilation errors.
2018-07-09 test: adjust loop test
    Uncomment the part of the test that was failing with initial
    hardware_v2 prototype.
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2019-04-27 driver/parport: move upstream copies to parport dir
    Problem: parport module code that the rpi foundation doesn't
    configure into their kernel, but which is required by parport-gpio,
    was copied into our repo. But it's not clear what's the new code
    and what's copied kernel code.
    Move the copied kernel code into the parport subdir.
2019-04-27 driver: add make check target that runs checkpatch
    Run the kernel style checker in response to 'make check'.
2019-04-27 driver: [style] reformat with clang-format
    Add .clang-format from source and run
    clang-format -i parport_gpio.c
    to automatically fix as many kernel style issues as
    possible in one go.
    [parport_gpio.c]
2019-04-27 driver: [style] fix malformed SPDX-License-Identifier
    Address checkpatch warning:
    WARNING: Missing or malformed SPDX-License-Identifier tag in line 1
    [parport_gpio.c]
2019-04-27 driver: [style] add missing blank line after decls
    WARNING: Missing a blank line after declarations
    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
    [parport_gpio.c]
2019-04-27 driver: [style] use __func__ not __FUNCTION__
    WARNING: __func__ should be used instead of gcc specific __FUNCTION__
    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
2019-04-27 driver: [style] separate assignment from conditional
    ERROR: do not use assignment in if condition
    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
    [parport_gpio.c]
2019-04-27 driver: [style] fix static init formatting
    ERROR: that open brace { should be on the previous line
    (I think clang-format just mangled this)
    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
    [parport_gpio.c]
2019-04-27 driver: [style] drop extra oom message
    WARNING: Possible unnecessary 'out of memory' message
    See also: https://lkml.org/lkml/2014/6/10/382
    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
2019-04-27 driver: [cleanup] use dev_() macros for printk
    Instead of using pr_{level} printk macros and prepending
    the device name, just use the dev_{level} macros.
2019-04-27 README.md: update console output
    Switching to the dev_{level} printk macros causes some
    minor changes in the expeced console output, so update
    the README.md example output.
2019-08-04 drivers/parport: update source to track raspbian
    Problem: parport code fails to compile after raspbian update
    to 4.19.57-v7+ kernel.
    Update parport code that we copied into this project from
    the kernel source, needed until pi kernel maintainers enable
    the parallel port code in their configuration (not very likely).
    Code copied from master branch of:
    https://github.com/raspberrypi/linux
    commit: dee4361
    Fixes #21.
2019-08-04 driver/scripts: update kernel checkpatch script
    Pull in checkpatch script from latest raspbian kernel,
    in case it is tracking style changes we must follow or
    is capable of finding new problems.
    It runs clean at the time of this commit.
    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
2020-01-02 hardware_v3: rework v2 in KiCAD
    Create a new hardware version with the following changes
    1) Use KiCAD instead of Eagle so that other people can
    more easily modify/remix.
    2) Add HAT EEPROM to conform to Pi Foundation specs
    3) OSHW logo on board
    After I sent this to OSHPARK I realized I omitted the
    bypass cap that v2 had on the buffer chip. Board works,
    so I'm assuming it's not a big deal.
    Used the Pi HAT template included with KiCAD for the
    board outline, Pi connector placement, and EEPROM.
    [pi-parport.kicad_pcb, pi-parport.sch]
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2020-01-02 README.md: update for hardware version 3
    Made the following changes:
    - drop the sbig details
    - add a "what works" section
    - expand info on drivers
    - add build-essential to prereqs list
    - mention the (measured) max bit bang toggle rate
    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
2020-01-02 README.md: move old versions to hardware_old
    [parport.brd, parport.sch]
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2020-01-03 eeprom: add notes and Makefile to flash EEPROM
    Verify that the EEPROM hardware works by flashing a
    board identity in there.
    Fixes #26
2020-03-12 hardware_v3: add BOM manufacturer part numbers
    [pi-parport.sch]
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2020-03-12 hardware_v3: also add package, description, notes fields for BOM
    [pi-parport.sch]
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2020-03-13 hardware_v3: fix BOM table heading
2020-06-20 driver: skip parport if KERNEL_HAS_PARPORT defined
2020-07-26 Rearrange hardware repo structure.
    [parport.brd, parport.sch, pi-parport.kicad_pcb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]
2020-07-26 Add hardware v4.
    [pi-parport.kicad_pcb, pi-parport.sch]
2020-07-26 hardware_v4: add bypass capacitors, reroute traces
    Do not route trace under resistor R5. Move U2 upward to facilitate
    rerouting this trace without adding more vias.
    Also make sure footprints between schematic and PCB are in sync.
    Update BOM with new parts.
    Hardware version needs to be bumped due to PCB changes. Version numbers
    in schematic and PCB source changed, new files will need to be generated
    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
    [pi-parport.kicad_pcb, pi-parport.sch]
2020-07-26 hardware: reroute another under-resistor trace, other cleanup
    Fix board edge outline that was just barely not closed.
    Fix overlapping courtyards in resistors next to U1.
    Move obscured silkscreen reference R4.
    Cleanup one tiny trace left over from rerouting.
    Change version to v4 in BOM.md.
    [pi-parport.kicad_pcb]
2020-07-26 hardware: restructure directories for version 4, update READMEs
    [pi-parport.kicad_pcb, pi-parport.sch]
2020-07-26 hardware: move silkscreen ref to better location
    [pi-parport.kicad_pcb]
2020-08-11 hardware: BOM improvements/fixes.
    * Fix capacitor quantity in v4.
    * SN74LVC161284DLR Digi-Key part number: cut tape packaging
    discontinued at Digi-Key, use tube packaging instead.
    * Fix 40-pin and 26-pin headers, accidentally picked 2 mm pitch parts
    instead of 2.54 mm pitch parts.
    [pi-parport.sch]
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2020-10-23 driver: Forwards and backwards compatibility with Linux versions.
    Also make corresponding improvements to the READMEs.
    Fix a few checkpatch.pl warnings recently introduced, while at the same
    time introducing four checkpatch.pl warnings due to conditional
    compilation on the Linux version.
    [parport_gpio.c]
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2021-01-05 driver, eeprom: Fix driver install issue, note on i2c-dev for EEPROM.
    Also clarify which are autoloaded, and fix spelling error. Also note
    that the ppdev module is required to run the tests.
2021-01-05 README: point to v4 board + BOM, not v3
    Problem: the top level README.md still points to the v3 board
    on oshpark.
    Change it to point to the v4 board, and update the BOM reference
    to v4 as well.
2021-01-06 ci: invoke pr-validator on PRs
    Add a 'main' github workflow containing one 'job',
    that validates PRs, ensuring that:
    - commit messages conform to line length recommendations
    - commit subjects don't include "fixup" or "squash"
    - there are no merge commits
    The validator script was shared from:
    https://github.com/flux-framework/pr-validator
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2021-11-10 Update README.md
    https://forum.kicad.info/t/warning-avoid-all-links-to-kicad-pcb-org-use-kicad-org/31521
2021-11-12 ci: load the driver
    Problem: CI does not catch errors that occur when the
    driver is loaded.
    Add a test that builds the driver against the running kernel
    and loads it.
2021-11-14 driver: don't call MODULE_SUPPORTED_DEVICE
    Problem: compliation fails with linux-5.13
    parport_gpio.c:448:25: error: expected declaration specifiers or ‘...’ before string constant
    448 | MODULE_SUPPORTED_DEVICE("Raspberry Pi GPIO Parallel Port HAT");
    | ^~~~~~~~~~~~~~~~~~~~~~~~~~~~~~~~~~~~~
    Stop using the MODULE_SUPPORTED_DEVICE macro, which was removed by
    torvalds/linux@6417f03132a6952cd17ddd8eaddbac92b61b17e0
    [parport_gpio.c]
2021-11-14 driver/parport: sync with linux-5.10
    Problem: vendored copy of parport code no longer compiles
    on raspbian kernel 5.10.63-v7+ due to kernel API changes.
    Pull in the latest copy of parport source from linux-5.10.
    There are no local modifications.
2024-09-01 v5: start from kicad 8 HAT template
    Problem: earlier versions of the board lack HAT nuances.
    Start a v5 project from the kicad 8 HAT template.
    The template board includes:
    - cutouts for camera FPC cable
    - outline that handles SMT 40-pin header
    This commit changes nothing from the template.
    [hat.kicad_pcb, hat.kicad_sch]
2024-09-01 v5: update page settings
    Problem: template pages are A4 size and have have boiler plate
    metadata.
    Switch to U.S. letter size and update page metadata with project
    specific info.
    [hat.kicad_pcb, hat.kicad_sch]
2024-09-17 v5: import/reimplement parport design on template
    Problem: template board is still blank.
    Adjust board edge to handle SMT header and add cutout for pi5 camera/
    display FFC connectors. For GPIO connector, use existing kicad 8 Harwin
    M20 series footprint but adjust the pinout for top of board pi GPIO,
    and adjust position since centroid moved from THT pin 1 to SMT centroid.
    Add keepout for pi5 PoE like the existing one for pi4.
    Import the SN74LVC16128 symbol from the v4 board. Orient the chip
    as before for best routing but aim for tighter traces this time.
    Add bypass caps to all power inputs for good measure. Chip capacitors
    and resistors are shrunk from 0805 to 0603 in this revision. All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
    [M20-7812045.step, PRT-14417.step, hat.kicad_pcb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]
2024-09-21 testsuite: add make check target to hardware/v5
    Problem: running ERC/DRC requires the kicad GUI.
    Add scripts that use the version 8 kicad-cli to run ERC/DRC on the
    command line and drive them with a 'make check' target in hardware/v5.
2024-09-21 ci: add github action to check v5 ERC/DRC
    Problem: new PR's that change board design files should be
    automatically checked.
2024-09-21 ci: update checkout action to v4 to silence warnings
    Problem: github issues warnings when it runs our ci:
    The following actions uses node12 which is deprecated and will
    be forced to run on node16: actions/checkout@v2.
    Switch to v4.
2024-09-22 v5: add BOM data needed for JLCPCB assembly
    Problem: component metadata is not in a form that could be sent
    out for assembly.
    Add BOM fields recommended for JLCPCB assembly[1] and fill in.
    [1] https://jlcpcb.com/help/article/How-to-generate-the-BOM-and-Centroid-file-from-KiCAD
    [hat.kicad_sch]
2024-09-22 build: add script to generate BOM csv file
    Problem: we need a csv file to send to the board assembly house.
    Add a script to generate it and a Makefile target for the v5 board.
2024-09-22 build: add script to generate pos csv file
    Problem: we need a pick and place file to send to the board
    assembly house.
    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
2024-09-22 build: add script to generate gerbers
    Problem: we need gerbers for the fab house.
    Add a script to generate gerbers as a zip file.
    Add a Makefile target for the v5 board.
2024-09-22 v5: build cam.zip, bom.csv, and ops.csv by default
    Problem: nothing gets built when you type 'make' in the v5 directory
    Add all the manufacturing files to the default make target.
2024-10-03 v5: update BOM with LCSC parts
    Problem: JLC PCBA is faster/cheaper if parts can be sourced
    from LCSC in China.
    Based on input from a JLC engineer, update the BOM with LCSC parts.
    U2 is unavailable and will have to be ordered by them from Mouser.
    Note the Harwin M20-7812045 2x20 SMT header is $3.31 ea in Qty 11
    (Mouser), but the equivalent Liansheng FH-00339 is $0.40 ea in Qty 10.
    Update BOM.
    [hat.kicad_sch]
2024-10-03 v5: enlarge 2x20 header alignment holes
    Problem: 2x20 header alignment holes for Harwin M20 are 1.8mm dia.
    The LCSC replacement requires 2mm dia alignment holes.
    Update footprint and board.
    [hat.kicad_pcb]
2024-10-03 v5: switch J4 to SMT
    Problem: the J4 1x3 header is a through hole part that is marked
    "do not place" so it can be installed by hand.
    Switch J4 to an SMT footprint and uncheck DNP.
    Adjust board routing.
    Add a LCSC part number to the BOM.
    [hat.kicad_pcb, hat.kicad_sch]
2024-10-04 v5: put URL on the front of the board
    Problem: URL for design files/software is not visible when
    the board is installed.
    Move to front of board.
    [hat.kicad_pcb]
2024-10-04 v5: remove some DRC exclusions
    Problem: DCR excludes "holes inside courtyard" for some reason.
    These checks pass so may as well enable them.
2024-10-04 v5: add hardware license to silkscreen
    Problem: on the back of the baord we have a copyright notice
    but not a license designator.
    Add the license.
    [hat.kicad_pcb]
2024-10-06 v5: adjust board layout for easy rework
    Problem: J4 is too close to U2 to permit easy rework.
    Move it away from U2 a bit and reroute.
    [hat.kicad_pcb]
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

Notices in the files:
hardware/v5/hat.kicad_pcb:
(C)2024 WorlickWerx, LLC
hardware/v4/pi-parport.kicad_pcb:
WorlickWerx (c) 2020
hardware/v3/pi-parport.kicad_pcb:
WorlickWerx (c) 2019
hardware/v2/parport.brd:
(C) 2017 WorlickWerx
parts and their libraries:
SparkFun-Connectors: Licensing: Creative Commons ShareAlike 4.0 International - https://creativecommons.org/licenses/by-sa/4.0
